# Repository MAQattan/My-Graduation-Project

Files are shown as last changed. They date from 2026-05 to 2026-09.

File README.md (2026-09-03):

# Design and Performance Analysis of a Grid-Tied Solar PV System








A highly optimized engineering design and dynamic performance analysis of a **23.40 kWp grid-tied rooftop solar photovoltaic system**. Designed for a critical banking facility in Aleppo, Syria, this project resolves the structural and electrical matching challenges of urban solar integration under complex spatial constraints.

## 1. Overview / Abstract

This repository contains the full engineering documentation, AutoCAD layouts, Single Line Diagrams (SLD), and PVsyst simulation models for a **23.40 kWp grid-connected rooftop solar PV system** designed to meet the critical loads of a commercial banking facility in Aleppo, Syria. By integrating state-of-the-art **N-Type Hybrid Passivated Back Contact (HPBC)** modules with a **Huawei SUN2000-25KTL-M5 Smart Inverter**, the system maximizes spatial power density on a highly constrained urban roof. Detailed dynamic simulations executed in **PVsyst v7.2.21** demonstrate an exceptional annual yield of **44.02 MWh** and an industry-benchmark **Performance Ratio (PR) of 89.30%**.

## 2. Problem Statement

Commercial and financial facilities in dense urban environments require highly reliable power supplies but are severely limited by **spatial constraints** and complex **architectural obstructions** on rooftops. The primary engineering challenges addressed in this design include:

- **The Rooftop Spatial Bottleneck:** Traditional inter-row spacing layouts designed to avoid mutual shading typically waste **40% to 50% of the usable rooftop area**, capping the maximum allowable installed capacity.
- **Localized Architectural Obstructions:** Permanent structures on the bank's roof—such as a **2.5-meter-high stairwell** and a **1.3-meter-high centralized AC unit**—impose complex, dynamic shadows during peak sun hours. Unmitigated shading triggers severe **mismatch losses** and high risks of localized **hotspot formation**, which degrade module life and threaten system safety.
- **Static Design Limitations:** Standard static hand calculations are insufficient for modeling time-varying, three-dimensional shading profiles and predicting real-world system behavior under extreme seasonal temperature fluctuations.

## 3. Methodology & Software Used

The project adopts a rigorous **five-stage Integrated Engineering Design Cycle**:

```mermaid
flowchart LR
    A["<b>1. Geo-Climatic Study</b><br/><i>(Global Solar Atlas)</i>"] --> B["<b>2. Spatial Design & Shading</b><br/><i>(AutoCAD 3D)</i>"]
    B --> C["<b>3. Thermal Sizing &<br/>Electrical Matching</b>"]
    C --> D["<b>Main DC/AC Cable<br/>Voltage Drop Analysis</b>"]
    D --> E["<b>4. Selectivity-Based<br/>Protections & SLD</b>"]
    E --> F["<b>5. PVsyst Digital Twin<br/>& Dynamic Simulation</b>"]
```

### Software Toolchain & Standards Conformed:

- **Meteonorm 8.0 & Global Solar Atlas:** Used to extract high-resolution, long-term meteorological time series (2006–2013) and geographical solar parameters for Aleppo.
- **AutoCAD:** Utilized for high-precision 2D architectural mapping, structural layouts, and 3D geometric shadow path modeling.
- **PVsyst v7.2.21:** Employed to construct a high-fidelity **Digital Twin** of the system, run dynamic simulations, optimize the DC/AC ratio, and evaluate the final annual system loss tree.
- **IEC 60364-7-712 & EN 50618:** Applied to govern the safety, selection, sizing, and protection of the DC/AC electrical distribution system.
- **IEEE 80:** Followed to design and verify the safety of the low-impedance earthing grid under fault currents.

## 4. System Architecture & Design Details

### 4.1. Geo-Climatic Parameters (Aleppo, Syria)

- **Coordinates:** Latitude: ${} 36.20^\circ\text{ N}$, Longitude:  $37.14^\circ\text{ E}$, Altitude: $379\text{ m}$.
- **Solar Resource Data:** Global Horizontal Irradiation (GHI) = $1930.4\text{ kWh/m}^2/\text{year}$. Global Incident Irradiation on Optimized Tilt ($31^\circ$) (GTI) = $2184.8\text{ kWh/m}^2/\text{year}$.
- **Optimum Tilt & Azimuth:** $31^\circ$ Fixed Plane tilted due South ($0^\circ$ Azimuth).
- **Annual Peak Sun Hours (PSH):** $5.98\text{ hours/day}$.

### 4.2. Spatial Engineering: Terraced Mounting & Shading Geometry

To overcome the urban rooftop spatial bottleneck, a **Terraced (Staircase) Mounting Structure** was engineered. This design aligns the trailing edge of each row with the leading edge of the subsequent row, reducing the inter-row pitch distance to zero ($D = 0$). By raising the subsequent rows step-by-step, the structural design completely neutralizes inter-row mutual shading while achieving an outstanding **areal power density of 119.59 W/m²** over a net exploited rooftop area of **195.67 m²**.

To verify that localized shadows from the AC unit (Height $H = 1.3\text{ m}$) and the Stairwell (Height $H_{stair} = 2.5\text{ m}$) do not impact the active cells of adjacent strings, a rigorous **3D trigonometric verification** was executed for the worst-case scenario (Winter Solstice, Dec 21, 9:00 AM):
$$\text{Minimum Spacing Equation: } D_{min} = D \times \cos(\psi_{Correction})$$
$$\text{Lateral Shading Spacing: } D_{Lat} = D \times \sin(\psi_{Correction})$$

At the critical intersection point on December 21, the maximum vertical shadow height ($H_{shadow}$) from the stairwell was calculated at $0.763\text{ m}$. Because the physical support frame raises the adjacent active module area to a minimum height of $1.173\text{ m}$:

$$H_{shadow}\ (0.763\text{ m}) < H_{collector_min}\ (1.173\text{ m})$$

This confirms the shadow passes entirely below the active cells, eliminating hotspot risks and seasonal mismatch losses.

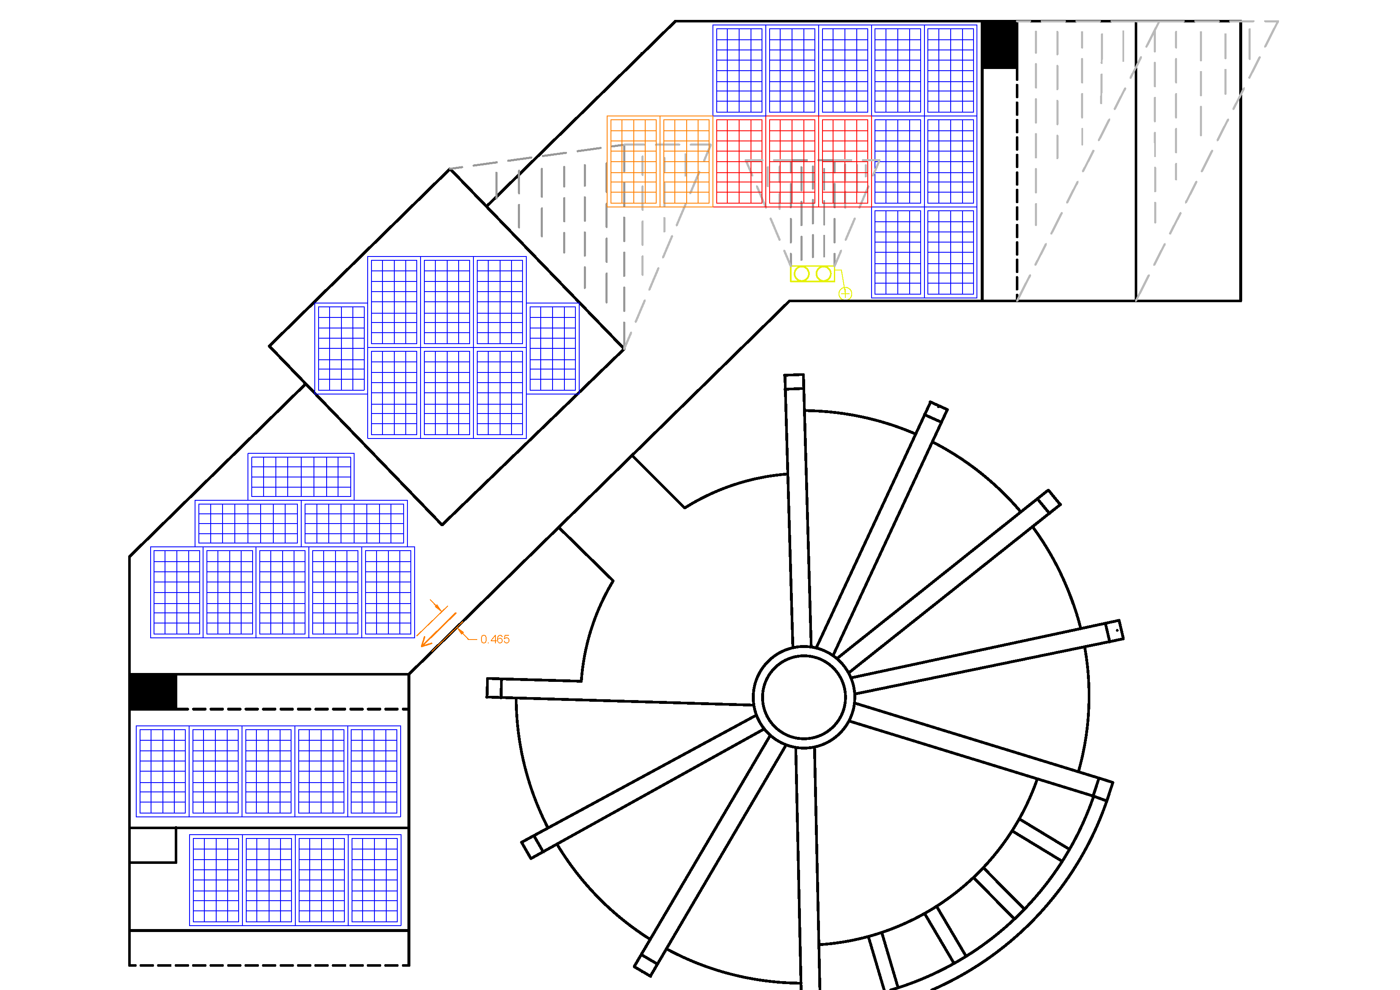
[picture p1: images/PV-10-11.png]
AutoCAD drawing showing shadow projections for the stairwell and the central air conditioning unit.


### 4.3. Photovoltaic Module Specifications

The design utilizes **39 units** of high-efficiency **LONGi Hi-MO 6 Scientist LR5-72HTH-600M** modules featuring N-Type Hybrid Passivated Back Contact (HPBC) technology:

| Electrical Parameter | Symbol | STC Value ($1000\text{ W/m}^2, 25^\circ\text{C}$)  |
| :--- | :--- | :--- |
| Nominal Power | $P_{max}$ | $600\text{ Wp}$ |
| Open-Circuit Voltage | $V_{oc}$ | $52.81\text{ V}$ |
| Optimum Operating Voltage | $V_{mp}$ | $44.66\text{ V}$ |
| Optimum Operating Current | $I_{mp}$ | $13.44\text{ A}$ |
| Short-Circuit Current | $I_{sc}$ | $14.46\text{ A}$ |
| Module Efficiency | $\eta$ | ${} 23.20\%$ |
| Temperature Coefficient of $P_{max}$ | $\gamma_{P}$ | $-0.290\%/^\circ\text{C}$ |

### 4.4. Inverter Selection & DC/AC loading

The system is managed by a three-phase **Huawei SUN2000-25KTL-M5 Smart Inverter**:

- **Rated AC Power:** $25.00\text{ kW}$.
- **DC/AC Loading Ratio (R):** $23.40\text{ kWp} \div 25.00\text{ kW} = 0.936$. This ratio ensures the inverter operates in its peak efficiency window (${} 40\%$ to ${} 80\%$ load) for maximum daily hours.
- **MPPT Inputs:** 2 independent MPPT trackers with a wide operating voltage range ($200\text{ V} - 1000\text{ V}$).
- **Integrated Safety Features:** AI-powered Arc Fault Circuit Interrupter (AFCI) for instant arc detection, Type II DC and AC surge arresters.

### 4.5. Dynamic String Sizing & MPPT Mapping

Dynamic temperature-corrected calculations were performed to establish safe open-circuit voltages at $0^\circ\text{C}$ (extreme winter) and optimum operating voltages at $60^\circ\text{C}$ (extreme summer):

- $V_{oc}$ at $0^\circ\text{C}$ = $56.64\text{ V}$ per module.
- $V_{mp}$ at $60^\circ\text{C}$ = $40.12\text{ V}$ per module.

$$N_{ideal} = \frac{V_{rated_inverter}}{V_{mp_STC}} = \frac{600\text{ V}}{44.66\text{ V}} \approx 13\text{ Modules in Series}$$

The string layout consists of **3 Strings of 13 Modules** each. To isolate local shading losses, a **Multi-MPPT mapping strategy** is implemented:

- **MPPT 1:** 2 strings in parallel (26 modules total) placed in unshaded, safe zones (center and west of the roof).
    - _Max operating current:_ $2 \times 13.44\text{ A} = 26.88\text{ A} \le 30.00\text{ A}$ (Inverter limit).
- **MPPT 2:** 1 string (13 modules) placed in the eastern zone, which experiences temporary lateral shadows from the stairwell. This prevents shading losses on the eastern string from dragging down the performance of the unshaded strings.

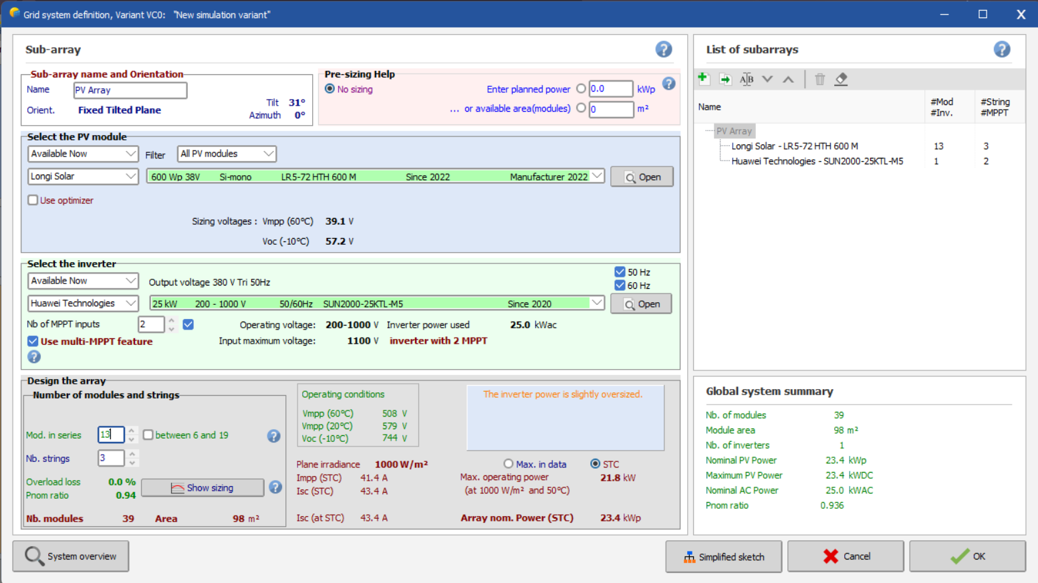
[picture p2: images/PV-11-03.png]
Configuring components and string layout in PVsyst


### 4.6. Cable Sizing, Protections & Grounding Grid

- **DC Cabling:** Specialty solar copper cables conforming to **EN 50618** (4 mm² cross-section). At $45^\circ\text{C}$ ambient, the derated ampacity ($I_{allowable} = 33.37\text{ A}$) easily exceeds the design current ($I_{dc_max} = 18.075\text{ A}$). The total DC voltage drop is optimized at **${} 0.763\%$**, well below the academic ${} 1\%$ limit.
- **AC Cabling:** Low-voltage $4 \times 16\text{ mm}^2\text{ Cu/XLPE/PVC}$ cable (El Sewedy Cables). The derated ampacity of $85.26\text{ A}$ safely coordinates with the protective MCB. The AC voltage drop over a 30m run is kept at **${} 0.717\%$**.
- **Protections (Selectivity-Based Coordination):**
    - _String Fuses:_ $25\text{ A}$, $1000\text{ Vdc}$, gPV class (IEC 60269-6) protecting modules from reverse fault currents.
    - _DC Isolator:_ $32\text{ A}$, $1000\text{ Vdc}$, 2-pole load-break switch.
    - _Inverter Output MCB:_ $50\text{ A}$ nominal, 4-pole, Curve C, $10\text{ kA}$ breaking capacity.
    - _Main Bank Circuit Breaker:_ $63\text{ A}$, 4-pole MCCB, $\ge 25\text{ kA}$ breaking capacity.
- **Earthing Grid (IEEE 80 & Dwight’s Formula):** Designed for a target resistance of $R_e \le 3.98\ \Omega$ ($< 5\ \Omega$ standard code). The grid consists of **10 vertical flemish-copper-clad steel rods** (Length $L = 2.5\text{ m}$, Diameter $d = 16\text{ mm}$) spaced 5m apart, buried at 0.8m, and interconnected with a $50\text{ mm}^2$ bare copper conductor.

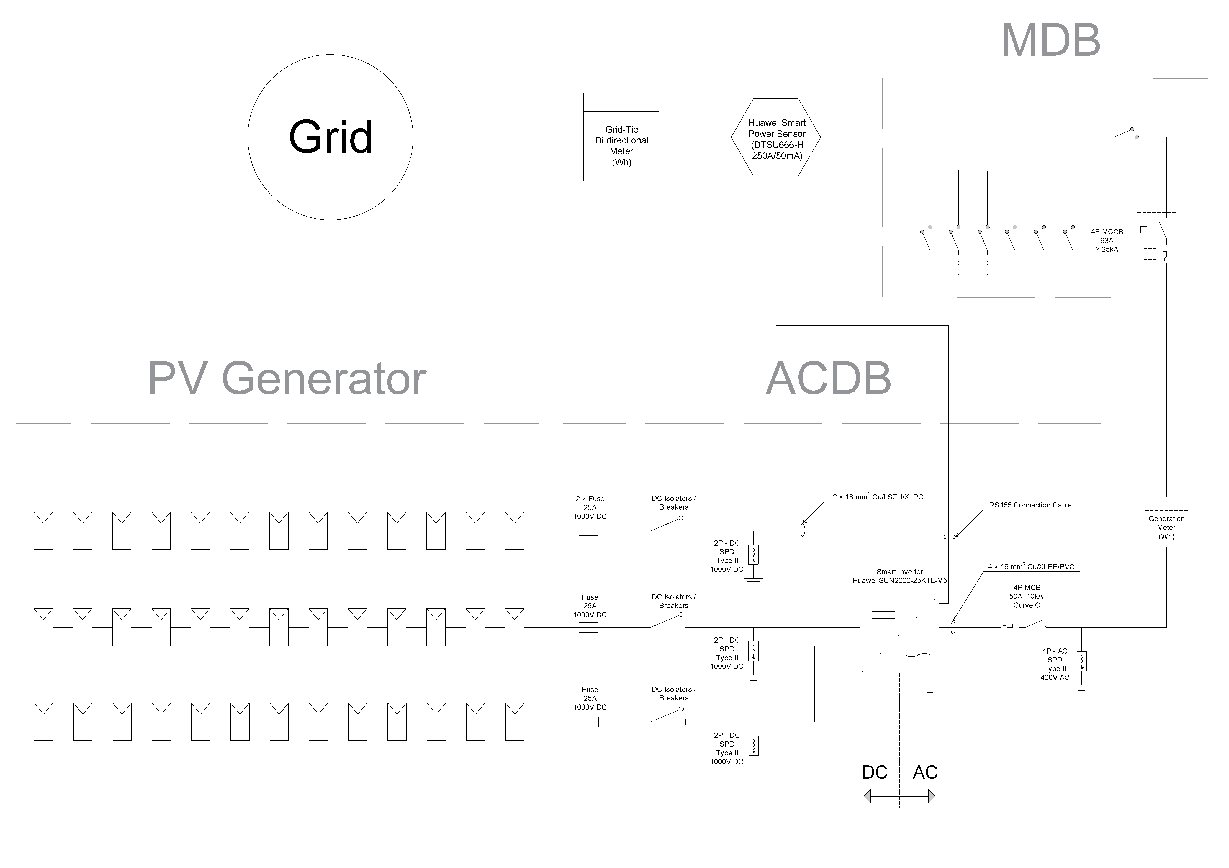
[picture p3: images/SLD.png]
Single line diagram

> **[📄 Click here to download or view the complete single-line diagram in high-resolution PDF format.](images/SLD.pdf)**

### 4.7. Bill of Materials (BOM)

The following table summarizes the primary structural and electrical equipment selected for this grid-tied installation:

|Item|Component|Technical Specification|Proposed Manufacturer|Qty|Unit|
|:-:|:--|:--|:-:|:-:|:-:|
|**1**|PV Modules|N-Type HPBC, 600 Wp, 23.2% Efficiency, LR5-72HTH-600M|LONGi Solar|39|Pcs|
|**2**|Grid-Tied Inverter|25 kW AC rated, 2 MPPTs, SUN2000-25KTL-M5|Huawei|1|Unit|
|**3**|DC String Fuses|25 A, 1000 Vdc, gPV class, 10x38 mm|Schneider / ABB|6|Pcs|
|**4**|DC MCB/Isolators|2-Pole, 32 A, 1000 Vdc|Schneider / ABB|3|Pcs|
|**5**|DC Combiner Box|IP66 Enclosure with DIN rail, UV-Stabilized Polycarbonate|Hensel|1|Unit|
|**6**|Solar DC Cable|4 mm² cross-section, tinned copper, double-insulated XLPO|KBE / Prysmian|300|Meters|
|**7**|AC Circuit Breaker|4-Pole, 50 A, Curve C, 10 kA|Schneider / ABB|1|Pcs|
|**8**|Main AC Cable|4 x 16 mm² Cu/XLPE/PVC, 0.6/1 kV|El Sewedy Cables|50|Meters|
|**9**|Smart Power Sensor|3-Phase, DTSU666-H 250A/50mA, Modbus-RTU|Huawei|1|Unit|
|**10**|Mounting Structure|Terraced / Stepped design, Anodized Al Rail, HDG Steel frame|Custom Structural|1|Lot|
|**11**|Earthing System|10 solid copper rods, 50 mm² bare copper cable, inspection pit|Custom Electrical|1|Lot|

## 5. Results & Analysis

The simulated performance metrics of the grid-tied system:

### 📊 PVsyst Simulation Yield Indicators (Aleppo Site)

| Metric | Symbol | Value | Unit |
| :--- | :---: | :---: | :---: |
| **Annual Energy Injected** | $E_{\text{Grid}}$ | **44.02**  | MWh/year |
| **Specific System Production** | — |  **1881**  | kWh/kWp/year |
| **System Performance Ratio** | $PR$ | **89.30%** | — |
| **Avg. Daily Useful Energy** | $Y_f$ |  **5.15**  | kWh/kWp/day  |

### 5.1. Energy Yield and PR Dynamics

- **Annual Energy Yield ($E_{Grid}$):** The system feeds **$44.02\text{ MWh/year}$** of clean power into the bank's local distribution network and the public utility grid.
- **Performance Ratio (PR):** Achieves an annual **${} 89.30\%$ PR**. Under cold, clear sky winter conditions (January), the system hits peak performance with a **${} 94.80\%$ PR** due to reduced module thermal degradation. Conversely, high summer temperatures (July) degrade $V_{mp}$, driving the PR down to **${} 85.80\%$**.

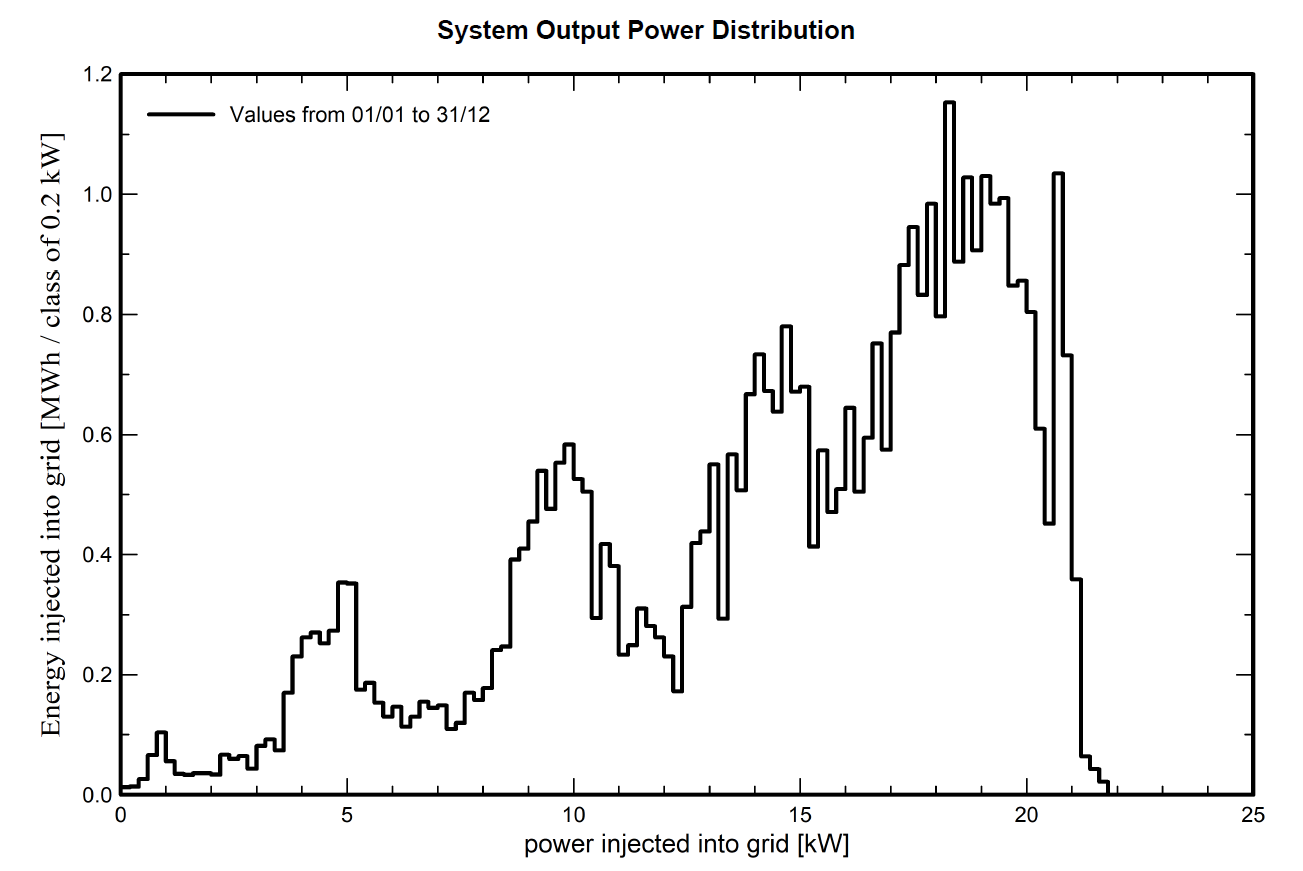
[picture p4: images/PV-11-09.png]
System Output Power Distribution


### 5.2. Daily Normalized Performance

- **Daily Useful Energy ($Y_f$):** Evaluated at **$5.15\text{ kWh/kWp/day}$**, meaning each installed kWp yields over 5 hours of full-load equivalent production daily.
- **Collection Losses ($L_c$):** **$0.52\text{ kWh/kWp/day}$** is lost due to thermal module degradation, minor dust buildup, and wiring resistance.
- **System Losses ($L_s$):** Just **$0.09\text{ kWh/kWp/day}$** is lost during inverter DC-to-AC conversion.

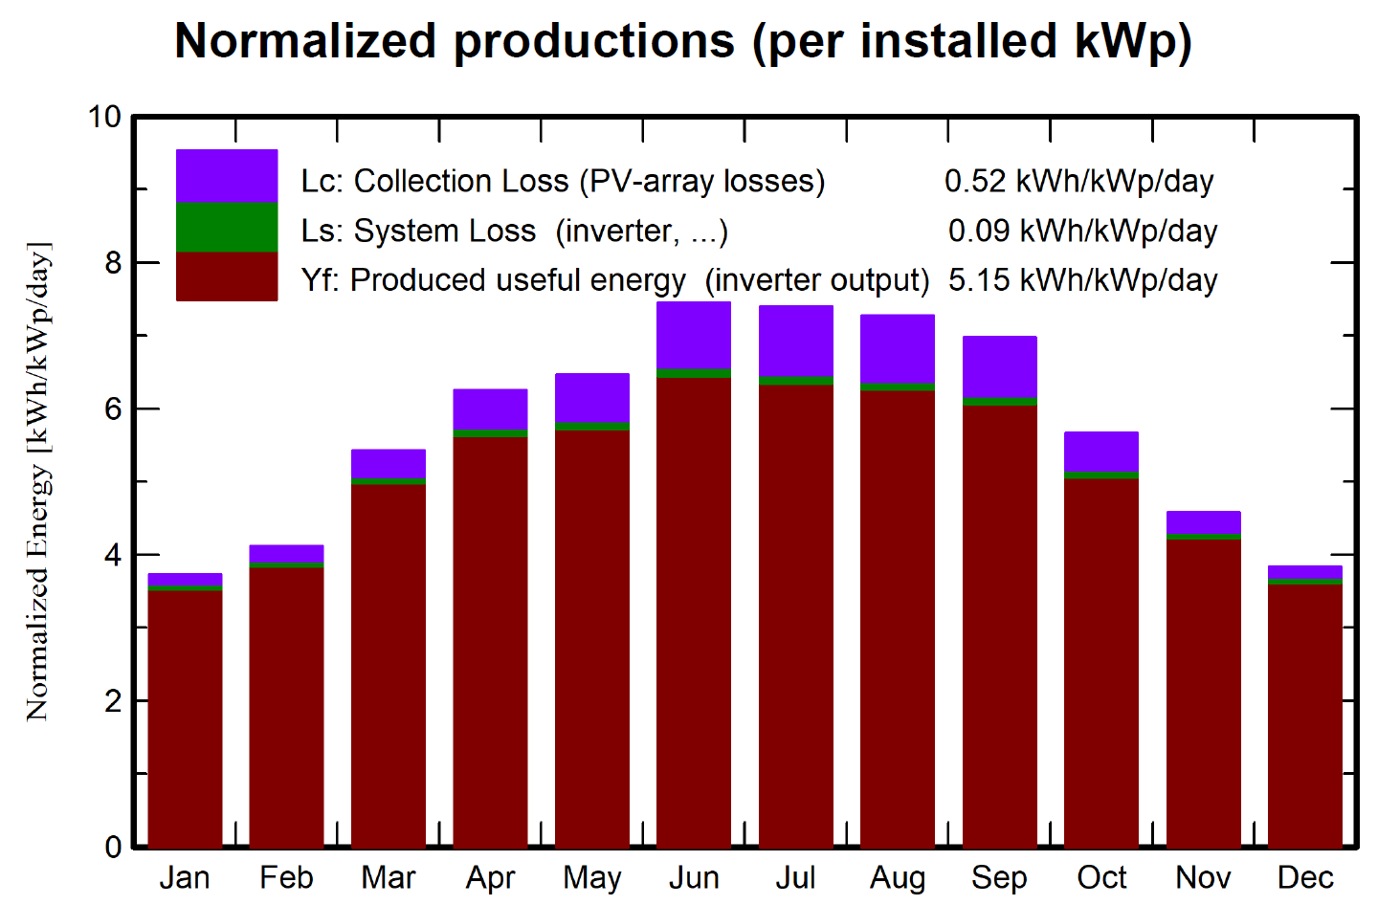
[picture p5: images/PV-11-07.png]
Normalized productions


### 5.3. PVsyst Loss Diagram Breakdown

The complete transformation chain from raw irradiance to useful grid energy, as simulated by the PVsyst loss model:

1. **Global Horizontal Irradiation (GHI):** $1862\text{ kWh/m}^2$.
2. **Tilt Transposition Gain (to $31^\circ$):** **${} +13.10\%$**.
3. **Effective Global Incident Radiation (GTI):** $2071\text{ kWh/m}^2$.
4. **Nominal PV Array Energy (at STC):** $48.63\text{ MWh}$.
5. **PV Loss due to Temperature:** **${} -4.64\%$** (highly stabilized by LONGi's low thermal coefficient).
6. **Mismatch Loss (modules and strings):** **${} -2.10\%$** (mitigated successfully by the parallel Multi-MPPT mapping layout).
7. **Ohmic Wiring Loss (DC cabling):** **${} -0.73\%$** (validating the selection of the $4\text{ mm}^2$ solar cable cross-section).
8. **Inverter Conversion Efficiency Loss:** **${} -1.72\%$** (driven by the high ${} 98.40\%$ peak efficiency of the Huawei unit).
9. **Final Energy Injected to Grid:** **$44.02\text{ MWh}$**.

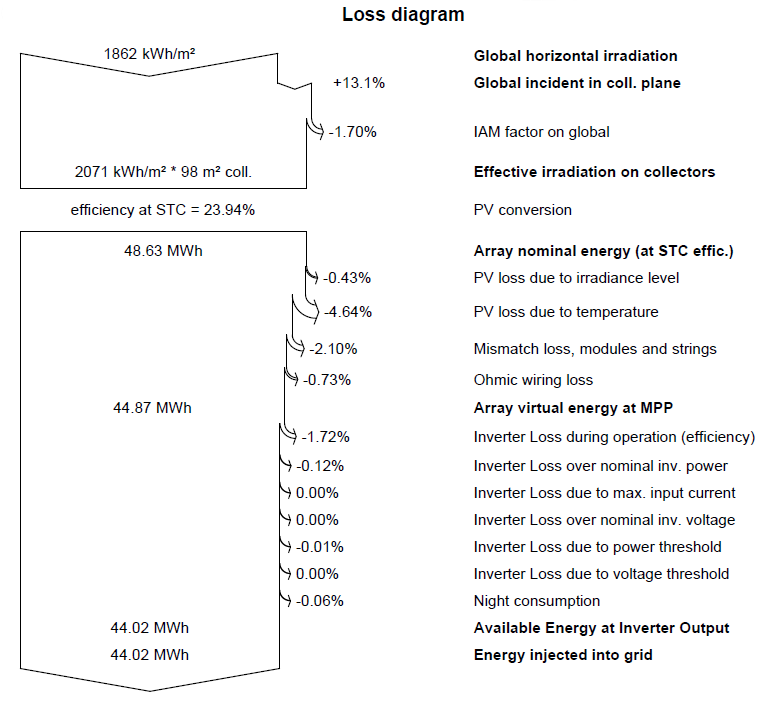
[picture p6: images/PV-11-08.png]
Loss Diagram


## 6. Conclusion & Future Work

### 6.1. Design Accomplishments

- **Spatial Optimization:** The custom **Terraced Mounting** structure bypassed the typical urban spacing penalty, reclaiming **${} 40\%$ to ${} 50\%$ of lost rooftop space** to establish an excellent spatial power density of **$119.59\text{ W/m}^2$**.
- **Electrical Selectivity & Isolation:** Isolating the shade-affected eastern string on a dedicated MPPT channel successfully confined mismatch losses to just **${} 2.10\%$**, ensuring the system maintains a benchmark **${} 89.30\%$ PR**.
- **Thermal & Compliance Success:** The tinned copper solar and AC cabling layouts kept voltage drop parameters below **${} 0.85\%$**, ensuring complete compliance with standard code guidelines.

### 6.2. Future Work Recommendations

- **Hybrid Configuration (Battery Storage Integration):** To prevent grid-tie dropouts under regional utility blackout events, integrating a hybrid battery backup loop would secure continuous supply for critical banking operations.
- **Bifacial Module Upgrades:** If roof reflectivity is improved by applying a white reflective coating to elevate the current $0.20$ albedo, upgrading to bifacial modules would enable up to ${} 5\% - 10\%$ additional back-side generation gains.

## 7. Project Metadata

- **Student/Author:** Muhammad Ali Qattan (محمد علي قطان)
- **Academic Institution:** University of Aleppo, Faculty of Electrical and Electronic Engineering, Department of Electrical Power Engineering (2026 CE / 1448 AH)
- **Project Supervisor:** Dr. Karima Sukkar (د. كريمة سكر)

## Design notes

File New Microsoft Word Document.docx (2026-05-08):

جميل جدًا — فكرة منظومة شمسية مرتبطة بالشبكة وتحليل أدائها باستخدام ETAP عملية، قابلة للتنفيذ خلال فصل دراسي، وممتازة كـ مشروع تخرج (جمع بين جانب تطبيقي ومراجع عملية). سأعطيك خطة مفصلة خطوة-بخطوة تقدر تطبّقها بسرعة، مع مخرجات واضحة تعرضها للمشرف وللجنة.

1) هدف المشروع (مختصر وواضح)

تحليل تصميم منظومة طاقة شمسية (PV) متصلة بالشبكة لموقع محدد، وتقييم أداء المنظومة كهربائيًا (تدفق قدرة، جهد، تناظر/لا تناظر، قصر، تأثير على جودة الطاقة) تحت ظروف تشغيل مختلفة، واقتراح تحسينات لرفع الكفاءة والموثوقية.

2) نطاق العمل (Scope)

- نظام PV بقدرة تقريبية تختارها (مثلاً 50 kW — يمكنك تعديلها حسب متطلبات الكلية والبيئة).
- ربط المنظومة إلى شبكة توزيع محلية نموذجية (محول/لوحات/حمل).
- تحليلات في ETAP: Load Flow, Short Circuit, Voltage Profile, Protection coordination (اختياري)، و(إن أمكن) Harmonic/Power Quality.
- دراسات سيناريو: ساعات ذروة الشمس، غيوم/انخفاض توليد، زيادة حمل مفاجئة، فصل الشبكة (فشل الشبكة) إن أردت.

3) المتطلبات والأدوات

- ETAP (نسخة طلابية أو مؤسسية).
- بيانات المكونات: مواصفات الألواح (Pmax, Voc, Isc, Vmp, Imp)، محوّلات (inverters) مواصفات الربط للشبكة، محول رفع/خفض إن وُجد، خواص الكابل والحمل.
- بيانات الطقس/الشمس للموقع: إشعاع شمسي نموذجي ودرجة حرارة (تؤثر على أداء ال-PV). إن لم تتوفر بيانات محلية يمكنك استخدام جدول قياسي أو بيانات من محطة قريبة.
- مُعطيات الشبكة: جهد التغذية، قصيرة التماس المألوفة (fault level) أو مراجع لاختبار الاستقرار.
- (اختياري لاحقًا) MATLAB لو أردت مقارنة تحكم أو محاكاة ديناميكية أو دمج خوارزميات تحسين.

4) خطوات تنفيذ المشروع بالتفصيل

1. اختيار موقع وفرضيات التصميم: حدد موقع أو استخدم موقع جامعتك. اختَر سعة المنظومة (مثلاً 50 kW). اجمع بيانات الإشعاع والحمولة.
2. تجميع مواصفات المكونات: لوحة شمسية (نمذجة سلسلة/مواصفات)، محول الشبكة (inverter) مع خصائص الربط، محول شبكي إن وُجد، الكابلات، قواطع الحماية.
3. تصميم خطي أولي للمنظومة (single-line diagram): موضح فيه مصدر التغذية الشبكية، نقطة الربط (PCC)، اللوحات، المحول، العواكس، الأحمال.
4. بناء نموذج الشبكة في ETAP: أنشئ الشبكة، أدخل مواصفات المحطات، الكابلات، الأحمال، ونقطة الربط.
5. تشغيل Load Flow تحت حالات متعددة:
  - حالة نهار ذروة (PV عند قدرة قصوى).
  - حالة غيوم/إنتاج منخفض.
  - زيادة حمل مفاجئ. حلل التغير في الجهود، الخسائر، وحصة التغذية من الشبكة.
6. تشغيل Short Circuit وتحليل القيم عند نقاط مختلفة، وتحقق من قدرة القواطع والمعدات.
7. (إن أمكن) تحليل حماية وتنسيق القواطع للتأكد من التنسيق الزمني والقطع الآمن.
8. (اختياري) تحليل جودة الطاقة: هارمونك، توافقيات عند الربط بسبب inverters.
9. استنتاجات واقتراحات: تحسين موقع التوصيل، زيادة/تقليل سعة العاكس، إدخال سعة تخزينية (مقارنة نظرية)، أو تعديل معلمات الحماية.
10. كتابة التقرير وإعداد عرض (PowerPoint) مع مخططات، جداول نتائج، ورسومات ETAP (Single-line, voltage profiles, %losses).

5) مخرجات المشروع التي يجب أن تعرضها

- مخطط أحادي الخط (single-line diagram).
- جداول نتائج Load Flow لكل سيناريو (جهود، تيارات، خسائر).
- تحليل Short Circuit (تيارات القصر) ومطابقتها لمواصفات القواطع.
- رسوم بيانية: منحنيات قدرة PV عبر اليوم، مقارنة حالات قبل وبعد التحسين.
- توصيات عملية (مثلاً: أفضل نقطة توصيل، حجم محول/عاكس أمثل، اقتراح مكثفات لتحسين معامل القدرة أو إضافة بطاريات).
- ملف ETAP (نموذج المشروع) لعرضه للمشرف إذا طُلب.

6) خطة زمنية مُقترحة للفصل الأول (قابلة للتعديل)

(افترض فصل ≈ 10-12 أسبوعاً)

- أسبوع 1: تحديد الفكرة، نطاق المشروع، وجمع البيانات الأولية، موافقة المشرف.
- أسابيع 2–3: جمع مواصفات المكونات وكتابة الجزء النظري (مقدمة، مراجعة أدبيات قصيرة).
- أسابيع 4–6: بناء النموذج في ETAP وتشغيل حالات Load Flow الأساسية.
- أسابيع 7–8: اختبارات قصر، تحليل الحماية (إن أمكن)، وتوليد النتائج.
- أسبوع 9: تحليل النتائج، كتابة الخلاصة والتوصيات.
- أسبوع 10: إعداد التقرير النهائي والعرض التقديمي وتسليم الملفات للمشرف.

بهذه الخطة يمكنك إنهاء المشروع قبل نهاية الفصل الأول كما نصحك أصدقاؤك.

7) نصائح عملية لسهولة التنفيذ

- ابدأ مبكرًا في الحصول على نسخة ETAP (اطلع إن كانت الكلية توفر ترخيصًا طلابيًا).
- لا تدخل في تعقيدات غير ضرورية (مثل نمذجة ديناميكية متقدمة) إن كنت تسعى للإتمام سريعًا. ركّز على Load Flow وShort Circuit لأنهما الأكثر وزناً في التقييم.
- استخدم قيم ومواصفات جاهزة من أوراق بيانات المكونات — ليس مطلوبًا أن تصمم لوحة بنفسك من الصفر.
- وثّق كل فرضية (مثلاً: افترض إشعاع 800 W/m² عند الظهيرة، أو معامل نواتج PV عند 0.9) — المشرف يحب الشفافية في الفرضيات.
- أظهر فهمك للقيود: losses, voltage rise due to PV injection, reverse power flow.

8) أفكار تطور لاحقًا (لو أردت تمييز المشروع)

- مقارنة نتائج ETAP مع محاكاة بسيطة في MATLAB للـ power output اليومي.
- اقتراح نظام إدارة طاقة EMS بسيط (نظري أو محاكاة) لإدخال بطارية لتحسين الاستجابة.
- تطبيق خوارزمية تحسين (مثلاً لتحديد حجم العاكس الأمثل) لاحقًا عندما تتعلم برمجة/AI.

9) قالب بسيط لفصول التقرير

1. المقدمة والأهداف
2. مراجعة أدبيات قصيرة (منظومات PV متصلة بالشبكة، مشكلات شائعة)
3. مواصفات الموقع والمكونات والفرضيات
4. نموذج ETAP (شرح أحادي الخط)
5. نتائج التحليل (Load Flow, Short Circuit, غيرها)
6. مناقشة وتفسير النتائج
7. توصيات وخطة مستقبلية
8. ملاحق: جداول بيانات، ملفات ETAP، رسومات إضافية

لو تحب أقدملك الآن:

1. قائمة مكوّنات نموذجية (نماذج ألواح وعاكسات، قيم كابلات، أمثلة أرقام) جاهزة لتدخلها في ETAP، أو
2. مخطط عملي أحادي الخط جاهز يمكنك نسخه وتعديله في ETAP، أو
3. نموذج جدول سيناريوهات للاختبار (قوائم الحالات التي تشغّلها في ETAP مع القيم المتوقعة)،

اختر أي واحد منهم أبدأ أحضره لك فورًا — وسأقدمه بصيغة قابلة للاستخدام مباشرة.

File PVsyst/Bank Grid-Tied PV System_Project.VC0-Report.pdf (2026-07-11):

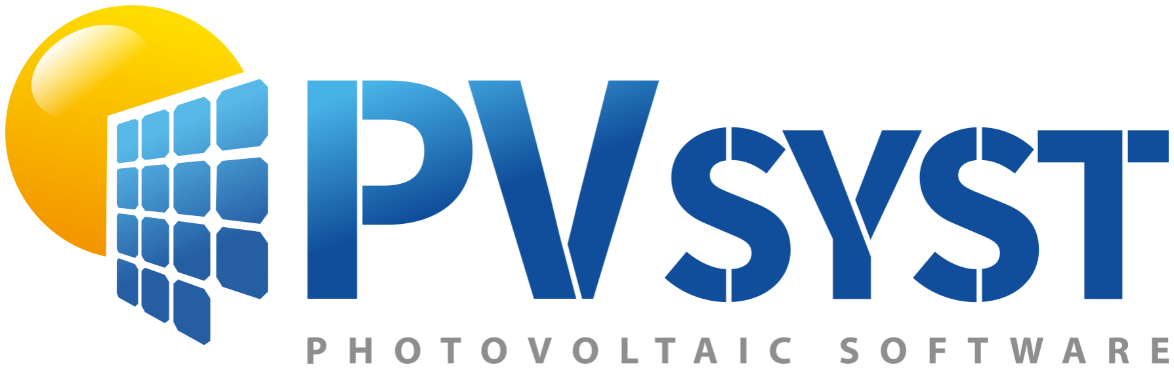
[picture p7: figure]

## Version 7.2.21

# PVsyst - Simulation report

# Grid-Connected System

# Project: Bank Grid-Tied PV System

## Variant: New simulation variant No 3D scene defined, no shadings System power: 23.40 kWp Aleppo - Bank Grid-Tied PV System Site - Syria

Author

PVsyst V7.2.21
VC0, Simulation date:
10/07/26 10:05
with v7.2.21

## Project: Bank Grid-Tied PV System

### Variant: New simulation variant

PVsyst Licensed to

### Project summary

Geographical Site
Aleppo - Bank Grid-Tied PV System Site Syria

Situation
Latitude
Longitude
Altitude
Time zone

36.20
37.14
379
UTC+3

°N
°E
m

Project settings
Albedo | 0.20

Meteo data
Aleppo - Bank Grid-Tied PV System Site Meteonorm 8.0 (2006-2013), Sat=100% - Synthetic

### System summary

Grid-Connected System | No 3D scene defined, no shadings

PV Field Orientation
Fixed plane
Tilt/Azimuth | 31 / 0 °

Near Shadings
No Shadings

User's needs
Unlimited load (grid)

System information
PV Array
Nb. of modules
Pnom total

39
23.40

units
kWp

Inverters
Nb. of units
Pnom total
Pnom ratio

1
25.00
0.936

unit
kWac

### Results summary

Produced Energy | 44.02 MWh/year | Specific production | 1881 kWh/kWp/year Perf. Ratio PR | 89.30 %

### Table of contents

Project and results summary
General parameters, PV Array Characteristics, System losses Main results
Loss diagram
Special graphs

2
3
4
5
6

PVsyst V7.2.21
VC0, Simulation date:
10/07/26 10:05
with v7.2.21

### General parameters

Grid-Connected System | No 3D scene defined, no shadings

PV Field Orientation
Orientation
Fixed plane
Tilt/Azimuth | 31 / 0 °

Sheds configuration
No 3D scene defined

Models used
Transposition
Diffuse
Circumsolar

Perez
Perez, Meteonorm
separate

Horizon
Free Horizon

Near Shadings
No Shadings

User's needs
Unlimited load (grid)

### PV Array Characteristics

PV module
Manufacturer
Model

Longi Solar
LR5-72 HTH 600 M
(Custom parameters definition)
Unit Nom. Power | 600 Wp
Number of PV modules
Nominal (STC)
Modules

39
23.40
3 Strings x 13

units
kWp
In series
At operating cond. (50°C)
Pmpp
U mpp
I mpp

21.78
526
41

kWp
V
A

Inverter
Manufacturer
Model

Huawei Technologies
SUN2000-25KTL-M5
(Custom parameters definition)
Unit Nom. Power | 25.0 kWac
Number of inverters Total power | 2 * MPPT 50% 1
| 25.0 unit
| kWac
Operating voltage Max. power (=>55°C) Pnom ratio (DC:AC) | 200-1000
| 27.5
| 0.94 V
| kWac

Total PV power
Nominal (STC)
Total
Module area
Cell area

23
39
98.1
93.9

kWp
modules
m²
m²

Total inverter power
Total power
Number of inverters
Pnom ratio

25
1
0.94

kWac
unit

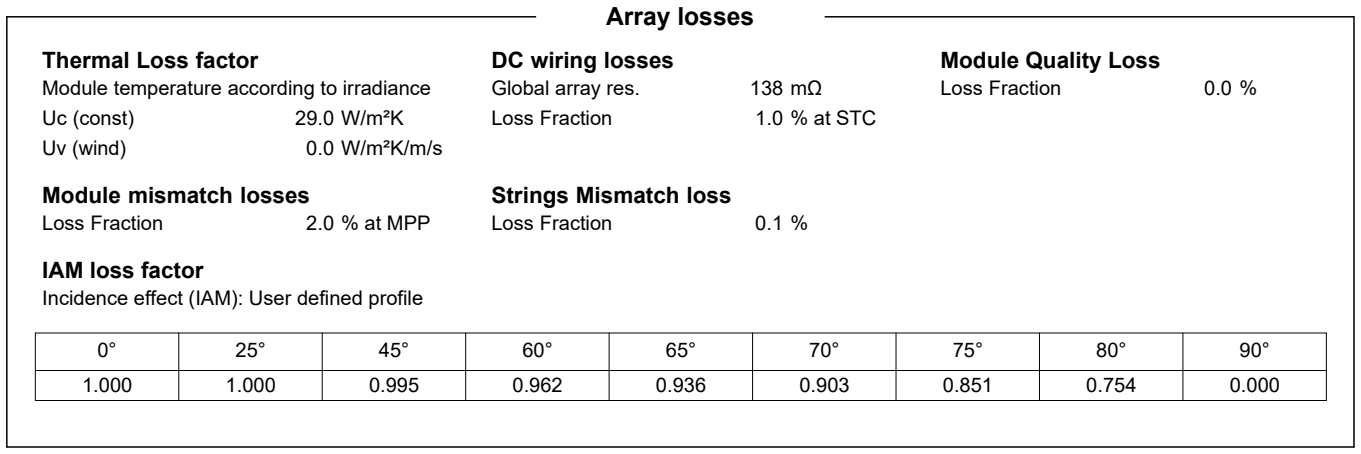
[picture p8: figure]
Array losses; Thermal Loss factor; Module temperature according to irradiance; Uc (const); Uv (wind); W/m²K; W/m²K/m/s; DC wiring losses; Global array res.; Loss Fraction; % at STC; Module Quality Loss; Module mismatch losses; 2.0 % at MPP; Strings Mismatch loss; IAM loss factor

Incidence effect (IAM): User defined profile

PVsyst V7.2.21
VC0, Simulation date:
10/07/26 10:05
with v7.2.21

### Main results

System Production
Produced Energy | 44.02 MWh/year | Specific production
| | Performance Ratio PR

1881
89.30

kWh/kWp/year
%
Normalized productions (per installed kWp) | Performance Ratio PR

Balances and main results

| GlobHor kWh/m² | DiffHor kWh/m² | T_Amb °C | GlobInc kWh/m² | GlobEff kWh/m² | EArray MWh | E_Grid MWh | PR ratio
January February March April May June July August September October November December | 76.2 86.1 140.7 174.3 208.2 243.4 244.1 218.7 177.8 131.0 89.3 72.1 | 36.13 40.64 61.71 68.39 81.87 57.51 60.28 58.04 43.99 44.53 32.13 30.01 | 5.47 7.27 11.73 16.36 22.15 27.34 30.62 30.24 25.82 20.48 11.99 6.78 | 115.5 115.1 168.1 187.4 200.5 223.5 229.4 225.5 209.3 175.7 137.5 118.8 | 113.9 113.4 165.5 184.2 196.4 218.7 224.7 221.5 206.1 173.2 135.7 117.2 | 2.611 2.568 3.680 4.026 4.232 4.611 4.687 4.623 4.334 3.743 3.027 2.676 | 2.563 2.521 3.615 3.954 4.158 4.526 4.604 4.542 4.258 3.677 2.972 2.627 | 0.948 0.936 0.919 0.902 0.886 0.865 0.858 0.861 0.869 0.894 0.924 0.945
Year | 1862.0 | 615.22 | 18.08 | 2106.4 | 2070.5 | 44.818 | 44.017 | 0.893

Legends
GlobHor
DiffHor
T_Amb
GlobInc
GlobEff

Global horizontal irradiation Horizontal diffuse irradiation
Ambient Temperature
Global incident in coll. plane
Effective Global, corr. for IAM and shadings

EArray
E_Grid
PR

Effective energy at the output of the array Energy injected into grid
Performance Ratio

PVsyst V7.2.21
VC0, Simulation date:
10/07/26 10:05
with v7.2.21

### Loss diagram

1862 kWh/m² | Global horizontal irradiation
+13.1% | Global incident in coll. plane
-1.70% | IAM factor on global
2071 kWh/m² * 98 m² coll. | Effective irradiation on collectors
efficiency at STC = 23.94% | PV conversion
48.63 MWh | Array nominal energy (at STC effic.)
-0.43% | PV loss due to irradiance level
-4.64% | PV loss due to temperature
-2.10% | Mismatch loss, modules and strings
-0.73% | Ohmic wiring loss
44.87 MWh | Array virtual energy at MPP
-1.72% | Inverter Loss during operation (efficiency)
-0.12% | Inverter Loss over nominal inv. power
0.00% | Inverter Loss due to max. input current
0.00% | Inverter Loss over nominal inv. voltage
-0.01% | Inverter Loss due to power threshold
0.00% | Inverter Loss due to voltage threshold
-0.06% | Night consumption
44.02 MWh | Available Energy at Inverter Output
44.02 MWh | Energy injected into grid

### Special graphs

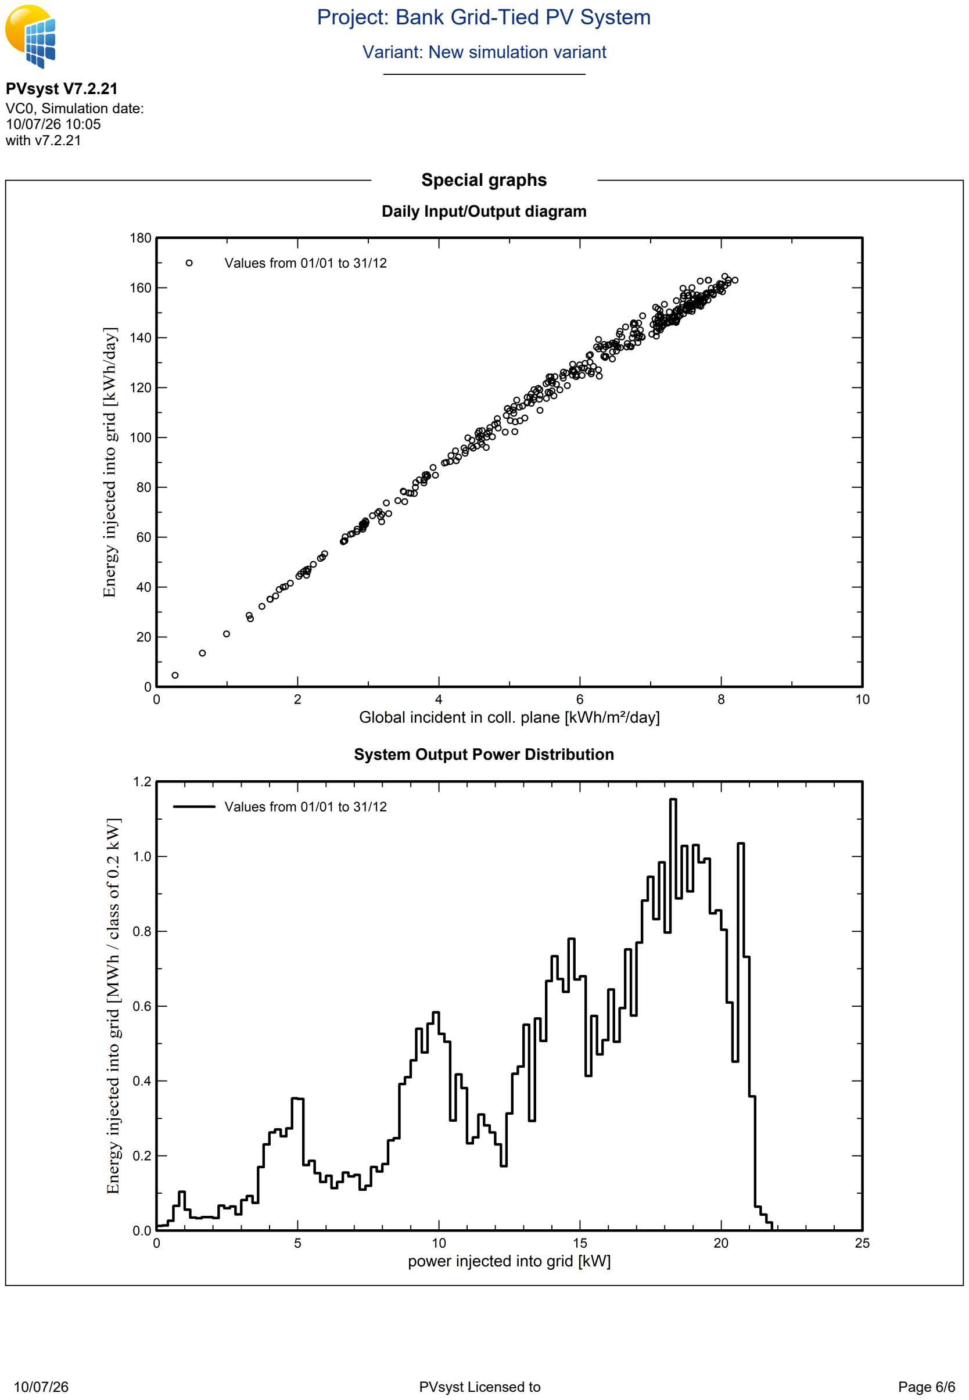
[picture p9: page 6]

PVsyst V7.2.21
VC0, Simulation date:
10/07/26 10:05
with v7.2.21

Daily Input/Output diagram

System Output Power Distribution

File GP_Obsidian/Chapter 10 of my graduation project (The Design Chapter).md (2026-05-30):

## 10 - 1 مقدمة

بناءً على ما تم تأسيسه في الفصول السابقة من صياغة للإطار النظري المتكامل، واستعراض الدراسات المرجعية المعمقة المتعلقة بجودة الطاقة الكهربائية وتحليل طبيعة الأحمال غير الخطية وتأثيرها السلبي على الشبكة، يأتي هذا الفصل العاشر ليمثل الجسر التنفيذي والعملي للمشروع. إذ ينتقل البحث هنا من فضاء الدراسة المرجعية والتحليل النظري إلى مرحلة الهندسة التطبيقية الدقيقة، عبر تصميم وتطبيق منظومة طاقة كهروضوئية مرتبطة بالشبكة ومخصصة لتغذية منشأة مصرفية حيوية، بما يضمن تحسين كفاءة الطاقة وتلبية المتطلبات التشغيلية الواقعية.

### المنهجيات الحاكمة والمعايير الهندسية

خضع المسار التصميمي في هذا الفصل لمنهجية هندسية صارمة ترتكز على **التصميم بناءً على المساحة المتاحة (Area-based Design)**. ونظراً للمحدودية الفيزيائية للموقع، تم توجيه هذه المنهجية نحو هدف **الاستغلال الأقصى للإنتاجية النوعية (Maximize Specific Yield)**. ولم يقف التصميم عند حدود التوزيع التقليدي، بل تم تبني منهجية **الهياكل المتدرجة (Terraced / Stepped Mounting Structures)** كخيار ميكانيكي وإنشائي مبتكر يتيح إلغاء المسافات البينية الميتة ورفع الكثافة الطاقية للمتر المربع الواحد إلى حدها الأقصى.

ولضمان الموثوقية الأكاديمية والسلامة التشغيلية، تم الاحتكام في كافة مراحل الحساب والتوصيف إلى حزمة من المعايير والأكواد الدولية، أبرزها:

- المعيار الدولي الكهروتقني **IEC 60364-7-712** الحاكم لتمديدات وحمايات الأنظمة الكهروضوئية.
    
- المواصفة الدولية **IEC 60269-6 (gPV)** الخاصة بمصاهر حماية الجانب المستمر ضد تيارات القصر العكسية.
    
- معايير الكود الدولي **IEC 60364-5-52** لتطبيق معاملات التصحيح الحراري وظروف تمديد الموصلات.
    
- الاعتماد على قواعد بيانات منصة **Global Solar Atlas** ومخططات مسار الشمس الصادرة عن مختبر **UO Solar Radiation** لتأمين دقة المدخلات الإشعاعية والمناخية.

### القيود والمحددات الأساسية

تحركت الأفكار التصميمية في هذا الفصل عبر حقل مليء بالقيود والمحددات البيئية والمعمارية التي فرضت طوقاً حول خيارات التصميم، وتمت معالجتها هندسياً عبر المحددات التالية:

- **القيود المكانية والمعمارية:** تمثلت في ضيق مساحة السطح الصافية المتاحة للدراسة والتي بلغت **129 م²**، بالإضافة إلى تحدي انحراف المحور الطولي للمبنى بزاوية **45°** عن الجنوب الجغرافي الحقيقي.
    
- **العوائق الإنشائية وظلال البيئة الحضرية:** فرض وجود غرفة الدرج ووحدات التكييف المركزية قيوداً حرجة تتعلق بالتظليل الأفقي والجانبي المتبادل، مما هدد بخروج مساحات واسعة من السطح عن الخدمة.
    
- **القيود المناخية والحرارية:** ارتبطت بالتقلبات الحرارية الحادة لموقع الدراسة في مدينة حلب، حيث تم الحساب عند حالات حرارية متطرفة تتراوح بين **0°C** شتاءً و**60°C** صيفاً، وهي ظروف تؤثر فيزيائياً بشكل عكسي على جهود الألواح وتحدد نوافذ تشغيل العاكس.

### تدرج الأفكار خلال الفصل

ينساب هذا الفصل بسياق سردي مرن يتدرج منطقياً من المحيط الخارجي العام وصولاً إلى التفاصيل الكهربائية الدقيقة في العمق. يبدأ الفصل بـ **الطور الأول** الذي يؤسس "الأساس المعياري والمناخي"، حيث يتم تقييم الموقع جغرافياً واستخلاص المورد الشمسي وساعات الذروة المتاحة. ومن البيانات المناخية، يتدفق السياق نحو **الطور الثاني** ليتناول "التصميم الهيكلي والميكانيكي"؛ وهنا تتحول الأرقام المناخية إلى مجسمات فيزيائية عبر اختيار اللوح الشمسي المناسب وتحديد زوايا ميله وتفكيك معضلة الظلال عبر هندسة أبعاد المسافات البينية والجانبية بالعلاقات المثلثية.

بعد ضبط الفراغ والميكانيك، ينتقل الفصل بسلاسة إلى **الطور الثالث** ليغوص في "المواءمة والتحجيم الكهربائي"؛ فيربط مخرجات المصفوفة الميكانيكية بالعاكس الذكي، محللاً سلوك الجهود والتيارات تحت وطأة الحالات الحرارية المتطرفة لضمان استقرار التشغيل. وأخيراً، يختتم الفصل حركته بـ **الطور الرابع** المخصص لـ "الحمايات والترابط الكهربائي"، حيث تُتوج الحسابات بتصميم الشرايين الكهربائية (الكابلات) وصمامات الأمان (المصاهر والقواطع) وفق مبدأ الانتقائية الصارمة، ليقفل الفصل دائرة التصميم من فكرة الشمس وحتى أمان الشبكة.

### المخرجات الدقيقة للفصل

يلخص هذا الفصل مجهوده الهندسي والتطبيقي في المخرجات الحاسمة التالية صيغت بصيغة أفعال واضحة:

- **يحلل** المورد الشمسي لموقع الدراسة مستخرجاً ساعات الذروة الشمسية الفعالة بقيمة **5.98 ساعة/يوم** ومعامل أداء عام للمنظومة يبلغ **79%**.
    
- **يحدد** زاوية الميل المثبتة المثلى للألواح عند **31°** مع توجيهها نحو الجنوب الجغرافي تماماً لضمان أعلى التقاط طاقي سنوي.
    
- **يحسب** أبعاد وفواصل الظلال المتبادلة والجانبية للعوائق (غرفة الدرج ووحدة التكييف)، و**يثبت** أمان استغلال المساحات المظللة جزئياً عبر رفع الهياكل ميكانيكياً.
    
- **يختار** المكونات الأساسية بدقة ممثلة بـ **39 لوحاً شمسياً** من طراز LONGi بقوة **600W**، وعاكس ذكي ثلاثي الطور من طراز Huawei بقدرة **25kW**.
    
- **يحجم** السلاسل الكهروضوئية كهربائياً وحرارياً بالوصول إلى عدد مثالي يبلغ **13 لوحاً في السلسلة الواحدة**، وبإجمالي **3 سلاسل**.
    
- **يوجه** توزيع السلاسل على متتبعات القدرة (**Multi-MPPT**) للعاكس، عازلاً السلسلة المعرضة للظلال الجانبية لحماية إنتاجية السلاسل المستقرة.
    
- **يصمم** كابلات الجانب المستمر (DC) معتمداً مقطع **4 مم²** محققاً هبوط جهد آمن دون عتبة **1%**، و**يوصف** مصاهر حماية السلاسل بسعة **25A** وقواطع عزل بجهد **1000Vdc** تضمن الامتثال لمتراجحات التنسيق الانتقائي.

# الطور الأول: الأساس المعياري والمناخي للموقع

## 10 - 2 المورد الشمسي والبيانات المناخية للموقع (Solar Resource Data)

#ToRefactor 
تُعد دقة بيانات الإشعاع الشمسي حجر الزاوية في تقدير جودة وأداء الأنظمة الكهروضوئية. تم الاعتماد في هذا المشروع على منصة **Global Solar Atlas** لاستخراج المورد الشمسي لموقع الدراسة في مدينة حلب (Latitude: **37° N**, Elevation: **377 m**)، حيث توفر هذه المنصة بيانات تاريخية ونمذجة دقيقة للعوامل المناخية المؤثرة على الإنتاجية.

![[PV-10-02.png]] 
### تحليل مؤشرات الإشعاع الشمسي (GHI vs GTI)

يتم التمييز في هذا البحث بين نوعين من الإشعاع الشمسي لتحديد المتاح الفعلي للطاقة:

- **الإشعاع الأفقي الكلي (GHI):** يمثل مجموع الإشعاع الساقط على سطح أفقي، وقد بلغت قيمته لمدينة حلب **1930.4 kWh/m²** سنوياً.
    
- **الإشعاع المائل الكلي (GTI):** وهو المؤشر الأكثر أهمية، حيث يمثل الإشعاع الفعلي الساقط على مستوى الألواح عند زاوية الميل المثلى (**31°**). بلغت قيمته لمدينة حلب **2184.8 kWh/m²** سنوياً.

>[!info] نلاحظ
التوجيه الصحيح والميلان المثالي أديا إلى زيادة في الطاقة المستلمة بنسبة تقارب **13%** مقارنة بالسطح الأفقي.

### الإنتاجية النوعية ومعامل الأداء (Specific Yield & PR)

للانتقال من مرحلة "الإشعاع المتاح" إلى "الطاقة الكهربائية المنتجة"، نستخدم مؤشر **الإنتاجية النوعية (PVOUT)**، والذي يمثل كمية الطاقة الكهربائية (AC) المتوقع تصديرها لكل واحد كيلوواط ذروة ($kW_p$) من الاستطاعة المركبة. 

وتبلغ قيمة **PVOUT** لمدينة حلب: **1730.0 kWh/kWp** سنوياً.

النسبة بين الإنتاجية الكهربائية والإشعاع المتاح تسمى **معامل الأداء (Performance Ratio - PR)**، وهي تعبر عن جودة النظام ومجموع المفاقيد (الحرارية، الكبلات، العواكس). وتُحسب وفق العلاقة:

$$PR = \frac{PVOUT}{GTI} = \frac{1730.0}{2184.8} \approx 0.79$$

هذه القيمة (**79%**) تُعد مؤشراً على تصميم هندسي عالي الكفاءة، حيث أن موقع Global Solar Atlas يعتمد على نسبة تقع ضمن النطاق العالمي للأنظمة المصممة جيداً.

### ساعات الذروة الشمسية (Peak Sun Hours - PSH)

يتم تحويل قيمة الإشعاع اليومي إلى عدد ساعات مكافئة لشدة إشعاعية معيارية ($1000 \text{ W/m}^2$) لتسهيل حسابات التحجيم (Sizing):

- **ساعات الذروة الشمسية (PSH):** تُشتق من الإشعاع المائل اليومي ($GTI_{daily} = 5.98 \text{ kWh/m}^2$):
    
    $$PSH = \frac{GTI_{\text{annual}}}{365} = \frac{2184.8}{365} \approx 5.98 \text{ hours/day}$$
>[!info] بناءًا عليه
>يمكن تحديد استطاعة المنظومة لتغطية حمل يومي معين أو حساب الاستطاعة اليومية الناتجة التي يمكن لمنظومة ما انتاجها، وذلك بالإعتماد على العلاقة التالية : 
>$$\mathbf{PVOUT_{daily} \text{ (Specific Yield)} = PSH \times PR = \frac{\text{Daily Load}}{\text{PV Power}}}$$

## 10 - 3 مفهوم الساعات الشمسية الذروية (Peak Sun Hours - PSH)

نظراً لأن شدة الإشعاع الشمسي متغيرة باستمرار وتبدأ من الصفر عند الشروق لتصل للذروة عند الظهيرة ثم تنخفض للصفر عند الغروب، يكون شكل منحني الإشعاع الشمسي الحقيقي خلال ساعات النهار غير خطي (يأخذ شكل الجرس)، ولتبسيط الحسابات الهندسية يجب أن نسعى دائما إلى **الخطية (Linearity)** في جميع العمليات التي تطرأ علينا، إذ أن هذا المفهوم يسمح لنا بإجراء حسابات سريعة دون الحاجة لبرمجيات معقدة.
بالتالي لمعالجة الطبيعة الديناميكية المتغيرة لمنحنى الإشعاع الشمسي وتوحيد معايير الحساب الهندسية، تعتمد الفيزياء التطبيقية مبدأ **المستطيل المكافئ (Equivalent Rectangle)**. تكمن الفكرة في تحويل إجمالي الطاقة الإشعاعية المتراكمة طوال اليوم (المساحة تحت المنحنى الحقيقي) إلى مساحة هندسية منتظمة تأخذ شكل مستطيل ذو ارتفاع ثابت ($1 kW/m^2$) وعرضه هو عدد ساعات الذروة (PSH).

![[PV-10-01.png]]

يمكن حساب عدد ساعات الذروة الشمسية لليوم الواحد باستخدام العلاقة التالية:
$$PSH = \frac{Daily\ Irradiation\ (Wh/m^2/day)}{1000\ W/m^2}$$
أي أنه نسبة إجمالي الإشعاع الساقط على المتر المربع في يوم، على الاستطاعة القياسية.
### [[Deleted 10-2]] 

تكمن أهمية هذه القيمة في تبسيط الحسابات لتقدير الطاقة السنوية أو اليومية المتوقعة من المنظومة، بالإضافة سهولة التقييم الجغرافي والمقارنة بين وفرة الطاقة الشمسية بين المدن؛ فارتفاع متوسط PSH لمنطقة جغرافية معينة دليل على كثافة الإشعاع الشمسية في هذه المنطقة.

%%
**ملاحظة للمناقشة:** إذا سألك الأستاذ لماذا نستخدم $1000\text{ W/m}^2$ تحديداً؟ الإجابة هي لأن جميع المصانع (مثل شركة LONGi التي اخترت ألواحها) تعاير استطاعة الألواح وتفحصها مخبرياً عند هذه الشدة تحديداً، لذا يجب أن يكون المرجع في "ساعات الذروة" متوافقاً مع مرجع "استطاعة اللوح".
%%
### محددات ساعات الذروة الشمسية:

تتحدد قيمة **ساعات الذروة الشمسية (Peak Sun Hours - PSH)** بناءً على محددين جوهريين يحكمان كفاءة امتصاص الطاقة: **الموقع الجغرافي** إذ أن المناطق القريبة من خط الاستواء كثافة إشعاعية أعلى وثباتاً أكبر على مدار العام مقارنة بالمناطق القطبية، بينما المحدد الثاني هو الخصائص **الهندسية للمنظومة**؛ وهذا المحدد يمثل **زاوية ميل الألواح (Tilt Angle)** فالانحراف عن الزاوية المثالية يقود إلى تقليل المساحة المكافئة تحت منحنى الإشعاع اليومي وبالتالي انخفاض عدد ساعات الذروة المحسوبة للمنظومة.
### ساعات الذروة الشمسية لموقع المشروع

وتبرز الأهمية التطبيقية لهذه المحددات عند استعراض البيانات الإشعاعية للمناطق المختلفة؛ حيث يبلغ متوسط ساعات الذروة الشمسية الأفقية ($PSH_{\text{horizontal}}$) لمدينة حلب 4.74 ساعة، بينما يرتفع هذا المتوسط ليصِل إلى **5.98 ساعة/يوم** عند مَيل الألواح بزاوية 31° ($PSH_{\text{tilted}}$)، وهو ما يعكس كفاءة التوجيه الهندسي المعتمد لحسابات الإنتاجية السنوية (بالعتماد على موقع Global Solar Atlas)، وهو رقم يمثل المتوسط اليومي على مدار 365 يوماً. وبناءا على هذه القيمة نستطيع حساب الطاقة الفعلية (kWh) لمصفوفة ما، بضرب هذه القيمة بقدرة المصفوفة (kWp)، مع مراعاة أن أي انحراف في زاوية التوجيه أو الميل سينعكس بالضرورة على قيمة PSH المتاحة للمنظومة.

## 10 - 4 الإنتاجية النوعية (Specific Production - Specific Yield)

تُعرف الإنتاجية النوعية بأنها إجمالي الطاقة الكهربائية (AC) الصافية (kWh) التي توردها المنظومة الكهروضوئية إلى الشبكة أو الحمل خلال فترة زمنية محددة (عادةً ما تكون سنة كاملة)، منسوبةً إلى الكيلوواط الذروي الواحد من الاستطاعة الاسمية للألواح الشمسية المركبة (kWp)، إذ توفر أساساً موحداً للمقارنة بغض النظر عن حجم المنظومة وتحسب من العلاقة الرياضية التالية:
$$SY = \frac{E_{sys}}{P_{array-STC}}$$
**حيث أن:**

- الـ **$SY$**: الإنتاجية النوعية، وتقاس بوحدة ($kWh/kWp$).
- الـ **$E_{sys}$**: إجمالي الطاقة الكهربائية السنوية الناتجة عن المنظومة، وتقاس بوحدة ($kWh$).
- الـ **$P_{array_STC}$**: الاستطاعة الذروية الاسمية لمصفوفة الألواح عند شروط الاختبار القياسية، وتقاس بوحدة ($kWp$).

>[!info] بعبارة أخرى
الإنتاجية النوعية هي عبارة نسبة فيزيائية تخبرنا عن عدد الساعات التي استطاعت فيها المنظومة العمل بكامل طاقتها القصوى (kWp) لتنتج تلك الطاقة.
وكما هو واضح، قسمة الطاقة ($kWh$) على الاستطاعة ($kW$) تعطي زمناً ($h$).

### الفرق بين SY و PHS

حتما الإنتاجية النوعية (SY) أقل من PHS؛ لأن الإنتاجية النوعية تعكس المفاقيد الفنية للمنظومة (الحرارة، مقاومة الكابلات، كفاءة العاكس، والأوساخ)، والتي يعبر عنها هندسياً بمعامل الأداء (PR - Performance Ratio). بالتالي يعبر عن العلاقة بين هاتين القيمتين بالمعادلة التالية : 
$$PSH_{eff} = PSH \times PR$$
حيث $PSH_{eff}$ تعبر عن الإنتاجية النوعية اليومية الفعالة.
### أهمية الإنتاجية النوعية 

تكمن الأهمية الأكاديمية لهذا المؤشر في قدرته على إجراء مقارنة عادلة بين أداء محطات طاقة شمسية ذات أحجام واستطاعات مختلفة. بالإضافة إلى مقارنة فعالية المنظومات في مناطق جغرافية مختلفة، حيث يعكس مدى نجاح التصميم في استغلال المورد الشمسي المتاح. كما يقدم تصور دقيق عن أثر الضياعات (الحرارية، التوصيل، التظليل، وكفاءة العواكس) على المردود النهائي لكل وحدة استطاعة مركبة.

## 10 - 5 المعايير الاقتصادية والتشغيلية

يخضع قرار تصميم المنظومات المرتبطة بالشبكة لـ **غرض استثماري** بحت، حيث يهدف العميل عادةً إلى توفير نسبة محددة من فاتورة الاستهلاك الشهرية أو العمل كمستثمر يبيع الطاقة الفائضة للحكومة مقابل عوائد مادية. ومن الناحية الهندسية والاقتصادية، يُعد **الحد الأدنى للجدوى الاقتصادية** لهذه الأنظمة هو **10 كيلوواط**؛ إذ إن إنشاء محطة بقدرة أقل من ذلك يتطلب تكاليف رأسمالية مرتفعة (شاملة الألواح والعواكس والتركيب) لا تتناسب مع العائد الضئيل المحقق من توفير الفواتير الصغيرة، مما يجعل استرداد رأس المال غير مجدٍ اقتصادياً.

وتقنياً، تنقسم المنظومة إلى جانبين كهربائيين متباينين يفصل بينهما العاكس (Inverter) الذي يضطلع بمهمة تحويل التيار من مستمر إلى متردد ليتوافق مع متطلبات الشبكة. الجانب الأول يمتد من الألواح الشمسية حتى مدخل العاكس، ويجب أن تكون كافة **الكابلات وحمايات التيار المستمر (DC)** مخصصة لهذا النوع حصراً؛ نظراً لأن قطع التيار المستمر فيزيائياً أصعب بكثير من التيار المتردد بسبب استمرارية تدفقه في اتجاه واحد، مما يفرض استخدام صمامات (Fuses) وقواطع (Circuit Breakers) ذات مواصفات خاصة وأعلى سعراً لضمان إخماد القوس الكهربائي ومنع الحرائق.

![[PV-10-03.jpg]]

أما الجانب الثاني، فيبدأ من مخرج العاكس باتجاه الأحمال والشبكة العامة، حيث تُستخدم **كابلات وحمايات التيار المتردد (AC)** التقليدية المماثلة لتلك المستخدمة في تمديدات المباني. ويؤكد الخبراء على **عدم جواز استخدام كابلات أو قواطع الـ AC في دوائر الـ DC** والعكس؛ لأن قواطع التيار المتردد غير مصممة للتعامل مع حدود التيار المستمر، مما قد يؤدي لفشل نظام الحماية في اللحظات الحرجة وتلف المكونات أو حدوث مخاطر تشغيلية جسيمة. وبناءً على ذلك، يتطلب التصميم الاحترافي فصلاً تاماً في الحسابات والمكونات بين طرفي المصفوفة (Array Side) وطرف الشبكة (Grid Side) لضمان سلامة المنظومة وطول عمرها التشغيلي.

# الطور الثاني: اختيار المكون الأساسي والتصميم الهيكلي (الميكانيكي)

## 10 - 6 أنماط التصميم والمنهجية المتبعة

يخضع القرار الهندسي في بناء وتصميم المنظومة المرتبطة بالشبكة لثلاثة محددات أساسية تختلف باختلاف أولويات العميل وهدفه من المشروع، حيث تندرج جميعها تحت **الغرض الاستثماري** الذي تسعى هذه الأنظمة لتحقيقه، سواء عبر توفير النفقات أو جني الأرباح من بيع الطاقة. وهذه الأشكال الثلاثة هي:

1. **التصميم بناءً على فواتير استهلاك الكهرباء (Load-based):** وهو النمط الأكثر شيوعاً، حيث يتقدم العميل ببيانات استهلاكه لعام كامل (12 شهراً) بهدف توفير نسبة محددة من قيمة الفاتورة. وفي هذا السياق، يقوم المهندس هنا بحساب القدرة المطلوبة (kWp) التي تحقق هذا التوفير المالي بناءً على تعريفة الكهرباء المطبقة.
2. **التصميم بناءً على المساحة المتاحة (Area-based):** في هذه الحالة، لا يمتلك العميل هدفاً محدداً من حيث التوفير المالي، بل يمتلك **مساحة فيزيائية محددة** (مثل سطح مبنى تجاري أو قطعة أرض) ويرغب في استغلالها بالكامل لتركيب الألواح الشمسية. وتعتمد مهمة المصمم هنا على "ملء" هذه المساحة بأكبر عدد ممكن من الألواح وتحليل كمية الطاقة القصوى التي يمكن إنتاجها من هذه المساحة، ومن ثم إبلاغ العميل بنسبة التوفير التي ستحققها هذه القدرة الكلية.
3. **التصميم بناءً على ميزانية العميل (Budget-based):** يتحدد حجم المنظومة في هذا النمط وفقاً لـ **القدرة المالية** والسيولة المتوفرة لدى المستثمر؛ حيث يحدد العميل مبلغاً معيناً (ميزانية محددة) لإنفاقه على المشروع. وبناءً عليه، يقوم المهندس باختيار المكونات (ألواح وعواكس وهياكل) التي تعطي أقصى قدرة ممكنة ضمن هذا النطاق السعري، مع مراعاة أن المنظومات التي تقل قدرتها عن **10 كيلوواط** قد لا تكون ذات جدوى استثمارية عالية نظراً لارتفاع تكاليفها الرأسمالية مقابل العائد الضئيل المحقق من توفير فواتير صغيرة.

### منهجية المشروع

نظراً لكون المنشأة قيد التصميم (مخطط هندسي)، فسيتم اتباع النمط الثاني؛ أي التصميم بناءاً على المساحة المتاحة (Area-based Design)، ومراعاة لضيق السطح وصغر مساحته فقد تم اعتماد منهجية **Maximize Specific Yield**؛ أي سنتبع مبدأ الاستغلال الأقصى للمساحة المتوفرة، حيث تهدف هذه المنهجية إلى استغلال المساحة المتاحة على سطح المبنى بشكل كامل لتحقيق أقصى قدرة مركبة ممكنة. يضمن هذا النهج تحقيق أفضل جدوى اقتصادية للمشروع عبر تقليل التكاليف الثابتة لكل كيلو وات مركب، وتوفير مرونة مستقبلية للبنك في حال زيادة الأحمال الكهربائية، بدلاً من الاعتماد على تقديرات استهلاك قد لا تعكس الواقع التشغيلي الفعلي.

## 10 - 7 اختيار اللوح الشمسي

يُعد اختيار اللوح الشمسي حجر الزاوية في تصميم المنظومات الكهروضوئية، حيث تتوقف كفاءة استغلال المساحة المتاحة وجودة الطاقة المنتجة على الخصائص الفيزيائية والكهربائية للخلية المستخدمة. إذ وقع الاختيار على اللوح الشمسي من طراز **Hi-MO 6 Scientist (LR5-72HTH-600M)** من إنتاج شركة **LONGi** ، وذلك بناءً على الموثوقية العالية والتقنيات المتقدمة التي يوفرها هذا الطراز والموضحة في [[الملحق (أ)]].

### المبررات الفنية

تستند المفاضلة الهندسية لاختيار هذا النوع من الألواح إلى المعايير التالية:

1. **كفاءة التحويل العالية (High Efficiency):** يتميز اللوح بكفاءة تحويل تصل إلى **23.2%** ، وهي من أعلى النسب المتوفرة تجارياً، مما يتيح توليد استطاعة كبيرة (600 W) ضمن أبعاد ميكانيكية مدروسة (2218×1134×30 mm). يعد هذا التميز حاسماً في المنشآت الحضرية (مثل البنوك) حيث تكون مساحة الأسطح محدودة وتتطلب أقصى استغلال ممكن للمتر المربع الواحد.
    
2. **تقنية الخلايا المتقدمة (HPBC Technology):** يعتمد اللوح على تقنية خلايا **Hybrid Passivated Back Contact**، والتي تساهم في تحسين امتصاص الضوء وزيادة الاستطاعة الناتجة، بالإضافة إلى منح اللوح مظهراً جمالياً عصرياً يتناسب مع الواجهات المعمارية الحديثة.
    
3. **المعامل الحراري المنخفض (Temperature Coefficient):** يمتلك هذا الطراز معامل درجة حرارة للاستطاعة (Pmax) يبلغ **−0.290%/∘C**. تعكس هذه القيمة قدرة اللوح على الحفاظ على استقرار أدائه الإنتاجي بكفاءة عالية حتى في ظل الارتفاع الكبير في درجات الحرارة المحيطة بالموقع، مما يقلل من خسائر الطاقة الحرارية بشكل ملموس.
    
4. **الموثوقية والضمان (Warranty and Degradation):** يوفر المصنع ضماناً خطياً للأداء لمدة **25 عاماً** ، مع معدل تدهور سنوي ضئيل جداً لا يتجاوز **0.40%** من السنة الثانية وحتى الخامسة والعشرين. يضمن ذلك وصول إنتاجية اللوح إلى ما لا يقل عن **88.90%** من قدرته الأصلية في نهاية عمره التصميمي.

#### **أهم المواصفات الفنية للوح**

يلخص الجدول التالي أهم الخصائص الكهربائية والميكانيكية للوح المختار عند الشروط المعيارية (STC):

| **الميزة الفنية (Technical Feature)** | **القيمة (Value)** |
| --- | --- |
| **الاستطاعة القصوى (Pmax)** | 600 W |
| **جهد الدارة المفتوحة (Voc)** | 52.81 V |
| **تيار القصر (Isc)** | 14.46 A |
| **جهد نقطة القدرة القصوى (Vmp)** | 44.66 V |
| **تيار نقطة القدرة القصوى (Imp)** | 13.44 A |
| **كفاءة اللوح (Module Efficiency)** | 23.2% |
| **درجة حماية علبة التوصيل (Junction Box)** | IP68 |

### **المعايير التصميمية الكهربائية**

تعتمد منهجية التصميم في الأنظمة المرتبطة بالشبكة (On-Grid) على مواءمة مخرجات المصفوفة الشمسية مع حدود الدخل للعاكس الذكي. وبناءً على البيانات الفنية للوح المختار **LONGi Hi-MO 6**، تم التركيز على المعاملات الكهربائية التالية كمحددات أساسية لضمان سلامة واستقرار المنظومة:

1. **جهد الدارة المفتوحة ($V_{oc} = 52.81\text{ V}$):** يمثل هذا المعامل القيمة القصوى للجهد الناتج عن اللوح عند ظروف الإشعاع المعيارية وبدون حمل. يُعد هذا الرقم المرجع الأساسي لتحديد الحد الأقصى لعدد الألواح الموصولة على التوالي في السلسلة الواحدة (String)، وذلك لضمان عدم تجاوز جهد المصفوفة الإجمالي لحد الحماية الخاص بالعاكس، خاصة في حالات انخفاض درجات الحرارة.
    
2. **جهد أقصى قدرة ($V_{mp} = 44.66\text{ V}$):** هو الجهد التشغيلي الفعلي الذي تحقق عنده الألواح أقصى استطاعة خارجة. تم اختيار هذا اللوح لضمان بقاء جهد السلاسل المصممة دائماً ضمن نطاق تتبع نقطة القدرة القصوى **(MPPT Range)** للعاكس، مما يضمن كفاءة تحويل مستقرة طوال فترات النهار.
    
3. **تيار القصر ($I_{sc} = 14.46\text{ A}$):** يمثل أقصى تيار يمكن أن يتدفق في المنظومة، وهو المعامل الحاسم في اختيار أقطار الكابلات وتحديد سعة قواطع الحماية (DC Circuit Breakers) والصمامات (Fuses). حيث يجب أن يتوافق هذا التيار مع كل مدخل MPPT للعاكس بحيث يوفر هامش أمان عالٍ ويمنع حدوث ظاهرة قص التيار (Clipping).

## 10 - 8 التوجيه الجغرافي وزاوية الميل المثالية (Orientation and Optimal Tilt Angle)

تعد عملية تحديد زاوية الميل والتوجه البوصلي الركيزة الأساسية لضمان تعامد الإشعاع الشمسي على المصفوفة لأطول فترة ممكنة، مما ينعكس مباشرة على كفاءة استخلاص الطاقة السنوية (Annual Energy Yield). وبناءً على التحليل الجغرافي والمناخي لموقع البنك، تم اعتماد المعايير التالية:

#### التوجيه الجغرافي (Azimuth)

نظراً لوقوع مدينة حلب في نصف الكرة الشمالي عند خط عرض **$37^\circ\text{ N}$**، واستناداً إلى مسار الشمس الظاهري في هذه المنطقة، تم توجيه الألواح نحو **الجنوب الجغرافي (True South)** تماماً (بزاوية أزيموث تبلغ $180^\circ$ أو $0^\circ$ حسب الاصطلاح المستخدم). يضمن هذا التوجيه مواجهة الألواح لقرص الشمس عند ذروة الارتفاع (Solar Noon) طوال العام، وهو المسار الأمثل لتحقيق أقصى استلام للحزمة الإشعاعية المباشرة (Direct Beam Radiation) وتجنب خسائر التوجيه غير الصحيح التي تزداد حدتها في فصل الشتاء.

#### زاوية الميل المثالية (Tilt Angle)

بما أن المنظومة المصممة هي منظومة مرتبطة بالشبكة **(On-Grid System)** تهدف إلى تحقيق أقصى عائد استثماري وتصدير أكبر قدر من الطاقة للشبكة على مدار العام، فقد تم استبعاد زاوية الميل التقليدية المساوية لخط العرض ($37^\circ$). وبدلاً من ذلك، تم تطبيق منهجية الحساب المتقدمة للمنظومات الثابتة لتحقيق أقصى إنتاجية سنوية **(Year-round Optimization)** وفق العلاقة التالية:

$$\beta = (\phi \times 0.76) + 3^\circ$$

وبالتعويض عن قيمة خط عرض حلب ($\phi = 37^\circ$):

$$\beta = (37^\circ \times 0.76) + 3^\circ \approx 31^\circ$$

تم اعتماد الزاوية **$31^\circ$** كزاوية ميل ثابتة للمصفوفة؛ حيث يوفر هذا الميل توازناً دقيقاً بين إنتاجية أشهر الصيف (حيث يكون الإشعاع في ذروته ولكن الحرارة مرتفعة) وأشهر الشتاء (حيث تنخفض زاوية سقوط الشمس)، مما يؤدي في النهاية إلى رفع "معدل الأداء" (Performance Ratio) الكلي للمنظومة.

#### التوزيع الميكانيكي واستغلال المساحة المتاحة (Mechanical Layout and Space Optimization)

بناءً على التحليل المعماري لسطح المنشأة، تم اعتماد منهجية **"==الاستغلال الأقصى للمساحة الصافية=="**، حيث تم حساب المساحة الإجمالية بـ **129 م²**. ولتحقيق التوازن بين الكفاءة الإنتاجية ومعايير السلامة المهنية، تم اتباع القواعد التصميمية التالية:

- استناداً إلى قواعد حرم الأمان الهيكلي (Structural Safety Offset) تم مراعاة مسافة تقدر بـ **0.4 متر** على الأقل لممرات الصيانة، كما سيتم استخدام **"سياج معدني بسيط"** بدلاً من جدار إسمنتي، مما يمنع الظلال ويحقق الأمان. %%وبهذه الطريقة نكون قد قللنا تأثير قوى الرفع الهوائية (Wind Uplift) على الهياكل المعدنية عند الزوايا، وتوفر لدينا مسار آمن لفريق الصيانة دون الحاجة لوجود حواف إسمنتية مرتفعة قد تسبب تظليلاً جزئياً على الألواح.%%
	
-  انحراف المحور الطولي للجزء الأكبر من المبنى بزاوية **45°** عن الجنوب الجغرافي؛ يحتم علينا اعتماد توزيع "أسنان المنشار" (Sawtooth Layout) في بعض أجزاء المبنى، إذ يضمن هذا التوزيع توجيه المصفوفة نحو الجنوب تماماً لتحقيق أقصى إنتاجية، مع مراعاة المسافات الفاصلة بين الصفوف لمنع التظليل المتبادل في حال التثبيت التقليدي (Standard Fixed Mounting) للألواح، وهو ما سيتم تفصيله في حسابات المسافات (Pitch Distance) والتحليل الانشائي في الفقرات القادمة.
	
- نظراً الاتجاه الجغرافي للمبنى واحتمال استخدام توزيع "أسنان المنشار" فقد وقع الاختيار على الوضعية الطولية للألواح (Portrait Orientation)، إذا أن هذه الوضعية ستسهل التعامل مع المساحة المهدرة في معظم الفراغات المثلثية الناتجة عن التوزيع المنشاري للألواح. وتسمح هذه الوضعية بانزلاق الأتربة ومياه الأمطار بكفاءة عالية عند زاوية ميل **31°**، مما يقلل من خسائر الاتساخ (Soiling Losses) الشائعة في البيئة الجغرافية لمدينة حلب.

## 10 - 9 تحليل الظلال

### تأثير الظلال على كفاءة الألواح الشمسية

تُعد دراسة تأثير الظلال أحد الركائز الأساسية في تصميم وهندسة أنظمة الطاقة الكهروضوئية (PV Systems)، حيث إن كفاءة النظام تعتمد بشكل مباشر على استمرارية تعرض الخلايا للإشعاع الشمسي المباشر. يهدف هذا القسم إلى تحليل ظاهرة التظليل وتأثيراتها التقنية، مع توضيح الأسس الرياضية المتبعة لتلافيها.

إذ إن الظلال تمثل عائقاً حرجاً يؤدي إلى تدهور أداء الألواح الشمسية؛ وبالتالي حدوث **تظليل جزئي**، ولو على مساحة ضئيلة جداً من اللوح، يتسبب في انخفاض حاد وغير متناسب في القدرة الكهربائية المولدة. يعود ذلك إلى طبيعة توصيل الخلايا داخل اللوح، حيث يؤدي تظليل خلية واحدة إلى زيادة مقاومتها الداخلية، مما يحد من تدفق التيار في كامل السلسلة (String)، وقد يؤدي لحدوث "البقع الساخنة" (Hotspots)، وهو ما يستوجب مراعاة المسافات البينية بدقة عند التصميم لضمان أعلى إنتاجية ممكنة.

### تصنيف أنواع الظلال في المواقع الإنشائية

عند إجراء المحاكاة الهندسية لموقع التثبيت، يجب التمييز بين نوعين رئيسيين من الظلال لضمان استقرار النظام:

1. **التظليل المتبادل بين الصفوف (Row-to-Row Shading):** وهو الظل الذي يلقيه الصف الأمامي من الألواح على الصف الذي يليه، ويحدث هذا النوع غالباً في الأنظمة الأرضية أو فوق الأسطح المستوية نتيجة التقارب غير المدروس بين الهياكل.
2. **التظليل الناتج عن العوائق المحيطة (Environmental Shading):** ويشمل الظلال الناتجة عن العناصر المادية في بيئة المشروع، مثل **المباني المجاورة، الأشجار، أو العوائق الإنشائية** كغرف المحولات أو المداخن، والتي قد تحجب الإشعاع في ساعات الذروة.

### تصنيف الظل الناتج عن جسم

ينتج عن الجسم نوعين من الظلال تبعًا لتغير فصول السنة وتعاقبل الليل والنهار، وهما :

### المعلمات الأساسية المطلوبة للحساب

#### الزوايا :

- **زاوية ميل الألواح ($\beta$):** زاوية ميل المصفوفة عن الأفق.
- **زاوية ارتفاع الشمس ($\theta$):** الزاوية بين أشعة الشمس والمستوي الأفقي.
- **زاوية السمت الشمسي ($\psi$):** انحراف الشمس عن الجنوب الجغرافي الحقيقي.

### الارتفاع الرأسي (H):

الارتفاع الرأسي (Vertical Height) للألواح الشمسية هو المسافة العمودية من أعلى نقطة في حافة اللوح الخلفية إلى سطح الأرض، وهو الطول الحقيقي لأجسام العوائق المحيطة.

من أجل أجسام العوائق فهذا الإرتفاع يكون ثابت ومعلوم، لا يحتاج لحساب، أما بالنسبة للألواح هذا الارتفاع ليس ثابتاً، بل يعتمد على طول اللوح (Panel Length) وزاوية ميله (Tilt Angle) المحسوبة للمشروع. 

يُعتمد في حسابه على (L) الطول الحقيقي للوح في حال وضعية Portrait (أو عرضه في حال وضعية Landscape)، بالاضافة إلى ($\beta$) زاوية ميل اللوح (Tilt Angle)، كما هو موضح في العلاقة التالية : 
$$\mathbf{H = L \times \sin(\beta)}$$
#### المسقط الأفقي ($L_{proj}$)

 **"المسقط الأفقي" (Horizontal Projection)** أو **"بصمة اللوح" (Module Footprint)** هي الإزاحة الأفقية الناتجة عن إسقاط الطول المائل للوح الشمسي على مستوى سطح العمل (الأرض أو السطح المستوي). وتمثل المسافة الفعلية التي يشغلها اللوح من طول السطح عند النظر إليه من الأعلى (Top View).
 ويحسب من العلاقة التالية :
$$\mathbf{L_{proj} = L \times \cos(\beta)}$$
>[!info] نلاحظ
>بزيادة زاوية ميل الألواح ($\beta$) يقل المسقط الأفقي ($L_{proj}$) ويزداد الارتفاع الرأسي (H)

#### التظليل الأفقي (Horizontal Shading)

يُعرف التظليل الأفقي (أو طول الظل) بأنه الامتداد الهندسي الناتج عن إسقاط ظل الأجسام المعتمة على مستوى العمل الأفقي (Horizontal Plane) نتيجة اعتراض مسار الحزمة الإشعاعية المباشرة. في هندسة الأنظمة الكهروضوئية، يمثل هذا النوع من التظليل "البعد الحرج" الذي يحدد المسافة الدنيا الفاصلة بين مصفوفات الألواح المتتالية، وتُدعى هذه المسافة بالمسافة البينية (Pitch Distance) أو المسافة الأفقية الدنيا، ويرمز لها بالرمز ($D$).

تهدف إلى إيجاد التوازن المثالي بين تعظيم القدرة المركبة في المساحة المتاحة ومنع خسائر الطاقة الناتجة عن التظليل المتبادل (Row-to-Row Shading). إذ تمثل الإزاحة الأفقية المطلوبة بين نهاية الصف الأمامي وبداية الصف الذي يليه.

تُحسب مسافة التظليل بناءً على أسوأ أيام السنة ظلاً؛ وهو يوم **21 ديسمبر** (الانقلاب الشتوي)، حيث تكون الشمس في أدنى مستوياتها، مما ينتج عنه أطول ظل ممكن خلال العام، ويسمى هذا اليوم **بيوم التصميم (Design Day)**. وبعبارة أخرى إذا نجح التصميم في تجنب الظل في هذا اليوم، فإنه سيضمن كفاءة النظام طوال أيام السنة.

يتم التعامل مع هذه المسافة برمجياً وهندسياً كقاعدة لمثلث قائم الزاوية، حيث يمثل ارتفاع الصف ($H$) الضلع القائم، بينما تمثل زاوية ميل الشمس ($\theta$) الزاوية التي تحدد طول ظل هذا الارتفاع على الأرض. وتحسب من العلاقة التالية :
$$ D = \frac{H}{\tan(\theta)} $$
حيث يتم استخراج زاوية الظل ($\theta$) من "مخطط مسار الشمس" (Sun Path Chart) الخاص بإحداثيات الموقع. 
##### معامل تصحيح السمت (Azimuth Correction - $\psi_{\small Correction}$)

عند حساب المسافة البينية بين صفوف الألواح، تعتمد المعادلة الأساسية ($D = H / \tan(\theta)$) على زاوية ارتفاع الشمس (Solar Elevation Angle - $\theta$). ومع ذلك، فإن هذه المعادلة تفترض أن الظل يسقط بشكل عمودي تماماً خلف اللوح. في الواقع، خلال ساعات النهار (خاصة في الصباح الباكر عند التاسعة صباحاً أو في المساء عند الثالثة عصراً)، تكون الشمس في موقع جانبي بالنسبة للصفوف، مما يجعل الظل يسقط بزاوية مائلة.

هنا تبرز الحاجة لـ **معامل تصحيح السمت**  لتقليص المسافة المحسوبة إلى "أقل مسافة ممكنة" (Minimum Distance) تضمن عدم التظليل دون إهدار في المساحات الأرضية للمشروع. فتكمن أهمية إدراج هذا المعامل في الحساب في كونه يعكس دقة التصميم الهندسي؛ فاستخدام المسافة $D$ بدون تصحيح سيؤدي إلى تباعد كبير غير مبرر بين الصفوف، مما يقلل من عدد الألواح التي يمكن تركيبها في المساحة المتاحة. أما باستخدام **Azimuth Correction**، فإنك تحقق "الاستغلال الأمثل للمساحة" (Space Optimization) مع ضمان حماية كاملة للألواح من الظلال المتبادلة خلال ساعات الذروة الإنتاجية.

بعد الحصول على المسافة الأولية ($D$) الناتجة عن نسبة الارتفاع إلى ظل زاوية الارتفاع، يتم تطبيق معامل التصحيح باستخدام دالة جيب التمام ($Cosine$) للزاوية المستخرجة:

$$
\mathbf{D_{\text{min}} = D \times \cos(\psi_{\small Correction})}
$$
حيث أن:

- ع **$D_{\text{min}}$ :** هي المسافة النهائية المصححة التي سيتم اعتمادها في مخططات التنفيذ.
- ع **$\psi_{\small Correction}$** : هي زاوية التصحيح التي تنتج عن الفرق بين زاوية السمت للشمس في التوقيت ما، وخط الجنوب الجغرافي (الذي يمثل زاوية $180^{\circ}$).

>[!info] بعبارة أخرى
> تخيل أنك تنظر لسطح البنك من الأعلى (Top View):
> - في الساعة 12:00 ظهراً: تكون الشمس في الجنوب تماماً. أشعة الشمس تضرب اللوح من الأمام، والظل يسقط خلف اللوح باتجاه الشمال تماماً بشكل عمودي على الصف. في هذه اللحظة، طول الظل الفعلي (D) هو نفسه المسافة التي يجب تركها بين الصفوف.
>  - في الساعة 9:00 صباحاً (أسوأ حالة في الشتاء): الشمس لا تكون في الجنوب، بل تكون في الجنوب الشرقي (بزاوية سمت $\psi$). وبالتالي، الظل الذي سيرميه اللوح الأول لن يسقط نحو الشمال بشكل مستقيم، بل سيسقط مائلاً نحو الشمال الغربي.
>    
> الظل المائل (القطري) طويل جداً (المسافة D). ولكن بما أننا نرص صفوف الألواح بشكل متوازٍ ومواجه للجنوب، فنحن لا نحتاج لأن نُبعد الصف الثاني بمسافة توازي هذا "الظل القطري" بالكامل. نحن نحتاج فقط للابتعاد بمقدار المركبة الرأسية (المسافة العمودية بين الصفين) التي تضمن أن هذا الظل المائل سيمر "بجانب" أو "أمام" الصف الثاني وليس فوقه.
> لذلك، نضرب طول الظل المائل بـ $\psi_{\small Correction}$ لنأخذ المسقط العمودي فقط. إذا لم تستخدم هذا المعامل، ستجد أن المسافة المحسوبة بين الصفوف ضخمة جداً مما سيهدر مساحة سطح البنك بالكامل.
> 
> ![[PV-10-17.png]]
> 

### التظليل الجانبي (Lateral Shading)

يُعرف التظليل الجانبي بأنه الإزاحة العرضية للظلال الناتجة عن انحراف زاوية السمت الشمسية (Azimuth Angle) عن خط الجنوب الجغرافي، ويظهر تأثيره بشكل حرج خلال ساعات الصباح الباكر وقبيل الغروب. في هذه الفترات، تكون الشمس في أدنى ارتفاع لها فوق الأفق، مما يؤدي إلى استطالة الظلال بشكل قطري (Lateral Extension) بعيداً عن المحور الطولي للجسم، مما قد يتسبب في تظليل المساحات المجاورة للعوائق المرتفعة.

تُمثل المسافة الجانبية الضلع الثالث للمثلث القائم الذي تشكله المسافة الأفقية الأولية (D) و المسافة الأفقية المصححة ($D_{min}$)، ويمكن حسابها من العلاقة :
$$ \mathbf{D_{Lat} = D \times \sin(\psi_{\small Correction})} $$

![[PV-10-18.png]]

*اكتفت معظم المراجع (بل جميع المراجع التي استطعت الوصول إليها) بحساب التظليل البيني الأفقي نظراً لعموميته، بينما تم في هذا المشروع إدخال دراسة التظليل الجانبي (المحلي) الناتج عن الملحقات الإنشائية للمبنى المصرفي (كغرفة الدرج)، نظراً للأثر البالغ للعوائق المحيطة في البيئات الحضرية المحدودة المساحة، وتمت معالجتها عبر تحديد النافذة الزمنية الفعالة للإشعاع وتوزيع السلاسل الكهربائية بشكل مستقل.*

## الحسابات المسافية الناتجة عن تأثير الظلال

### حسابات للألواح :

من ورقة بيانات (Datasheet) اللوح ([[الملحق (أ)]]) نجد أن أبعاد اللوح ($2.278 \times 1.134 \times 0.03\text{ m}$) وزاوية الميل المثالية التي توصلنا لها عبر الحسابات الدقيقة في الفصل السابق هي $\beta = 31^\circ$، وبناءًا عليه:

#### حساب الارتفاع الرأسي (H) للوح :

في حال الوضع الطولي (Portrait) :
$$H = 2.278 \times \sin(31^\circ) = 1.173 \text{ m}$$
في حال الوضع العرضي (Landscape) : 
$$H = 1.134 \times \sin(31^\circ) = 0.584 \text{ m}$$

#### حساب المسقط الأفقية ($L_{proj}$) للوح :

من أجل الوضع الطولي (Portrait) :
$$L_{proj} = 2.278 \times \cos(31^\circ) = 1.952 \text{ m}$$
من أجل  الوضع العرضي (Landscape) :
$$\mathbf{L_{proj} = L \times \cos(\beta)}=1.134 \times \cos(31^\circ)=0.972 \text{ m}$$

وبناءًا عليه نستطيع معرفة المساحة التي سيشغلها اللوح الواحد من المساحة المدروسة في كلتا الوضعيتين، وهي بالأبعات التي يظهرها الرسم التالي : 

![[PV-10-15.png]]
#### المسافة الأفقية للظل المتبادل بين الصفوف:

تم الاعتماد على موقع UO Solar Radiation Monitoring Laboratory للحصول على مخطط لمسار الشمس على مر أشهر السنة بناءًا على احداثيات مدينة حلب (36.12 درجة شمال خط الاستواء، و 37.08 شرق غرينتش).

![[PV-10-05.png]]

المنحني الأخير من يعبر عن يوم التصميم (21 كانون الأول) والذي ستبنى عليه الدراسة، تشترط المراجع الهندسياً أن لا تقل النافذة الزمنية للتصميم عن مدة **6 ساعات** في يوم الانقلاب الشتوي. وبناءًا عليه، تم تحديد الساعة **9:00 صباحاً** كبداية لفترة ذروة الإشعاع الشمسي التي يجب حمايتها من التظليل.

![[PV-10-06.png]] 

كما هو موضح في المخطط، زاوية الظل ($\theta$) في هذا التوقيت تساوي $12^{\circ}$ وبالتعويض في العلاقة :

في حال الوضع الطولي (Portrait) للوح :
$$ D = \frac{1.173}{\tan(12)} = 5.518 \text{ m} $$
في حال الوضع العرضي (Landscape) :
$$ D = \frac{0.584}{\tan(12)} = 2.747 \text{ m} $$
##### تصحيح المسافة الأفقية بواسطة معامل تصحيح السمت :

بدايةً يتم استخراج زاوية السمت (Azimuth Angle) من مخطط مسار الشمس (Sun Path Chart) للموقع الجغرافي المحدد، يتم إيجاد نقطة التقاطع بين الساعة 9:00 صباحاً ومنحنى تاريخ 21 ديسمبر. وبالتالي من أجل مشروعنا الحالي، زاوية السمت عند هذه النقطة هي $123^{\circ}$.

![[PV-10-07.png]]

ومن ثم يتم حساب زاوية التصحيح (Correction Angle) عبر حساب الفرق بين زاوية السمت المستخرجة وخط الجنوب الجغرافي (الذي يمثل زاوية $180^{\circ}$):

![[PV-10-08.jpg]]

$$
\psi_{\small Correction} = 180^{\circ} - \text{Azimuth Angle }(\psi)  \text{ at 9:00 AM}
$$
$$
\psi_{\small Correction} =180^{\circ} - 123^{\circ} = 57^{\circ}
$$

الآن بأخذ معامل التصحيح بعين الاعتبار، نحصل على المسافات الأفقية الدقيقة التالية :

من أجل الوضع الطولي (Portrait) :
$$ D_{\text{min}} = 5.518 \times \cos(57^{\circ}) = 3 \text{ m} $$
من أجل الوضع العرضي (Landscape) :
$$ D_{\text{min}} = 2.747 \times \cos(57^{\circ}) = 1.5 \text{ m} $$
### حسابات العوائق المحيطة 

تم التمييز في هذا المشروع بين النافذة الزمنية لظلال سلاسل الألواح وظلال العوائق الموضعية، حيث اعتمدت الدراسة نافذة مخصصة للعوائق من الساعة 11:00 AM حتى الساعة 14:00 PM ليوم التصميم (21 كانون الأول)، وذلك استناداً إلى المبررات الهندسية التالية:

- التظليل الأفقي بين الصفوف هو فقد نظامي يؤثر على كامل مصفوفات المحطة بشكل متماثل، لذا يتطلب نافذة صارمة (9-16). أما ظل غرفة الدرج فهو ظل موضعّي ومحصور، وتطبيق النافذة الصارمة عليه سيؤدي إلى **"عقوبة مساحية مفرطة"** تخرج نصف مساحة السطح الشرقي للبنك من الخدمة من أجل تجنب ظل لحظي في الشتاء.
    
- تشير البيانات المناخية إلى أن الفترة بين (11:00 - 14:00) في الشتاء تحوي أكثر من **70%** من طاقة الإشعاع اليومية الفعالة. أما الطاقة المتاحة قبل الساعة 11 صباحاً وبعد 2 ظهراً في شهر كانون الأول فهي ضئيلة جداً، وبالتالي فإن الجدوى الاقتصادية تقتضي عدم التضحية بمساحات واسعة من السطح لمنع خسارة طاقة شتوية شبه معدومة.
    
- إن المساحة الشرقية التي سيغطيها ظل غرفة الدرج في تمام الساعة 9:00 صباحاً في شهر كانون الأول، ستكون مشمسة بالكامل وتنتج بطاقتها القصوى طوال أشهر الصيف والربيع والخريف (التي تمثل ذروة إنتاج المحطة سنوياً). لذلك، هندسياً، يُعد قبول نسبة مفاغيد ظلال شتوية طفيفة جداً (أقل من 2% سنوياً) أفضل بكثير من خسارة إنتاج هذه المساحة بالكامل طوال العام. 

*وبناءًا عليه نخرج بالقاعدة الهندسية التالي : إذا كانت نسبة الفقد السنوي في بقعة معينة بسبب الظل **أقل من 3% إلى 5%**، يتم تركيب الألواح فيها دون تردد، لأن العائد المادي من إنتاجها طوال الصيف والخريف يعوض وزيادة خسارتها الطفيفة في الشتاء.*

#### حساب المسافة الأفقية :

نستخراج قيمة زاوية السمت (Azimuth) وزاوية الارتفاع من مخطط مسار الشمس الخاص بمدينة حلب ليوم 21 كانون الأول، من أجل النافذة الزمنية (11:00 - 14:00) :

![[PV-10-19.png]]

كما هو واضح من المخطط، زاوية ارتفاع الشمسي هي $\theta = 27.7^\circ$ ، بينما زاوية التصحيح هي $\psi_{\small Correction} = 23^\circ$ ، وبالتعويض بعلاقات الحساب : 
##### من أجل وحدة التكييف :

طول وحدة التكييف هو $1.3 \text{ m}$ وهو الارتفاع الرأسي (H)، وبالتعويض بعلاقة المسافة الأفقية :
$$ D = \frac{H}{\tan(\theta)} = \frac{1.3}{\tan(27.7)} = 2.47 \text{ m}$$
وبأخذ معامل تصحيح السمت بعين الاعتبار :
$$D_{\text{min}} = D \times \cos(\psi_{\small Correction}) = 2.47 \times \cos(23) = 2.27 \text{ m}$$
##### من أجل غرفة الدرج :

إذ أن ارتفاع غرفة الدرج هو $2.5 \text{ m}$، وبالتعويض بعلاقة المسافة الأفقية :
$$ D = \frac{2.5}{\tan(27.7)} = 4.76 \text{ m}$$
بأخذ معامل تصحيح السمت بعين الاعتبار :
$$D_{\text{min}} = 4.76 \times \cos(23) = 4.38 \text{ m}$$
### حساب المسافات الجانبية للظل

##### من أجل وحدة التكييف

$$ D_{Lat} = D \times \cos(\psi_{\small Correction}) = 2.47 \times \sin(23) = 0.965 \text{ m} $$
#### من أجل غرفة الدرج
$$ D_{Lat} = 4.76 \times \sin(23) = 1.86 \text{ m} $$
![[PV-10-09.png]]
*تمثيل الظلال لوحدة التكييف وغرفة الدرج على المخطط المعماري للبنك في AutoCAD*

*تم حصر دراسة التظليل الجانبي في هذا المشروع على العوائق الإنشائية الثابتة (مثل غرفة الدرج ووحدة التكييف المركزي)، نظراً لارتفاعها النسبي الذي يفرض حرم ظل عرضي يجب تجنبه عند توزيع المصفوفات.
أما بالنسبة للألواح الشمسية ضمن السلسلة الواحدة، فقد تم **إهمال حساب التظليل الجانبي المتبادل** بينها؛ وذلك لاعتماد تصميم ميكانيكي يرتكز على رصف الألواح بشكل متلاصق (Side-by-Side Arrangement) دون وجود فواصل عرضية كبيرة تسمح بمرور الضوء أو تكون الظلال بين الألواح المتجاورة في نفس الصف، مما يجعل المصفوفة تعمل ككتلة واحدة مستمرة حيال الزوايا الجانبية للشمس.* 

## 10 - 10 منهجية تركيب وتوزيع الألواح

تم اختيار منهجية التركيب المتدرج (Tiered/Staircase Arrangement) لصفوف المصفوفة الكهروضوئية بناءً على تحليل هندسي يأخذ في الحسبان القيود المكانية والتقنية للموقع، وذلك استناداً إلى الأسس التالية:

**1. تعظيم عامل استغلال المساحة (Land Utilization Factor - LUF):**

تُعد المساحة السطحية في المنشآت الحضرية (مثل المباني المصرفية) مورداً محدوداً وعالي القيمة. إن الاعتماد على التوزيع التقليدي بمسافات بينية واسعة لتجنب التظليل المتبادل (Inter-row Shading) سيؤدي إلى خسارة ما يقارب **40-50%** من المساحة المتاحة نظراً لزاوية الميل المرتفعة المطلوب اعتمادها لمدينة حلب (31°). لذا، فإن الانتقال العمودي (الهيكل المتدرج) هو الحل الهندسي الأمثل لتقليل المسافات البينية إلى الصفر ($D=0$)، مما يرفع الكثافة الطاقية للمتر المربع الواحد إلى حدها الأقصى.

**2. خفض تكلفة الوحدة الطاقية (LCOE) على المدى الطويل:**

بالرغم من الزيادة الطفيفة في التكاليف الرأسمالية (CAPEX) المتعلقة بالهياكل المعدنية، إلا أن هذه الزيادة تُقابَل بزيادة جوهرية في الاستطاعة المركبة الإجمالية (Installed Capacity). وبما أن التكاليف الثابتة للمشروع (Inverters, Protection, Design, Labor) قد تم دفعها بالفعل، فإن إضافة ألواح إضافية عبر الهياكل المتدرجة يقلل من حصة الكيلوواط الواحد من التكاليف الكلية، مما يحسن من الجدوى الاقتصادية النهائية للمنظومة.

**3. تكلفة الفرصة البديلة (Opportunity Cost):**

إن عدم استخدام الهياكل المتدرجة في مساحة محدودة يعني بالضرورة التخلي عن جزء من الطاقة التي كان يمكن إنتاجها. وفي ظل التعريفة الكهربائية المرتفعة للمنشآت التجارية (البنوك)، تصبح "قيمة الطاقة غير المنتجة" سنوياً أكبر بكثير من "تكلفة الحديد الإضافي" المدفوعة لمرة واحدة في بداية المشروع.

**4. تحسين الأداء الحراري والتهوية:**

يساهم الارتفاع المتدرج في خلق مجالات هوائية أفضل تحت الألواح، مما يساعد في التبريد الطبيعي (Natural Convection). وهذا يقلل من درجة حرارة تشغيل الخلية ($T_{cell}$)، وبالتالي يحد من الضياعات الحرارية ويحافظ على كفاءة الألواح قريباً من قيمها الاسمية، خاصة في فصل الصيف.

### توزيع الألواح:

بناءًا على ما سبق، تم توزيع الألواح على الشكل التالي : 

![[PV-10-10.png]]

إذ تم توجيه الألواح إلى الجنوب تماماً، وبزاوية ميل $31^{\circ}$ للأواح ، كم تم مراعاة مسافة لا تقل عن 40 سم كممرات صيانة، بالإضافة إلى اعتماد الحواف الحديدة عوضاً عن الحواف الاسمنتية تبعاً لمبدأ "الإستغلال الأعظمي للمساحة"، وبالطبع لم يكن هناك مراعاة للتظليل المتبادل نظراً لعتماد تقنية "التركيب المتدرج" حيث ستكون الحواف العلوية لكل سلسلة متلاقية مع الحواف السفلية للسلسلة التي تعقبها.

## 10 - 11 دراسة إمكانية استغلال المساحات المظللة جزئياً

يُعد الاستبعاد المطلق للمساحات التي تسقط عليها الظلال في البيئات الحضرية منهجاً غير اقتصادي ويؤدي إلى هدر مساحات واسعة من السطح المتاح. نظراً لأن الظل المتشكل من العوائق الإنشائية يمتلك سلوكاً هندسياً متغيراً ينخفض فيه ارتفاع مسقط الظل شاقولياً كلما ابتعدنا عن الجسم المسبب له، فإنه يمكن استغلال هذه الخاصية لتركيب الألواح بأمان؛ شريطة أن يكون ارتفاع الحافة السفلية لهيكل المصفوفة المرفوعة أعلى من الارتفاع الشاقولي الأقصى للظل الساقط في يوم التصميم (21 كانون الأول).

![[PV-10-11.png]]
*الشكل A*

بناءً على التحليل الميكانيكي للموقع، تم تحديد خمس ألواح إضافية يمكن دمجها في المنظومة (الشكل A). يتأثر اللوحين الملونين باللون البرتقالي بظل غرفة الدرج، في حين تتأثر الألواح الثلاثة الملونة باللون الأحمر بظل وحدة التكييف (الشكل B). وقد ركزت الدراسة على نقطة التقاطع الحرجة التي يقترب فيها الظل إلى حدها الأقصى من مصفوفة الألواح لضمان دقة الحسابات في الحالة الأكثر سوءاً (Worst-Case Scenario).

![[PV-10-12.png]]
*الشكل B*

##### أ. التحليل الهندسي للألواح المقابلة لوحدة التكييف:

يبلغ الارتفاع الشاقولي لوحدة التكييف $1.3\text{ m}$، بينما يرتفع الهيكل الحامل للصف المقابل (الصف الثاني المتدرج) بمقدار $1.173\text{ m}$ عند حافته السفلية. للتحقق من عدم تداخل الظل مع الخلايا الكهروضوئية، تم حساب الارتفاع الشاقولي للظل عند نقطة التقاطع في يوم الانقلاب الشتوي (21 كانون الأول).

وفقاً للمخطط الهيكلي (الشكل C والشكل D)، فإن طول الجزء المتخطي للمستوى الشاقولي لمقدمة الألواح يبلغ $l = 1.003\text{ m}$ (وهو طول الظل الإجمالي مطروحاً منه المسافة البينية الفاصلة بين وحدة التكييف ومقدمة الصف الثاني والمقدرة بـ $1.267\text{ m}$).

![[PV-10-13.png]]
*الشكل C*

![[PV-10-16.png]]
*الشكل D*

أولاً، يتم تحديد زاوية ميل أشعة الظل الشاقولية ($\varphi$) من المثلث المرجعي للعائق:

$$\varphi = \tan^{-1}\left(\frac{1.3}{2.27}\right) = 29.8^\circ$$

وباعتماد هذه الزاوية، يُحسب الارتفاع الشاقولي الفعلي للظل ($\text{Shadow Height}$) عند خط المقابلة الأمامي للصف الثاني باستخدام النسبة المثلثية للظل ($\tan$):

$$\text{Shadow Height} = l \times \tan(\varphi) = 1.003 \times \tan(29.8^\circ) = 0.574\text{ m}$$

وبمقارنة الارتفاع الناتح مع ارتفاع الهيكل الحامل:

$$0.574\text{ m} < 1.173\text{ m}$$

>[!info] الخلاصة:
يتضح هندسياً أن المسار الفراغي للظل يمر بالكامل تحت مستوى الخلايا الفعالة للألواح الشمسية في الصف الثاني، مما يجعل إضافة هذه الألواح آمناً تماماً من مفاغيد التظليل اللحظية، ومجدياً لتعظيم استطاعة المنظومة الكلية.

##### ب. التحليل الهندسي للوح المقابل لغرفة الدرج:

تُعد غرفة الدرج العائق الإنشائي الأكثر تأثيراً على السطح نظراً لارتفاعها البارز والذي يبلغ $2.5\text{ m}$ مقارنة بمستوى السطح. يتأثر اللوحين الملونين باللون البرتقالي (كما هو موضح في الشكل E) بالظل الجانبي الغربي لغرفة الدرج، وللتحقق من أمان هذا اللوح وعدم حدوث تظليل على خلاياه الفعالة، تم إجراء تحليل هندسي شاقولي للظل في يوم الانقلاب الشتوي (21 كانون الأول).

![[PV-10-14.png]]
*الشكل E*

![[PV-10-20.png]]
*الشكل F*

وفقاً لبيانات في المخطط (الشكل E والشكل F)، يبلغ طول الظل الإجمالي المتشكل $4.38\text{ m}$، في حين تبتعد الحافة الأمامية لهيكل الألواح عن جدار غرفة الدرج مسافة أفقية قدرها $3.044\text{ m}$. وبناءً عليه، فإن طول جزء الظل المتخطي للمستوى الشاقولي لمقدمة اللوح الشمسي يبلغ:

$$l = 4.38 - 3.044 = 1.336\text{ m}$$

لحساب الارتفاع الشاقولي للظل عند نقطة التقاطع الحرجة، يتم أولاً حساب زاوية ميل أشعة الظل الشاقولية ($\varphi$) استناداً إلى أبعاد العائق (غرفة الدرج):

$$\varphi = \tan^{-1}\left(\frac{2.5}{4.38}\right) = 29.71^\circ$$

باستخدام زاوية الميل المستنتجة والنسبة المثلثية للظل ($\tan$)، يُحسب الارتفاع الفعلي للظل ($\text{Shadow Height}$) عند الحافة السفلية لهيكل اللوح:

$$\text{Shadow Height} = l \times \tan(\varphi) = 1.336 \times \tan(29.71^\circ) = 1.336 \times 0.5708 = 0.763\text{ m}$$

وبمقارنة الارتفاع الفعلي للظل عند خط المقابلة مع الارتفاع الإنشائي للحافة السفلية لهيكل الألواح في هذه السلسلة والمتدرج عند $1.173\text{ m}$:

$$0.763\text{ m} < 1.173\text{ m}$$

>[!info] الخلاصة:
> 
> تؤكد الحسابات الهندسيّة أن الارتفاع الأقصى للظل عند نقطة التقاطع ($0.763\text{ m}$) يقع بالكامل تحت مستوى الحافة السفلية للألواح ($1.173\text{ m}$). هذا يعني أن أشعة الظل الممتدة من غرفة الدرج ستمر من تحت الهيكل المعدني المرفوع ولن تمس الخلايا الفعالة للوح الشمسي، مما يجعل قرار إضافة هذان اللوحان قراراً آمناً ومبرراً هندسياً لرفع كفاءة استغلال المساحة المتاحة.
 
## 10 - 12 حساب الاستطاعة الإجمالية للمنظومة وتقييم الكثافة المساحية

بناءً على التوزيع الميكانيكي النهائي للمصفوفات الكهروضوئية، وبعد الأخذ بالاعتبار جميع المحددات الإنشائية والمسافات البينية اللازمة لتفادي التظليل الأفقي المتبادل بين الصفوف، تم التوصل إلى القدرة الاستيعابية القصوى الممكنة لسطح المبنى المصرفي المتاح للدراسة.

يتضمن التصميم النهائي تركيب **39 لوحاً شمسياً** باستطاعة ذروية تبلغ **$600 \text{ W}$** للوح الواحد. وتُحسب الاستطاعة الإجمالية الناتجة عن المنظومة ($P_{\text{total}}$) وفق العلاقة الرياضية التالية:

$$P_{\text{total}} = N \times P_{\text{panel}}$$
$$P_{\text{total}} = 39 \times 600 \text{ W} = 23,400 \text{ W} = 23.4 \text{ kWp}$$
حيث أن:

- $N$: العدد الإجمالي للألواح الكهروضوئية الموزعة على السطح ($39 \text{ Panels}$).
    
- $P_{\text{panel}}$: استطاعة اللوح الواحد تحت ظروف الاختبار المعيارية ($600 \text{ W}$).

![[PV-10-21.png]]

وحيث بلغت المساحة الإجمالية النهائية المستغلة في الدراسة والمحددة بدقة عبر مخططات التصميم الهندسي (AutoCAD) حوالي **$195.6709 \text{ m}^2$**، فإنه يمكن تقييم كفاءة استغلال المساحة الحضرية للمشروع من خلال حساب مؤشر **كثافة الاستطاعة المساحية (Power Density)** وفق المعادلة التالية:

$$\text{Power Density} = \frac{P_{\text{total}}}{\text{Area}}$$

$$\text{Power Density} = \frac{23,400 \text{ W}}{195.6709 \text{ m}^2} \approx 119.59 \text{ W/m}^2$$

### التقييم الهندسي لكفاءة التصميم المساحي

يُمثل تحقيق كثافة استطاعة تبلغ $119.59 \text{ W/m}^2$ في بيئة حضرية مقيدة هندسياً مؤشراً تصميمياً مرتفعاً. وتكمن القيمة الهندسية المضافة في هذا التوزيع في تجاوز العوائق الحرجة على السطح (مثل غرفة الدرج ووحدات التكييف المركزية) دون التضحية بإنتاجية المحطة؛ حيث يعود الفضل في تحقيق هذه السعة الاستيعابية إلى التخلي عن نمط "التثبيت التقليدي بمسافات بينية واسعة" وتبني منهجية **"الهياكل المتدرجة" (Terraced / Stepped Mounting Structures)**.

سمحت هذه المنهجية بتقليص المسافات الميتة بين مصفوفات الألواح مع الحفاظ على زوايا السقوط الإشعاعي الآمنة وحماية الخلايا من التظليل الموضعي الخارجي، الأمر الذي أدى في النهاية إلى دمج ألواح إضافية رفعت من القدرة الذروية للمنظومة، وضمنت الوصول برقعة السطح المتاحة إلى كفاءة الاستغلال الفراغي القصوى.

# الطور الثالث: المواءمة والتحجيم الكهربائي للعاكس

## 10 - 13 اختيار العاكس

يُمثل اختيار العاكس الكهروضوئي (Inverter) ومواءمته الهندسية مع مصفوفة الألواح الخطوة الأكثر حرجاً في تصميم المنظومات المرتبطة بالشبكة (On-Grid)؛ حيث يُعد العاكس المكون الذكي المسؤول عن تحويل التيار المستمر ($DC$) المتغير الناتج عن الألواح إلى تيار متردد ($AC$) مستقر ومتوافق تماماً مع معايير الجودة والتردد للشبكة الكهربائية العامة. وتستند الممارسة الهندسية الأكاديمية الصارمة في هذا الصدد إلى تحقيق توازن دقيق بين **مواءمة القدرة (Power Matching)** و**تحليل الكفاءة التشغيلية والاقتصادية** لضمان أعلى عائد طاقة ممكن بأقل تكلفة تأسيسية.

### أولاً: مواصفات العاكس المعتمد ونسبة التحميل (DC/AC Ratio)

بناءً على الحسابات الدقيقة المنجزة في الفقرة السابقة، والتي حددت الاستطاعة الإجمالية للمصفوفة الكهروضوئية بقيمة **$23.4 \text{ kWp}$**، %%تم استبعاد الخيار السابق (عاكس بقدرة $50 \text{ kW}$) نظراً للانخفاض الحاد في نسبة تحميله وما يترتب عليه من هدر مالي وتشغيلي. وبدلاً من ذلك، %% تم اعتماد العاكس الذكي ثلاثي الطور من طراز **Huawei SUN2000-25KTL-M5** بقدرة اسمية تبلغ **$25 \text{ kW}$**.

لتأكيد المواءمة الفنية، يتم حساب نسبة التحميل (DC/AC Loading Ratio) والمعروفة هندسياً بمعامل التصميم ($R$) وفق العلاقة التالية:

$$R = \frac{P_{DC \text{ (Nominal)}}}{P_{AC \text{ (Nominal)}}}$$
$$R = \frac{23.4 \text{ kW}}{25 \text{ kW}} = 0.936$$
#### التبرير التشغيلي للنسبة المعتمدة:

تشير الممارسات الهندسية القياسية إلى أن تصميم نسبة التحميل حول القيمة ($0.90$ - $1.15$) في المناطق ذات الإشعاع الشمسي المرتفع يُعد تصميماً مثالياً؛ حيث تضمن النسبة المحسوبة ($0.936$) تشغيل العاكس في النطاق المحصور بين **$40\%$ إلى $80\%$** من حمل التشغيل الاسمي (Load %) لأطول فترة زمنية ممكنة خلال ساعات النهار.

وفقاً لمنحنيات الكفاءة الخاصة بهذا الطراز، فإن هذه المنطقة تمثل ذروة الأداء التشغيلي؛ حيث يبلغ العاكس كفاءته الأوروبية الموزونة (European Weighted Efficiency) البالغة **$98.2\%$** وكفاءته القصوى البالغة **$98.4\%$**، مما يقلل من الضياعات الحرارية الذاتية داخل دوائر العاكس الإلكترونية ويرفع من إنتاجية الطاقة السنوية النوعية (Energy Yield) للمحطة.

### ثانياً: التبرير التكنولوجي وحماية المنظومة (Technical & Safety Justification)

تم اختيار هذا الطراز تحديداً تلبيةً للمحددات الجغرافية والكهربائية الخاصة بموقع المشروع، وذلك بناءً على الميزات التكنولوجية التالية:

- **مرونة تتبع النقطة الأعظمية (Multi-MPPT):** يحتوي العاكس على **متعقِبين مستقلين للاستطاعة العظمى (2 MPP Trackers)** مع إجمالي 4 مداخل تيار مستمر (مدخلان لكل متعقب). تمنح هذه البنية القدرة على فصل المصفوفات كهربائياً؛ مما يتيح معالجة مشكلة الظلال الجانبية الناتجة عن العوائق الإنشائية (مثل غرفة الدرج ووحدات التكييف) عبر حصر الألواح المتأثرة في متعقب مستقل، لحماية كفاءة باقي الألواح المستقرة من مفاقيد عدم التطابق (Mismatch Losses).
    
- **التوافق مع التيارات العالية:** يدعم العاكس تيار دخل أقصى يصل إلى **$30 \text{ A}$** عند ربط سلسلتين على متعقب واحد، و$20 \text{ A}$ للسلسلة المنفردة، وهو ما يتوافق تماماً مع التيارات المرتفعة الناتجة عن ألواح الـ $600 \text{ W}$ الحديثة، مما يضمن تلافي ظاهرة "قص التيار" (Current Clipping) وضمان امتصاص كامل القدرة المولّدة.
    
- **معايير الأمان والسلامة النشطة:** بما أن المنظومة مُثبتة على سطح منشأة مصرفية حيوية، فإن العاكس يوفر حماية متقدمة جداً قائمة على الذكاء الاصطناعي ضد حدوث القوس الكهربائي المستمر (AI-Powered Arc Fault Circuit Interrupter - AFCI)، حيث يقوم بفصل النظام تلقائياً في زمن قياسي عند استشعار أي شرارة كهربائية لمنع نشوب الحرائق، بالإضافة إلى احتوائه على حمايات مدمجة من الصواعق وارتفاع الجهد من النوع الثاني (Type II SPD) لجهتي التيار المستمر والمتردد.

### **ملخص المواصفات الفنية للعاكس المعتمد**

يوضح الجدول التالي أبرز الخصائص الكهربائية والفنية للعاكس المستخلص من وثيقة البيانات (Datasheet) الخاصة بشركة Huawei لتوثيق مطابقتها للتصميم:

|**الميزة الفنية (Technical Feature)**|**التوصيف والقيمة (Value & Description)**|
|---|---|
|**الطراز القياسي (Model)**|Huawei SUN2000-25KTL-M5|
|**الاستطاعة الاسمية المترددة (Rated AC Power)**|25,000 W|
|**أقصى كفاءة تحويل (Max. Efficiency)**|98.4%|
|**الكفاءة الأوروبية الموزونة (Euro. Efficiency)**|98.2%|
|**أقصى جهد دخل مستمر (Max. Input Voltage)**|1,100 V|
|**الجهد الاسمي لدخل التيار المستمر (Rated Input Voltage)**|600 V|
|**نطاق جهد تشغيل الـ MPPT**|200 V - 1000 V|
|**عدد متتبعات الاستطاعة العظمى (No. of MPPTs)**|2|
|**أقصى عدد لمداخل التيار المستمر (Max. Inputs)**|4 (مدخلان لكل MPPT)|
|**أقصى تيار دخل لكل MPPT**|30 A (لمدخلين متوازيين) / 20 A (لمدخل منفرد)|
|**أقصى تيار قصر للمتتبع (Max. Short-Circuit Current)**|40 A|
|**حماية القوس الكهربائي (Arc Fault Protection)**|متوفرة ومدمجة (Yes / AI-Powered)|
|**حماية الارتفاع المفاجئ للجهد (Surge Arrester)**|Type II لجهتي AC و DC|
|**نوع التبريد ودرجة الحماية البيئية**|تبريد هوائي ذكي (Smart Air Cooling) / IP66|

## 10 - 14 التحليل الحراري الحرج لجهود الألواح الكهروضوئية

تكمن الخطورة التقنية في تصميم المنظومات الكهروضوئية في أن الخصائص الكهربائية للألواح (الجهد والقدرة) تتأثر بعلاقة عكسية مع درجات الحرارة المحيطة؛ فعند ارتفاع حرارة الخلايا الشمسيّة ينخفض جهدها وقدرتها المخرجة، بينما يؤدي انخفاض الحرارة إلى ارتفاع حاد في الجهد. ويُعبر عن هذا السلوك الفيزيائي بـ **المعامل الحراري لجهد الدارة المفتوحة ($\text{Temperature Coefficient of } V_{oc}$)**، والذي يحمل قيمة سالبة تبلغ **$-0.29\%/^{\circ}\text{C}$** وفقاً لورقة بيانات اللوح المعتمد.

ولضمان استقرار النظام وموثوقيته الكهربائية في ظل التقلبات المناخية الحادة للموقع بين فصلي الصيف والشتاء، يتوجب إجراء "حسابات الحالات الحرجة للجهد" (Critical Voltage Analysis) لتصحيح قيم الجهد عند درجات الحرارة المتطرفة (أقصى حرارة صيفاً $60^{\circ}\text{C}$ وأقل حرارة شتاءً $0^{\circ}\text{C}$) بالاعتماد على المعادلة القياسية التالية:

$$V_{\text{new}} = V_{\text{STC}} + \left[V_{\text{STC}} \times \frac{\text{Temp Coeff}}{100} \times (T_{\text{actual}} - 25)\right]$$

### أولاً: حساب جهود الدارة المفتوحة الحرجة ($V_{oc}$)

يُعد حساب قيم جهد الدارة المفتوحة المصححة حرارياً مطلباً أساسياً لتحديد حدود الأمان المطلق للمنظومة، وتجنب حدوث انهيار كهربائي في الدوائر الإلكترونية للعاكس.

#### 1. حالة الشتاء الحرجة (أقل درجة حرارة $0^{\circ}\text{C}$):

في الصباحات الباردة جداً، يرتفع جهد اللوح إلى أعلى قيمة متوقعة له ($V_{oc\text{-}max}$). ويتم حساب جهد اللوح الواحد عند هذه النقطة لضمان عدم تجاوز الجهد الإجمالي للسلسلة للحد الأقصى المطلق لجهد دخل العاكس المستمر ($1100\text{ V}$)، حيث إن أي تجاوز لهذا الحد سيؤدي إلى تدمير العاكس فوراً:

$$V_{oc\text{-}max} = 52.81\text{ V} + \left[52.81\text{ V} \times \frac{-0.29}{100} \times (0^{\circ}\text{C} - 25)\right] = 56.64\text{ V}$$

#### 2. حالة الصيف الحرجة (أقصى درجة حرارة $60^{\circ}\text{C}$):

في ذروة فصل الصيف، ينخفض جهد اللوح إلى أدنى قيمة متوقعة له ($V_{oc\text{-}min}$). يُحسب هذا الجهد للتأكد من أن جهد المنظومة الإجمالي سيبقى أعلى من جهد بدء تشغيل العاكس ($V_{start\text{-}up} = 200\text{ V}$) لضمان "استيقاظ" النظام وبدء ضخ الطاقة حتى في الأيام شديدة الحرارة:

$$V_{oc\text{-}min} = 52.81\text{ V} + \left[52.81\text{ V} \times \frac{-0.29}{100} \times (60^{\circ}\text{C} - 25)\right] = 47.45\text{ V}$$

### ثانياً: حساب جهود نقطة القدرة القصوى الحرجة ($V_{mp}$)

لضمان بقاء المنظومة تعمل ضمن **مجال تتبع نقطة القدرة القصوى (MPPT Operating Range)** الخاص بالعاكس والممتد من $200\text{ V}$ إلى $1000\text{ V}$ طوال أيام السنة، يتم تصحيح قيم جهد العمل عند أقصى قدرة ($V_{mp} = 44.66\text{ V}$ عند ظروف STC) تحت نفس الظروف الحرارية المتطرفة.

#### 1. أدنى جهد تتبع متوقع صيفاً ($V_{mpp\text{-}min}$):

يتم حساب هذه القيمة عند درجة حرارة $60^{\circ}\text{C}$ للتأكد من أن انخفاض الجهد التشغيلي صيفاً لن يجبر العاكس على الخروج من النطاق الأدنى لتتبع أقصى قدرة:

$$V_{mpp\text{-}min} = 44.66\text{ V} + \left[44.66\text{ V} \times \frac{-0.29}{100} \times (60^{\circ}\text{C} - 25)\right] = 40.127\text{ V}$$

#### 2. أقصى جهد تتبع متوقع شتاءً ($V_{mpp\text{-}max}$):

يتم حساب هذه القيمة عند درجة حرارة $0^{\circ}\text{C}$ للتأكد من أن ارتفاع الجهد التشغيلي شتاءً لن يتجاوز الحد الأعلى لمجال التتبع المسموح به ($1000\text{ V}$)، مما يسمح للعاكس بالعمل بأعلى كفاءة تحويل دون قيود أو كبح للقدرة:

$$V_{mpp\text{-}max} = 44.66\text{ V} + \left[44.66\text{ V} \times \frac{-0.29}{100} \times (0^{\circ}\text{C} - 25)\right] = 47.897\text{ V}$$

إن إيجاد هذه القيم الحرارية الأربعة المصححة بدقة يمثل الركيزة الرياضية والضمانة الهندسية التي تفصل بين التصاميم الأكاديمية الآمنة والتركيبات العشوائية؛ حيث ستُشكل هذه القيم المدخلات الأساسية في الفقرة التالية لتحديد العدد المسموح به من الألواح في السلسلة الواحدة كهربائياً.

## 10 - 15 تحجيم السلاسل وضوابط نافذة الجهد (String Sizing)

تُعد عملية تحجيم السلاسل الكهروضوئية (String Sizing) الركيزة الأساسية للتصميم الكهربائي للمنظومة؛ حيث تُستخدم القيم الحرارية الحرجة المستنتجة سابقاً لتحديد النطاق الرياضي المسموح به لعدد الألواح المتصلة على التوالي في السلسلة الواحدة. يهدف هذا التحجيم إلى ضمان بقاء الجهد الإجمالي للمصفوفة ضمن "نافذة الجهد التشغيلي والآمن" للعاكس طوال أيام السنة وتحت كافة الظروف المناخية المتطرفة.

### أولاً: الحدود الأمنية المطلقة لجهد الدارة المفتوحة (Absolute Safety Limits)

تُحدد هذه الحدود النطاق الذي يضمن حماية العاكس من التلف القطعي شتاءً، ويضمن استيقاظه وبدء تشغيله صيفاً.

#### 1. أدنى عدد ألواح مسموح به في السلسلة الواحدة ($N_{min}$):

يُحسب لضمان أن جهد المصفوفة في أشد الأيام حراً صيفاً (عند $60^{\circ}\text{C}$) يمتلك القيمة الكافية لتجاوز جهد بدء تشغيل العاكس ($V_{start\text{-}up} = 200\text{ V}$)، مع أخذ فاقد هبوط الجهد في كابلات التيار المستمر بعين الاعتبار بنسبة $5\%$ لرفع الأمان التشغيلي:

$$N_{min} = \frac{V_{start\text{-}up} \text{ (Inverter)}}{V_{oc\text{-}min} \text{ (Module)} \times (1 - \text{Losses})}$$

$$N_{min} = \frac{200\text{ V}}{47.45\text{ V} \times (1 - 0.05)} = \frac{200}{45.077} = 4.43 \approx 5 \text{ Panels}$$

> **ملاحظة تصميمية:** يتم جبر الكسر إلى الرقم الصحيح الأعلى ($5$ ألواح) لضمان تحقيق الجهد المطلوب تحت أسوأ الظروف.

#### 2. أقصى عدد ألواح مسموح به في السلسلة الواحدة ($N_{max}$):

يُحسب لضمان عدم احتراق الدوائر الإلكترونية للعاكس في أبرد صباحات الشتاء (عند $0^{\circ}\text{C}$)، حيث يرتفع جهد الألواح إلى ذروته. ولا يتم إدخال المفاقيد هنا لضمان حد الأمان المطلق مقارنة بالجهد الأقصى للعاكس ($1100\text{ V}$):

$$N_{max} = \frac{V_{max\text{-}DC} \text{ (Inverter)}}{V_{oc\text{-}max} \text{ (Module)}} = \frac{1100\text{ V}}{56.64\text{ V}} = 19.42 \approx 19 \text{ Panels}$$

> **ملاحظة تصميمية:** يتم تقريب الناتج إلى الرقم الصحيح الأدنى ($19$ لوحاً)؛ لأن تجاوز هذا العدد ولو بكسر بسيط يعني تخطي حاجز $1100\text{ V}$ وتدمير العاكس كهربائياً.

### ثانياً: الحدود التشغيلية لمنطقة تتبع الاستطاعة العظمى (MPPT Limits)

لضمان بقاء المنظومة ضمن نطاق تشغيل تتبع نقطة القدرة القصوى للعاكس والمحصور بين $200\text{ V}$ و $1000\text{ V}$، يتم تصحيح حدود التحجيم بالاعتماد على جهود العمل ($V_{mp}$):

#### 1. أدنى عدد ألواح مسموح به لمجال الـ MPPT صيفاً ($N_{min\text{-}MPPT}$):

يضمن هذا الحد عدم انخفاض جهد المصفوفة صيفاً عن النطاق الأدنى الذي يبدأ عنده العاكس بتتبع أقصى قدرة، مع احتساب فاقد كابلات الـ DC بنسبة $5\%$:

$$N_{min\text{-}MPPT} = \frac{V_{mpp\text{-}min} \text{ (Inverter)}}{V_{mpp\text{-}min} \text{ (Module)} \times (1 - \text{Losses})}$$

$$N_{min\text{-}MPPT} = \frac{200\text{ V}}{40.127\text{ V} \times 0.95} = \frac{200}{38.12} = 5.24 \approx 6 \text{ Panels}$$

#### 2. أقصى عدد ألواح مسموح به لمجال الـ MPPT شتاءً ($N_{max\text{-}MPPT}$):

يضمن هذا الحد عدم تجاوز جهد التشغيل شتاءً للحد الأعلى لمجال التتبع ($1000\text{ V}$)، مما يتيح للعاكس العمل بكامل حريته الديناميكية دون كبح للقدرة المخرجة (Over-voltage Clipping):

$$N_{max\text{-}MPPT} = \frac{V_{mpp\text{-}max} \text{ (Inverter)}}{V_{mpp\text{-}max} \text{ (Module)}} = \frac{1000\text{ V}}{47.897\text{ V}} = 20.87 \approx 20 \text{ Panels}$$

### ثالثاً: تحديد العدد المثالي والأمثل للألواح ($N_{ideal}$)

بينما تمنحنا الحسابات السابقة "النطاق الآمن والمسموح" لعدد ألواح السلسلة ($6 \le N \le 19$)، فإن الممارسة الهندسية المثلى تقتضي التمركز حول **الجهد الاسمي المقنن (Rated Input Voltage)** للعاكس والبالغ **$600\text{ V}$**؛ حيث يمثل هذا الجهد نقطة الاستقرار التي يحقق عندها العاكس أعلى كفاءة تحويل داخلية.

يتم حساب العدد المثالي للألواح بقسمة الجهد المقنن للعاكس على جهد أقصى قدرة لللوح عند الشروط المعيارية ($V_{mp \text{ at STC}} = 44.66\text{ V}$):

$$N_{ideal} = \frac{V_{rated} \text{ (Inverter)}}{V_{mp} \text{ (at STC)}} = \frac{600\text{ V}}{44.66\text{ V}} = 13.43 \approx 13 \text{ Panels}$$

بناءً على التقريب الأكاديمي، يتم اعتماد **13 لوحاً في السلسلة الواحدة** كعدد نهائي ومثالي للتصميم.

#### الخلاصة التحققية للتصميم:

- الرقم المعتمد ($13$) يقع تماماً في منتصف النطاق الآمن والتشغيلي المحسوب ($6 \le 13 \le 19$).
    
- يتوافق هذا الرقم رياضياً بشكل كامل مع العدد الإجمالي لألواح المنظومة ($39$ لوحاً)، حيث يقبل القسمة عليها بدقة وبدون باقٍ ($39 \div 13 = 3$ سلاسل متساوية)، مما يلغي تماماً مفاقيد عدم التطابق الجهدية بين السلاسل.

## 10 - 16 التوزيع الكهربائي الفعال للسلاسل على متعقبات القدرة (MPPT Configuration)

تُمثل عملية حساب وتوزيع السلاسل الكهروضوئية (String Distribution) المرحلة الحاسمة في الموازنة بين القدرة التصميمية للمنظومة وبين القيود الكهربائية والتشغيلية لمداخل العاكس الذكي. يهدف التوصيل على التوازي للسلاسل إلى تجميع التيارات الكهربائية للوصول إلى القدرة الكلية المستهدفة مع الحفاظ على الجهد ضمن النطاق التشغيلي المسموح به، ومواءمة الخصائص التشغيلية للمصفوفة مع مواصفات متعقبات نقطة القدرة القصوى (MPPT Trackers) المتوفرة في العاكس.

### أولاً: حساب عدد السلاسل الكلي ($N_{strings}$)

بعد تحديد العدد الإجمالي للألواح ($N_{total} = 39 \text{ Panels}$) والعدد الأمثل للألواح في السلسلة الواحدة الموصلة توالياً ($N_{series} = 13 \text{ Panels}$)، يتم حساب عدد السلاسل المطلوبة لتشكيل مصفوفة المنظومة الكاملة وفق العلاقة التالية:

$$N_{strings} = \frac{N_{modules}}{N_{series}}$$

$$N_{strings} = \frac{39}{13} = 3 \text{ Strings}$$

ينتج عن الحساب رقم صحيح تماماً يُلغي الحاجة لجبر الكسور، مما يضمن تماثلاً كهربائياً مطلقاً بين السلاسل المصممة ويمنع حدوث أي تفاوت في الجهد بينها.

### ثانياً: آلية التوزيع الهندسي وعزل تأثير الظلال

يتميز العاكس المعتمد **Huawei SUN2000-25KTL-M5** بكونه متعدد المداخل ويحتوي على **متعقِبين مستقلين (2 MPP Trackers)** بواقع مدخلين لكل متعقب. بناءً على ورقة بيانات اللوح الشمسي المختار من طراز **LR5-72HTH-600M**، تم استغلال هذه الميزة التكنولوجية لتوزيع السلاسل الثلاث هندسياً بشكل يحيد تأثير الظلال الجزئية الناتجة عن العوائق الإنشائية في الموقع (غرفة الدرج ووحدات التكييف المركزية) وفق الآلية التالية:

- **المتعقب الأول (MPPT 1):** يتم توصيل سلسلتين كهربائيتين على التوازي (بإجمالي 26 لوحاً شمسياً). يُخصص هذا المتعقب حصرياً لإدارة الألواح الواقعة في المناطق الآمنة والمشمسة تماماً طوال فترات النهار (القسمين الأوسط والغربي من السطح).
    
- **المتعقب الثاني (MPPT 2):** يتم توصيل السلسلة الثالثة المتبقية (13 لوحاً شمسياً) بشكل منفرد ومستقل عبر مدخل واحد. يُخصص هذا المتعقب للألواح المثبتة في الجهة الشرقية من السطح والقريبة من العوائق الإنشائية المعرضة للظلال الجانبية اللحظية.

> **التبرير الهندسي:** تضمن هذه المنهجية حصر تأثير هبوط الجهد والقدرة الناتج عن الظلال الموضعية في السلسلة الثالثة فقط (عبر MPPT 2)، مما يحمي السلسلتين الأولى والثانية (عبر MPPT 1) من مفاقيد عدم التطابق (Mismatch Losses)، ويسمح لهما بالعمل بأقصى كفاءة إنتاجية ممكنة دون التأثر بأداء الألواح المظللة جزئياً.

### ثالثاً: التحقق من قيود التيار الكهربائي والأمان المطلق

يؤثر التوصيل على التوازي مباشرة على شدة التيار الكهربائي؛ حيث يظل جهد المصفوفة ثابتاً بينما تُجمع التيارات المارة. ولضمان الأمان الصارم، يتم استخراج القيم الحالية للألواح من ورقة البيانات الخاصة بالطراز **LR5-72HTH-600M** عند ظروف الاختبار القياسية (STC):

- تيار القصر للوح: $I_{sc} = 14.46 \text{ A}$.
    
- التيار عند أقصى قدرة: $I_{mp} = 13.44 \text{ A}$.
    
- المعامل الحراري لتيار القصر: $\alpha_{Isc} = +0.050\%/^{\circ}\text{C}$.

نظراً لأن تيار القصر يرتفع طردياً مع درجة الحرارة، يتم أولاً حساب قيمة تيار القصر المصحح عند أقصى درجة حرارة متوقعة صيفاً (60°C) لضمان أعلى حد أمان رياضي للمنظومة:

$$I_{sc (60^{\circ}\text{C})} = I_{sc \text{ (STC)}} \times \left[1 + \frac{\alpha_{Isc}}{100} \times (60^{\circ}\text{C} - 25^{\circ}\text{C})\right]$$

$$I_{sc (60^{\circ}\text{C})} = 14.46 \text{ A} \times \left[1 + \frac{0.050}{100} \times 35\right] = 14.46 \times 1.0175 \approx 14.71 \text{ A}$$

#### 1. التحقق من قيود المتعقب الأول (MPPT 1 - سلسلتان على التوازي):

- **تيار التشغيل الأقصى (Max. Operating Current):** يبلغ تيار التشغيل الإجمالي للسلسلتين المتوازيتين $2 \times 13.44 \text{ A} = 26.88 \text{ A}$، وهو أقل من أقصى تيار دخل يسمح به العاكس لكل متعقب لمدخلين والمقدر بـ **30 A** ($26.88 \text{ A} \le 30 \text{ A}$)، مما يضمن امتصاص كامل الطاقة المولدة دون حدوث ظاهرة قص التيار (Current Clipping).
    
- **تيار القصر الأقصى (Max. Short-Circuit Current):** يبلغ تيار القصر الأقصى صيفاً $2 \times 14.71 \text{ A} = 29.42 \text{ A}$، وهو أقل بكثير من الحد الأقصى المطلق لتيار القصر الذي يتحمله العاكس لكل متعقب والبالغ **40 A** ($29.42 \text{ A} \le 40 \text{ A}$)، مما يحقق حماية كاملة للمكونات الإلكترونية الداخلية.

#### 2. التحقق من قيود المتعقب الثاني (MPPT 2 - سلسلة منفردة):

- **تيار التشغيل الأقصى (Max. Operating Current):** يبلغ تيار التشغيل للسلسلة المنفردة $1 \times 13.44 \text{ A} = 13.44 \text{ A}$، وهو يقع بأمان تام تحت الحد الأقصى المسموح به من الشركة المصنعة للعاكس عند ربط مدخل واحد والمقدر بـ **20 A** ($13.44 \text{ A} \le 20 \text{ A}$).
    
- **تيار القصر الأقصى (Max. Short-Circuit Current):** يبلغ تيار القصر الأقصى المحسوب صيفاً $1 \times 14.71 \text{ A} = 14.71 \text{ A}$، وهو أقل من حد تيار القصر الأقصى للعاكس البالغ **40 A** ($14.71 \text{ A} \le 40 \text{ A}$).

### خلاصة التوافقية الكهربائية للمصفوفة والعاكس

تؤكد الحسابات الرقمية المبنية على وثائق البيانات الرسمية لكل من اللوح **LONGi LR5-72HTH-600M** والعاكس **Huawei SUN2000-25KTL-M5** نجاح التصميم الكهربائي ومطابقته التامة للمواصفات القياسية؛ حيث تقع جميع قيم الجهود والتيارات الحرارية للمنظومة صيفاً وشتاءً في قلب النطاقات الآمنة والفعالة تشغيلياً، مما يضمن استمرارية الاستثمار وبقاء المنظومة تعمل بأعلى كفاءة تحويل ممكنة طوال عمرها التشغيلي.

# الطور الرابع: الحمايات والترابط الكهربائي

سنبدأ مباشرةً بالعمل على **الفقرة (10 - 19 - 1)** و **(10 - 19 - 2)** من الطور الرابع، بناءً على بيانات الألواح والعاكس التي اعتمدتها في الأطوار السابقة، ووفقاً للمنهجية الهندسية الواردة في المراجع:

---

## 10 - 17 مقدمة الطور الرابع

ملاحظة : لم أعمل على المقدمة بعد

## 10 - 18 حسابات واختيار مكونات الجانب المستمر (DC Side)

### 10 - 18 - 1 حسابات واختيار كابلات السلاسل (String Cables Sizing)

تُمثل كابلات الجانب المستمر (DC Side) الشرايين الحيوية لنقل الطاقة الكهربائية المولدة من الخلايا الشمسية إلى مداخل العاكس الذكي. ونظراً لطبيعة تشغيل هذه الكابلات في بيئة السطح الخارجية القاسية، فإن تحجيمها واختيار مواصفاتها الفيزيائية لا يتوقف فقط عند تلبية سعة تيار التشغيل، بل يخضع لقيود حرارية وبيئية صارمة، بالإضافة إلى قيد هبوط الجهد لضمان استقرار عمل خوارزميات تتبع نقطة القدرة القصوى ($MPPT$) وتقليص الفواقد الطاقية.

#### أولاً: الحساب الرياضي لتيار التصميم الأقصى للسلسلة ($I_{\text{dc\_max}}$)

تفرض الأكواد والمعايير الدولية (مثل $IEC\ 60364-7-712$ و $NEC\ Art.\ 690$) تطبيق معامل أمان يبلغ ($1.25$) على تيار القصر للوح الكهروضوئي ($I_{sc}$) عند حساب تيار التصميم الأقصى للحمايات والموصلات في الجانب المستمر. يهدف هذا المعامل إلى استيعاب الفترات التشغيلية التي يتجاوز فيها الإشعاع الشمسي الفعلي حدود الظروف القياسية ($STC = 1000\text{ W/m}^2$) نتيجة الانعكاسات السحابية أو الظواهر الجوية المؤقتة.

بالاعتماد على بيانات اللوح المعتمد في المشروع من طراز **LONGi Hi-MO 6 (LR5-72HTH-600M)**، فإن قيمة تيار القصر تبلغ:

$$I_{sc} = 14.46\text{ A}\quad \text{}$$

يتم حساب تيار التصميم الأقصى للسلسلة الواحدة وفق العلاقة التالية:

$$I_{\text{dc\_max}} = I_{sc} \times 1.25$$

$$I_{\text{dc\_max}} = 14.46\text{ A} \times 1.25 = 18.075\text{ A}$$

بناءً على هذه القيمة، يجب أن تكون السعة الأمبيرية المستمرة للموصل المختصر بعد التصحيح الحراري أعلى من تيار التصميم المقدر بـ $18.075\text{ A}$.

#### ثانياً: تطبيق معاملات التصحيح الحراري وظروف التمديد (Derating Factors)

تتعرض كابلات السلاسل الكهروضوئية الممددة فوق هيكل التثبيت أو داخل مجاري الكابلات (Cable Trays) على السطح لإجهاد حراري تراكمي مرتفع. وبما أن طقس مدينة حلب صيفاً يتسم بالحرارة المرتفعة، حيث تصل حرارة أسطح العمل المعرضة للإشعاع المباشر إلى $60^{\circ}\text{C}$، يتوجب تطبيق معايير الكود القياسي $IEC\ 60364-5-52$ لتصحيح السعة الأمبيرية الاسمية للكابلات.

الكابلات الشمسية المتخصصة تعتمد عازلاً متطوراً من البولي أوليفين المتشابك ($XLPO/XLPE$) ذي درجة حرارة تشغيل قصوى للموصل تبلغ $90^{\circ}\text{C}$ أو $120^{\circ}\text{C}$.

- عند درجة حرارة محيطة بالسطح تصل إلى $60^{\circ}\text{C}$، يبلغ معامل التصحيح الحراري ($k_{\theta}$) لعازل الـ $90^{\circ}\text{C}$ الممدد في الهواء الحر أو القنوات حوالي **$0.71$** وفقاً لجداول التصحيح القياسية في الكود الدولي (ألقي نظرة على [[الملحق ت]]).
    
- بالرجوع إلى كتالوج شركة السويدي للكابلات للأنظمة الشمسية (ألقي نظرة على [[الملحق ت]])، نجد أن السعة الأمبيرية الاسمية لكابل النحاس الشمسي الموضوع في الهواء الطلق أحادي النواة (Core-1) ذو المقطع $4\ mm^2$ عند درجة الحرارة المرجعية ($30^{\circ}\text{C}$) تبلغ $47\ \text{A}$ في حال التمديد المتلامس (Flat Touched)، و $65 \text{ A}$ في حال التمديد المتباعد (Flat Separated). نظراً لأن كابلات السلاسل الشمسية تمدد عادةً داخل قنوات أو في مسارات متقاربة على السطح، فإن القيمة الأدق والأكثر أماناً هي **$47\ \text{A}$**.

يتم حساب السعة الأمبيرية المصححة الفعالية للكابل ($I_{\text{allowable}}$) كالتالي:

$$I_{\text{allowable}} = I_{\text{nominal}} \times k_{\theta}$$

$$I_{\text{allowable}} = 47\text{ A} \times 0.71 = 33.37\text{ A}$$

بمقارنة السعة الأمبيرية المصححة ($33.37\text{ A}$) مع تيار التصميم الأقصى للسلسلة ($18.075\text{ A}$)، نجد أن:

$$I_{\text{allowable}} \ge I_{\text{dc\_max}} \implies 33.37\text{ A} \ge 18.075\text{ A}$$

وبالتالي، فإن المقطع الفيزيائي $4\text{ mm}^2$ آمن تماماً من الناحية الحرارية (Thermal Ampacity) ولا يوجد أي خطر من انهيار العازل أو ارتفاع حرارة الموصل فوق الحدود التشغيلية الآمنة تحت أقصى ظروف الصيف التشغيلية.

#### ثالثاً: تحديد المواصفات الفيزيائية والمقطع الفيزيائي الأنسب

بناءً على التحليل الحراري المتقدم، يُمنع منعاً باتاً استخدام كابلات التيار المتردد ($AC$) التقليدية ذات غلاف الـ $PVC$ في تمديدات الجانب المستمر، لتفادي التفكك السريع للغلاف بفعل الأشعة فوق البنفسجية وما ينتج عنه من انهيار عازلية وقوس كهربائي مستمر ($DC\ Arc$) يصعب إطفاؤه.

لذا، تم اعتماد **كابلات طاقة شمسية متخصصة (Solar PV Cables)** مطابقة للمواصفة القياسية الأوروبية **$EN\ 50618$** بالمواصفات التالية:

1. **الموصل (Conductor):** نحاس مرن متعدد النوى مكسو بالقصدير (Tinned Copper) لمقاومة التأكسد والتآكل الكيميائي الناتج عن الرطوبة والعوامل الجوية.
    
2. **العزل والغلاف (Insulation & Jacket):** عزل مزدوج (Double Insulation) من مادة البولي أوليفين المتشابك خالية من الهالوجين ومنخفضة انبعاث الدخان ($LSZH / XLPO$).
    
3. **المقاومة البيئية:** مقاومة عالية للأشعة فوق البنفسجية ($UV-Resistant$)، وغاز الأوزون، والانتشار اللهبي، ومصممة لعمر تشغيلي يتجاوز 25 عاماً ليتوافق مع عمر الألواح.

للمفاضلة بين اختيار المقطع **$4\text{ mm}^2$** أو **$6\text{ mm}^2$**، سيتم الاحتكام إلى المحدد الرياضي الثالث والحاسم وهو "قيد هبوط الجهد المسموح" لتقليص الفواقد الحثية والأومية.

#### رابعاً: حساب هبوط الجهد في جانب التيار المستمر ($DC\ Voltage\ Drop$)

تفرض الممارسة الهندسية الرصينة ألا يتجاوز هبوط الجهد في جانب التيار المستمر نسبة **$\le 1\%$** لضمان عدم إزاحة وتشويه قيمة الجهد الواصل إلى دخل العاكس الكهروضوئي، مما يحمي كفاءة عمل منظم الـ $MPPT$ ويمنع هدر الطاقة الاستثمارية للمنظومة.

**المعطيات التصميمية للحساب الرياضي:**

- عدد ألواح السلسلة الواحدة ($N$) = $13$ لوحاً موصولة على التوالي.
- تيار التشغيل الفعلي للسلسلة عند نقطة القدرة القصوى ($I_{mp}$) = $13.44\text{ A}$.
- جهد التشغيل الاسمي للسلسلة عند الشروط المعيارية ($V_{\text{string\_STC}}$):
    $$V_{\text{string\_STC}} = 13 \times V_{mp} = 13 \times 44.66\text{ V} = 580.58\text{ V}\quad \text{}$$
    
- جهد التشغيل الأدنى المتوقع للسلسلة صيفاً عند حرارة خلايا $60^{\circ}\text{C}$ (من حسابات الفقرة 10-14):
    $$V_{\text{string\_summer}} = 13 \times V_{mpp\text{-}min} = 13 \times 40.127\text{ V} = 521.65\text{ V}\quad \text{}$$
    
- طول مسار الكابل الفعلي التقديري (من أبعد لوح في المصفوفة وحتى موقع العاكس) = $L = 30\text{ m}$. وبما أن التوصيل يمثل دائرة مغلقة (ذهاب وإياب لطرفي الموجب والسالب)، فإن الطول الإجمالي للموصل المار فيه التيار هو:
    $$L_{\text{total}} = 2 \times L = 2 \times 30 = 60\text{ m}$$
- المقاومة النوعية للنحاس المصححة حرارياً عند متوسط درجة حرارة تشغيل الكابل تحت أشعة الشمس المستمرة ($\approx 70^{\circ}\text{C}$)، وتحسب من العلاقة :
$$\rho_{70} = \frac{R_{70} \times A}{L}$$
**حيث أن:**

- **$\rho_{70}$ (Resistivity):** هي المقاومة النوعية للمادة عند درجة حرارة ($70^{\circ}\text{C}$)، وتُقاس عادةً في الحسابات الكهربائية بواحدة عند درجة حرارة تشغيل الكابل ($\Omega\cdot\text{mm}^2/\text{m}$).
- **$R_{70}$ (Resistance):** هي مقاومة الناقل عند درجة حرارة ($70^{\circ}\text{C}$)، وواحدتها ($\Omega/\text{km}$).
- **$A$ (Cross-sectional Area):** هي مساحة مقطع الموصل بواحدة ($\text{mm}^2$).
- **$L$ (Length):** هو الطول، وبما أن المقاومة في الكتالوج معطاة لكل كيلومتر، فإننا نستخدم $1000$ متر لتحويل الواحدة.

نقوم بحساب مقاومة الناقل عند درجة حرارة $70^{\circ}\text{C}$ ، بناءا على معادلة التصحيح الحراري:
$$R_{70} = R_{20} \times [1 + \alpha \times (\theta - 20)]$$
_حيث:_

- $R_{20} = 4.61\ \Omega/km$ (من جدول الكابل المعتمد ذو المقطع $4\ mm^2$).
- $\alpha = 0.00393$ (المعامل الحراري للنحاس)،.
- $\theta = 70^{\circ}C$ (متوسط درجة حرارة تشغيل الكابل تحت الشمس)،.

**الحساب العددي:**
$$R_{70} = 4.61 \times [1 + 0.00393 \times (70 - 20)] = 4.61 \times 1.1965 \approx \mathbf{5.516\ \Omega/km}$$
بالتعويض في قانون المقاومة النوعية:
$$\rho_{20} = \frac{5.516\ \Omega/\text{km} \times 4\text{ mm}^2}{1000\text{ m}}$$ $$\rho_{20} = \mathbf{0.0220\ \Omega\cdot\text{mm}^2/\text{m}}$$
يُحسب هبوط الجهد بالقيمة المطلقة ($\Delta V$) وفق العلاقة الكلاسيكية لتيار المستمر:
$$\Delta V = \frac{2 \times L \times I_{mp} \times \rho}{A}$$
حيث أن ($A$) يمثل المقطع العرضي للموصل بـ ($\text{mm}^2$).
##### الحالة الأولى: التحقق عند استخدام مقطع كابل $A = 4\text{ mm}^2$

1. **قيمة هبوط الجهد الفعلي:**
    $$\Delta V = \frac{2 \times 30\text{ m} \times 13.44\text{ A} \times 0.0220\ \Omega\cdot\text{mm}^2/\text{m}}{4\text{ mm}^2} = 4.435\text{ V}$$
2. **النسبة المئوية لهبوط الجهد عند الشروط القياسية ($STC$):**
    $$\%\Delta V_{\text{STC}} = \left( \frac{\Delta V}{V_{\text{string\_STC}}} \right) \times 100\% = \left( \frac{4.435\text{ V}}{580.58\text{ V}} \right) \times 100\% = 0.763\%$$
3. **النسبة المئوية لهبوط الجهد في أشد أيام الصيف حرارة (أقل جهد تشغيلي للمصفوفة):**
    $$\%\Delta V_{\text{summer}} = \left( \frac{\Delta V}{V_{\text{string\_summer}}} \right) \times 100\% = \left( \frac{4.435\text{ V}}{521.65\text{ V}} \right) \times 100\% = 0.85\%$$
نلاحظ أن النسبة المئوية لهبوط الجهد في الحالتين ($0.763\%$) و ($0.85\%$) تقع بأمان تام **دون الحد الأكاديمي الصارم المعين بـ $\le 1\%$**.

##### الحالة الثانية: التحقق عند استخدام مقطع كابل $A = 6\text{ mm}^2$

في حال الرغبة في خفض المفاقيد الأومية إلى أدنى مستوى تشغيلي ممكن، نختبر مقطع $6\text{ mm}^2$:

1. **قيمة هبوط الجهد الفعلي:**
    $$\Delta V = \frac{2 \times 30\text{ m} \times 13.44\text{ A} \times 0.022\ \Omega\cdot\text{mm}^2/\text{m}}{6\text{ mm}^2} = 2.956\text{ V}$$
    
2. **النسبة المئوية لهبوط الجهد صيفاً:**
    $$\%\Delta V_{\text{summer}} = \left( \frac{2.956\text{ V}}{521.65\text{ V}} \right) \times 100\% = 0.566\%$$

#### الخلاصة والقرار الهندسي للتصميم:

- من الناحية الفنية والمعيارية، يحقق المقطع **$4\text{ mm}^2$** المتطلبات الكهربائية والأمنية بشكل ممتاز؛ فهو يتحمل السعة الأمبيرية المطلوبة صيفاً بأمان عالي ($33.37\text{ A} \ge 18.075\text{ A}$)، ويحافظ على هبوط الجهد تحت عتبة الـ $1\%$ القياسية محققاً نسبة ($0.85\%$).
    
- **التوصية التطبيقية:** يتم اعتماد كابلات طاقة شمسية بمقطع **$4\text{ mm}^2$** كمعيار عام لكافة السلاسل القريبة والمتوسطة البعد من العاكس نظراً لجدواها الاقتصادية العالية ومرونتها الميكانيكية العالية أثناء التمديد، بينما يُوصى هندسياً برفع المقطع إلى **$6\text{ mm}^2$** فقط للسلسلة الأكثر بعداً على السطح (في حال تجاوز طول المسار الواحد $35$ متراً في الواقع التشغيلي) كإجراء تحسيني لرفع كفاءة المنظومة الإجمالية وتقليل الهدر الحراري إلى أدنى حد ممكن.

### **10 - 18 - 2 حساب وتوصيف مصاهر حماية السلاسل (String Fuses Selection)**

تُمثّل مصاهر حماية السلاسل (String Fuses) خط الدفاع الموضعي الأول لحماية الخلايا الكهروضوئية والموصلات في الجانب المستمر (DC Side) ضد مخاطر تيارات الخطأ الزائدة وتيارات القصر العكسية. ويخضع اختيار وتوصيف هذه المصاهر لمعايير دولية صارمة، أبرزها المعيار العالمي للمصهرات الشمسية **IEC 60269-6** (الفئة المعيارية **gPV**) والمعيار **IEC 60364-7-712** الخاص بمتطلبات التمديدات الكهروضوئية. تهدف هذه الفقرة إلى إجراء الحساب العددي الدقيق للسعة الاسمية للمصهر وتحليل متراجحات الحماية والربط الانتقائي لضمان الموثوقية التشغيلية ومنع أي فصل عشوائي (Nuisance Tripping).

### أولاً: الحساب العددي لسعة المصهر الاسمي ($I_{fuse}$)

تستند الممارسة الهندسية في حساب السعة الاسمية لمصهر السلسلة إلى تيار القصر للوح الشمسي عند الشروط المعيارية ($I_{sc}$)، مع تطبيق معامل أمان يحقق معايير الاستقرار التشغيلي ويبلغ $1.56$. هذا المعامل ($1.56$) هو نتاج دمج معاملي أمان؛
- الأول ($1.25$) لمواجهة تأثير استمرار التشغيل لفترات طويلة وتجنب التقادم الحراري المبكر للمصهر نتيجة التيارات المستمرة،
- الثاني ($1.25$) لحماية النظام من ظاهرة الارتفاع المفاجئ لشدة الإشعاع الشمسي فوق القيم المعيارية نتيجة انعكاسات الغيوم (Cloud Enhancement Effect) الحاصلة في الموقع التشغيلي.

بالرجوع إلى البيانات الفنية للوح المعتمد في المشروع **LONGi Hi-MO 6** (طراز _LR5-72HTH-600M_)، نجد أن تيار القصر يبلغ:
$$I_{sc} = 14.46 \text{ A}$$
تُحسب السعة الدنيا المحسوبة للمصهر ($I_{fuse\_calc}$) وفق العلاقة التالية:

$$I_{fuse\_calc} = I_{sc} \times 1.56$$
$$I_{fuse\_calc} = 14.46 \text{ A} \times 1.56 = 22.5576 \text{ A}$$
بناءً على هذه النتيجة الرقمية، يتم اختيار السعة القياسية التجارية الأعلى مباشرة والمصممة خصيصاً لحماية الأنظمة الشمسية الكهروضوئية (gPV)، وهي $I_{fuse} = 25 \text{ A}$ وجهد تشغيل لا يقل عن **1000 Vdc** لضمان التوافق مع جهد المصفوفة.

### ثانياً: التحقق من قيود حماية اللوح (Module Bounding Constraints)

لضمان سلامة الألواح من التلف الفيزيائي وخطر الحريق، تشترط المعايير الهندسية وأكواد التصنيع ألا تتجاوز السعة الاسمية للمصهر المختار قيمة "أقصى سعة لمصهر السلسلة" (Maximum Series Fuse Rating) المحددة صراحة من قِبل الشركة المصنعة للوح في ورقة البيانات الفنية. بالعودة لكتالوج لوح LONGi المعتمد، نجد أن هذه القيمة تبلغ:
$$I_{fuse\_max\_module} = 25 \text{ A}$$
بذلك، يتم صياغة متراجحة التحقق والامتثال الآتية:
$$I_{fuse\_calc} \le I_{fuse} \le I_{fuse\_max\_module}$$
$$22.56 \text{ A} \le 25 \text{ A} \le 25 \text{ A}$$
بما أن السعة المختارة ($25 \text{ A}$) تحقق المتراجحة الهندسية تماماً وتتطابق مع الحد الأقصى المسموح به من المصنع، فإن هذا الاختيار يضمن حماية مثالية للألواح؛ حيث يتحمل المصهر التيارات العابرة الطبيعية دون تقادم، وفي الوقت نفسه يحمي خلايا اللوح من الانهيار في حال حدوث خطأ.

### ثالثاً: التحقق العملي من التنسيق الحمائي

تعتمد المنهجية الهندسية في اختيار المصهرات والكابلات على علاقة متراجحة صارمة، تصاغ رياضياً لضمان عدم وصول الموصل إلى مرحلة الانهيار الحراري أو ذوبان العازل قبل أن تقوم أداة الحماية بفصل الدائرة:
$$\text{Cable Ampacity } (I_z) \ge I_{fuse/breaker} \ge I_{design} (I_b)$$
تعريف أطراف المتراجحة أكاديمياً وفق الآتي:

1. **$I_{design}$ (تيار التصميم):** هو أقصى تيار تشغيلي متوقع مرورُه في السلسلة (بعد ضرب تيار القصر بمعاملات الأمان)، ويجب أن يكون المصهر قادراً على تمريره دون فصل زائف (Nuisance Tripping).
2. **$I_{fuse}$ (سعة المصهر الاسمية):** هي عتبة التحسس الحراري للمصهر، وتُختار لتكون أعلى من تيار التصميم ولكن أقل من قدرة الكابل الفيزيائية.
3. **$I_z$ (السعة الأمبيرية المصححة للكابل):** هي أقصى تيار يمكن للموصل تحمله في بيئة تشغيله الواقعية (بعد خفضه بمعاملات التصحيح الحراري $f_{derating}$)، ويجب أن تظل هذه القيمة هي الأعلى دائماً لضمان بقاء الكابل في المنطقة الآمنة حرارياً.

المعطيات الرقمية التصميمية للمنظومة:

1. **تيار التصميم الأقصى للسلسلة ($I_{\text{dc\_max}}$):** تم حسابه بـ **$18.075\text{ A}$** (بناءً على تيار القصر للوح $14.46\text{ A} \times 1.25$).
2. **سعة المصهر الاسمي المختارة ($I_{fuse}$):** تم اعتماد سعة **$25\text{ A}$** من الفئة gPV.
3. **السعة الأمبيرية المصححة للكابل صيفاً ($I_z$):** لمقطع **$4\text{ mm}^2$** عند حرارة سطح $60^{\circ}\text{C}$ بلغت **$33.37\text{ A}$**.
4. **أقصى سعة مصهر مسموح بها للوح ($I_{fuse_max_module}$):** وفق ورقة بيانات LONGi تبلغ **$25\text{ A}$**.

بتطبيق المتراجحة على القيم الفعلية للمشروع، نجد أن: 

$$33.37\ \text{ A} \ge 25\text{ A} \ge 18.075\text{ A}$$

**الاستنتاج الهندي من المتراجحة المحققة:**

- **ضمان استمرارية التشغيل:** بما أن ($25\text{ A} > 18.075\text{ A}$)، فإن المصهر لن يسبب أي فصل زائف (Nuisance Tripping) أثناء ذروة الإشعاع الشمسي أو فترات "تعزيز الغيوم".
- **ضمان الحماية الحرارية للموصل:** بما أن ($33.37\text{ A} > 25\text{ A}$)، فإن المصهر سيعمل كـ "حلقة أضعف كهربائياً" ويفصل الدائرة عند حدوث أي عطل قبل أن تصل حرارة الكابل إلى العتبة الحرجة التي تسبب ذوبان العازل XLPE أو نشوب حريق.

### رابعاً: تطبيق متراجحة الحماية والانتقائية الكهربائية ضد تيارات القصر العكسية

تنشأ تيارات القصر العكسية (Reverse Fault Currents) عند حدوث عطل قصر صريح (Short Circuit) في إحدى السلاسل الكهروضوئية (بسبب انهيار العزل، أو حدوث خطأ أرضي، أو تلف ديودات العبور Bypass Diodes)، مما يؤدي إلى انخفاض جهد هذه السلسلة وتحولها إلى حمل يتدفق إليه التيار من بقية السلاسل السليمة المربوطة معها على التوازي.

وفقاً للمعيار الدولي **IEC 60364-7-712**، يُحسب تيار الخطأ العكسي الأقصى المتوقع تدفقه إلى السلسلة المعيبة بناءً على عدد السلاسل المتوازية ($N_s$) المربوطة على نفس النقطة الكهربائية (نفس متعقب الـ MPPT) عبر المعادلة:
$$I_{reverse\_max} = (N_s - 1) \times I_{sc}$$

لتحليل الحاجة الفنية وتحقيق الانتقائية الكهربائية في منظومتنا، نراجع التوزيع الكهربائي الفعال للسلاسل الثلاث على متعقبات القدرة للعاكس الذكي _Huawei SUN2000-25KTL-M5_ المعتمد في الفقرة (10-16):

1. **حالة المتتبع الأول (MPPT 1):** يتصل عليه سلسلتان على التوازي ($N_s = 2$).
    $$I_{reverse\_max} = (2 - 1) \times 14.46 \text{ A} = 14.46 \text{ A}$$
    
    من وجهة نظر الأكواد الصارمة، بما أن تيار القصر العكسي الأقصى القادم من السلسلة السليمة الموازية ($14.46 \text{ A}$) هو أقل من قدرة تحمل الألواح للتيار العكسي ($25 \text{ A}$)، فإن الألواح تمتلك أماناً ذاتياً بطبيعتها الفيزيائية ضد تيارات القصر العكسية البينية، ولا يُعد تركيب المصهر إلزامياً معيارياً لحمايتها من السلاسل الموازية في هذه الحالة المحددة.
    
2. **حالة المتتبع الثاني (MPPT 2):** تتصل عليه سلسلة واحدة منفردة ($N_s = 1$).
    $$I_{reverse\_max} = (1 - 1) \times 14.46 \text{ A} = 0 \text{ A}$$
    
    في هذه الحالة، تنعدم احتمالية تدفق تيار عكسي من سلاسل أخرى نظراً لعدم وجود ربط متوازٍ على هذا المدخل.

**القرار الهندسي والتوصيف التطبيقي للمشروع:**

على الرغم من أن المعايير الدولية لا تفرض تركيب مصهرات للسلاسل في حال كان عدد السلاسل المتوازية لكل متتبع مساوياً أو أقل من اثنين ($N_s \le 2$)، إلا أنه **تم اعتماد تركيب مصاهر حماية مستقلة لكل سلسلة من السلاسل الثلاث** بسعة $25 \text{ A}$ وجهد تشغيلي $1000 \text{ VDC}$ من الفئة gPV داخل لوحة تجميع عزل الجانب المستمر، وذلك استناداً للمسوغات الهندسية الأكاديمية والتشغيلية التالية:

1. **الحماية من تيار التفريغ العكسي للعاكس (Inverter Back-feed):** يؤدي حدوث عطل أرضي أو قصر في كابلات السلسلة إلى تفريغ مفاجئ وعنيف للطاقة المخزنة في مكثفات دارة التنعيم (DC-Link) للعاكس نحو نقطة العطل بتيار ضخم؛ مما يستلزم وجود مصهر gPV سريع لعزل العطل وحماية المكونات الإلكترونية الحساسة للعاكس.
    
2. **تحقيق الانتقائية المطلقة (Absolute Discrimination):** تضمن الخصائص الزمنية-الأمبيرية للمصهر (Time-Current Curves) سرعة فصل فائقة تقع بالكامل تحت منحنى فصل القاطع الرئيسي للجانب المستمر، مما يضمن عزل السلسلة المعطوبة موضعياً دون تفعيل القاطع الرئيسي ودون إطفاء كامل الحقل الشمسي، حفاظاً على استمرارية التشغيل ومعدل الأداء (PR).
    
3. **تيسير الصيانة وعزل الأحمال آمنياً:** تعمل حوامل المصهرات (Fuse Holders) كأداة فصل ميكانيكي يدوي آمن، تتيح لفنيي الصيانة عزل وتتبع أعطال كل سلسلة، وإجراء اختبارات مقاومة العزل (Isolation Resistance) بشكل مستقل دون الحاجة لإيقاف المحطة بالكامل.

### خامساً: المواصفات الفنية الهندسية للمصاهر المختارة

بناءً على الحسابات والتحليلات المتقدمة السابقة، يتم توصيف مصاهر حماية السلاسل هندسياً وتجارياً لإدراجها في جداول الكميات (BOQ) كما يلي:

- **نوع وحجم المصهر:** مصهر أسطواني مخصص للأنظمة الكهروضوئية (Cylindrical Solar PV Fuse-Link).
- **الفئة التشغيلية المعيارية:** gPV (وفق المعيار الدولي IEC 60269-6 لقطع تيارات القصر المستمرة بفعالية وسرعة فائقة).
- **السعة الاسمية المقننة ($I_n$):** $25 \text{ A}$.
- **الجهد الاسمي الأقصى المستمر ($V_n$):** $1000 \text{ V DC}$ (يغطي بأمان تام جهد الدارة المفتوحة الحرجة للسلسلة شتاءً والمحسوب في الفقرة 10-15).
- **سعة القطع المقننة (Breaking Capacity - $I_{1}$):** $30 \text{ kA}$، لضمان الصمود الميكانيكي والكهربائي والقدرة على إخماد القوس الكهربائي المستمر (DC Arc) بأمان عند الفصل تحت ظروف الخطأ القصوى.

### 10 - 18 - 3 قواطع الفصل والعزل لمدخل العاكس (Main DC Isolators / Breakers)

يُعد توفير وسيلة فصل وتوصيل ميكانيكية عند مدخل التيار المستمر للعاكس متطلباً معيارياً تفرضه المواصفة **IEC 60364-7-712** لضمان سلامة الفنيين أثناء الصيانة ولتمكين العزل الفوري في حالات الطوارئ. وبما أن عاكس **Huawei 25KTL** يحتوي على مفتاح DC مدمج (Integrated DC Switch)، إلا أن التصميم الهندسي يقتضي وجود قواطع خارجية إضافية ضمن صندوق الحماية لتوفير حماية احتياطية وعزل مرئي قبل دخول الكابلات إلى جسم العاكس.

#### حساب وتوصيف قواطع المداخل (MPPT Breakers)

يتم اختيار قواطع عزل التيار المستمر (DC Switch-Disconnectors / Isolators) بناءً على معيارين أساسيين:
#### 1. جهد عزل القاطع : 

يجب أن يكون جهد العزل السمي للقاطع ($U_n$) أكبر من أقصى جهد دائرة مفتوحة للمصفوفة عند أدنى درجة حرارة متوقعة ($V_{oc\_max}$). من الحسابات السابقة (في الفقرة [[10 - 14 التحليل الحراري الحرج لجهود الألواح الكهروضوئية]]) نجد أن الجهد الأقصى للوح الواحد عند أدنى درجة حرارة ($0^{\circ}\text{C}$) هي $V_{oc\_max} = 56.64 \text{ V}$ ومن أجل السلسلة الواحدة : 
$$V_{series\_oc\_max} = 13 \times 56.64 = 736.32 \text{ V}$$
بناءا عليه نجد أقرب قيمة جهد تشغيل قياسية مناسبة للقاطع هي **$1000\text{ Vdc}$**.

#### 2. تيار تصميم القاطع :

يجب أن يتحمل القاطع تيار التصميم المحسوب بتطبيق معامل أمان ($1.25$) على تيار القصر الإجمالي لكل مدخل MPPT لضمان عدم الفصل الحراري الناتج عن زيادة الإشعاع.

وفقاً لتوزيع السلاسل المعتمد في مشروعك، حيث كل مدخل من مداخل العاكس تصل إلى سلسلة واحدة (13 لوح)، ومن مواصفات الفنية للوح المعتمد نجد أن تيار القصر هو $I_{sc} = 14.46 \text{ A}$، وبتطبيق معامل الأمان نجد أن تيار التصميم يساوي :    
$$I_{breaker} = 14.46 \times 1.25 = \mathbf{18.075\text{ A}}$$
وبالتالي لتوحيد المكونات وتسهيل الصيانة، سيتم اعتماد قاطع بسعة **$32\text{ A}$** وجهد **$1000\text{ Vdc}$**، حيث بما أن جهاز العزل المستخدم هو مفتاح قطع تحت الحمل، ووظيفته الوحيدة هي تحمل التيار المستمر الكامل وقطعه يدوياً بأمان أثناء الصيانة، **ولا يحتوي على ميكانيكية فصل تلقائي** للأعطال، فيجب أن تكون السعة الأمبيرية للمفتاح أكبر من أو تساوي تيار المصهر ($I_{switch} \ge I_{fuse}$) وما هو تم تحقيقة في في خيارنا :
$$32 \text{ A (switch)} \ge 25 \text{ A (fuse)}$$
#### المواصفات الفنية المعتمدة للقواطع

لضمان الصمود أمام الظروف الجوية القاسية فوق سطح البنك، تم توصيف القواطع بالمواصفات التالية:

- **النوع:** قاطع تيار مستمر ثنائي القطب (2-Pole DC MCB).
- **آلية الإخماد:** مزود بغرف إخماد مغناطيسية لتقسيم وإطفاء القوس الكهربائي المستمر.
- **القطبية:** غير قطبي (Non-Polarized) لتجنب مخاطر الاحتراق في حال عكس التوصيل أثناء التركيب.
- **درجة الصمود:** قادرة على العمل ضمن نطاق حراري من $-25^{\circ}\text{C}$ إلى $+60^{\circ}\text{C}$ بما يتوافق مع بيئة عمل العاكس.

### 10 - 18 - 4 اختيار مانعات الصواعق للجهود العابرة (DC Surge Protective Devices - SPDs)

تخضع عملية اختيار مانعات الصواعق في الجانب المستمر لمعايير اللجنة الكهروتقنية الدولية **IEC 61643-31**، حيث تهدف إلى حماية العاكس والألواح من ضربات الصواعق غير المباشرة أو الجهود العابرة الناتجة عن عمليات الفصل والوصل بالشبكة (Switching Surges). ويتم التوصيف الفني للمانع بناءً على المعايير التصميمية التالية:

#### **أولاً: تحديد فئة المانع (SPD Type)**

نظراً لوقوف مصفوفة الألواح فوق سطح منشأة حيوية (بنك) وفي بيئة مفتوحة، يتم اختيار مانع صواعق من **النمط الثاني (Type 2)**، وهو النمط الأكثر شيوعاً وفعالية لحماية العوازل الداخلية للعاكس من الحث الكهرومغناطيسي الناتج عن الصواعق القريبة.

>[!info] الجدير بالذكر
يتم تحديد فئة أو نمط المانع (SPD Type) بناءً على وجود نظام حماية خارجي من الصواعق (Lightning Protection System - LPS) للمنشأة:
> 
> - **النمط الأول (Type 1 / Class I):** يُختار إذا كانت المنشأة مزودة بنظام صواعق خارجي (مانعة صواعق قاسية/صاري)، أو إذا كانت المحطة في منطقة مفتوحة ذات معدل صواعق مرتفع جداً. يعتمد على تحمل تيار نزول الصاعقة المباشر ($I_{imp}$).
>     
> - **النمط الثاني (Type 2 / Class II):** يُختار لحماية العاكس والألواح من ضربات الصواعق غير المباشرة أو الجهود العابرة الناتجة عن عمليات الفصل والوصل بالشبكة (Switching Surges). وهو النمط الأكثر شيوعاً داخل صناديق تجميع الـ DC.
>     
> - **النمط الهجين (Type 1+2):** يُدمج في جهاز واحد ليوفر حماية ضد الضربات المباشرة وغير المباشرة معاً.

#### **ثانياً: حساب أقصى جهد تشغيل مستمر ($U_{cpv}$)**

يُعد هذا المعامل الأكثر حرجاً؛ حيث يجب أن يتحمل المانع جهد السلسلة الأقصى دون انهيار. حيث تفرض الأكواد الهندسية ألا يقل جهد المانع عن 110% من جهد المصفوفة الأقصى: 
$$U_{cpv} \ge 1.1 \times V_{oc_max_string}$$
وبما أن أقصى جهد دائرة مفتوحة للسلسلة عند درجة حرارة ($0^{\circ}C$) هو **$736.32\text{ V}$** :

$$U_{cpv} \ge 1.1 \times 736.32\text{ V} = \mathbf{809.95\text{ V}}$$
بناءاً عليه يتم اعتماد مانعة صواعق بجهد تشغيل قياسي **$1000\text{ Vdc}$** لضمان توافق تام مع جهد نظام العاكس المعتمد (1100 فولت).

#### **ثالثاً: مستوى حماية الجهد ($U_p$) وتنسيق العزل**

يجب أن يكون الجهد الذي "يسمح" المانع بمروره أثناء التفريغ ($U_p$) أقل من جهد تحمل عوازل العاكس النبضي ($U_w$):

- بما أن جهد المصفوفة لا يتجاوز 1000 فولت، فإن دخل العاكس يُصنف ضمن فئة الجهد الزائد الثانية (**OVC II**) بجهد تحمل نبضي معيري قدره **$4\text{ kV}$**
- بتطبيق هامش الأمان (20%): 
$$U_p \le 0.8 \times U_w = 0.8 \times 4\text{ kV} = \mathbf{3.2\text{ kV}}$$
- لذا تم اختيار مانع بـ ($U_p \le 3.2\text{ kV}$) لضمان عدم تعرض الدوائر الإلكترونية داخل عاكس Huawei للتلف.

>[!info] كيف تستنتج القيمة $U_w$ من الجدول المعياري؟
تُقسم هذه المعايير أطراف العاكس الشمسي إلى فئتين من فئات الجهد الزائد (OVC):
> 
> - **جانب التيار المستمر (DC Side):** يُصنف هندسياً ضمن الفئة الثانية للجهد الزائد **(Overvoltage Category II - OVC II)**.
>     
> - **جانب التيار المتردد (AC Side):** يُصنف ضمن الفئة الثالثة للجهد الزائد **(Overvoltage Category III - OVC III)** لأنه يتصل مباشرة بشبكة التوزيع المعرضة لعمليات الفصل والوصل والضربات الجوية.
>     
> بمعرفة الجهد التشغيلي للنظام وفئة الـ OVC، تحدد المواصفة قيمة الجهد النبضي القياسي الواجب على المعدة تحمله:
> 
> - **أنظمة الـ DC بجهد اسمي حتى 1000 فولت (تحت فئة OVC II):** القيمة القياسية لجهد التحمل النبضي هي **$U_w = 4000 \text{ V}$ (أي $4 \text{ kV}$)**.
>     
> - **أنظمة الـ DC الحديثة بجهد اسمي 1500 فولت (تحت فئة OVC II):** القيمة القياسية لجهد التحمل النبضي هي **$U_w = 6000 \text{ V}$ (أي $6 \text{ kV}$)**.
>     
> - **جانب الـ AC بجهد شبكة 230/400 فولت (تحت فئة OVC III):** القيمة القياسية لجهد التحمل النبضي لعوازل مخرج العاكس هي **$U_w = 4000 \text{ V}$ (أي $4 \text{ kV}$)**.
> 
#### **رابعاً: سعة تيارات التفريغ ($I_n$ & $I_{max}$)**

لضمان صمود المانع أمام النبضات المتكررة، تم توصيفه بالقيم المعيارية التالية:

- **تيار التفريغ الاسمي ($I_n$):** لا يقل عن **$20\text{ kA}$**.
- **تيار التفريغ الأقصى ($I_{max}$):** يصل إلى **$40\text{ kA}$**.
- **تيار القصر للمانع ($I_{scpv}$):** يجب أن يكون أكبر من تيار قصر المصفوفة ($14.46\text{ A}$)، وهو ما يتوفر في المانعات المختارة التي تتحمل تيار قصر داخلي يصل لـ **$1000\text{ A}$**.

أي سيتم تركيب مانعة صواعق **Type 2** لكل متعقب MPPT داخل صندوق حماية التيار المستمر، مع ربطها ببارة التأريض النحاسية بمسار لا يتجاوز طوله **0.5 متر** لتقليل مفاقيد الجهد الحثية أثناء التفريغ.

### 10 - 18 - 5 توصيف صندوق حماية وتوزيع التيار المستمر (DC Protection Box)

يُمثل صندوق حماية التيار المستمر الوحدة المركزية التي تجمع كافة عناصر الأمان الميكانيكية والكهربائية لجانب المصفوفة الكهروضوئية. وبما أن التصميم المعتمد في المشروع يعتمد على إدخال السلاسل مباشرة إلى مداخل الـ MPPT المستقلة في العاكس، فإن وظيفة هذا الصندوق تتحول من "تجميع التيارات" إلى "تنسيق الحمايات" وتوفير نقطة عزل آمنة وقريبة من المصفوفة قبل انتقال الطاقة إلى العاكس.
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

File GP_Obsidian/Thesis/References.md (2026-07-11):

[1]  GRID-CONNECTED SOLAR ELECTRIC SYSTEM، Geoff Stapleton and Susan Neill، eBook، 1 نيسان، 2026.
[2] فيزياء الطاقة الشمسية، سي جوليان تشِن، eBook، 3 نيسان، 2026.
[3] الطاقة الكهروشمسية Energy Photovoltaic، د.م كاميليا يوسف محمد، eBook، تاريخ الوصول : 10 نيسان، 2026.
[4] [Eng. Muhammad Eltahan](https://www.youtube.com/@Mohamed_ibrahim390)، "Solar systems design course، (كورس تصميم منظومات الطاقة الشمسية)"، دورة يوتيوب، تاريخ الوصول : 5 نيسان، 2026.
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

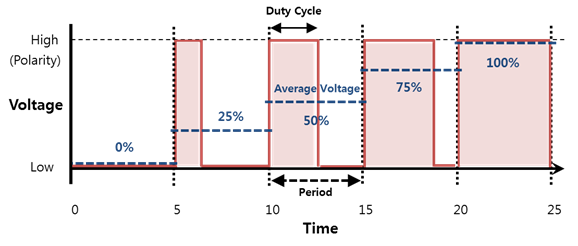
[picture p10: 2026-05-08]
Thesis_Typst/chapters/ch07/Figures/PV-07-07.png

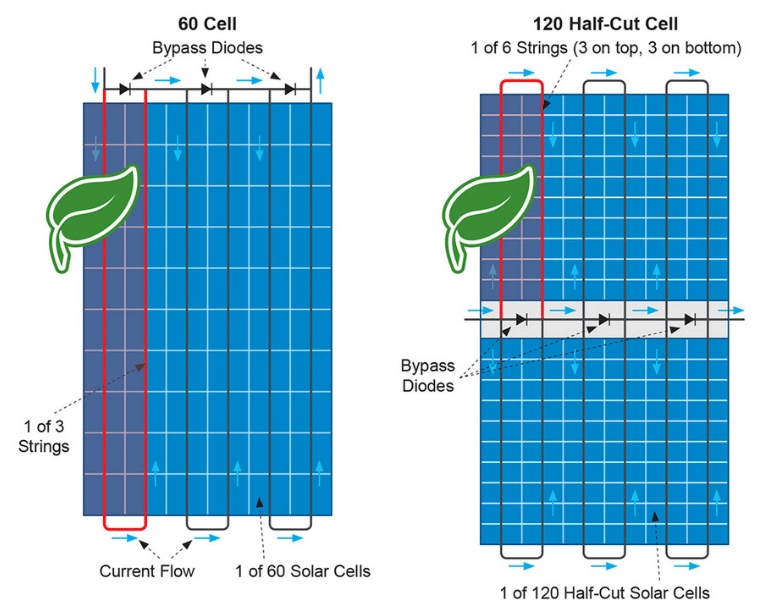
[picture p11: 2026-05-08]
Thesis_Typst/chapters/ch05/Figures/PV-05-07.png

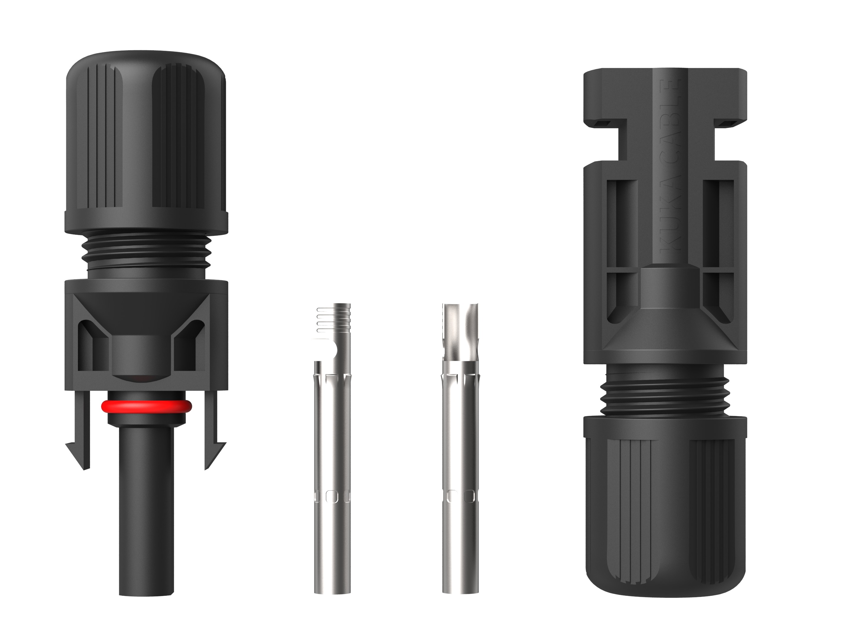
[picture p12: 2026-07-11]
Thesis_Typst/chapters/ch04/Figures/PV-04-17.jpg

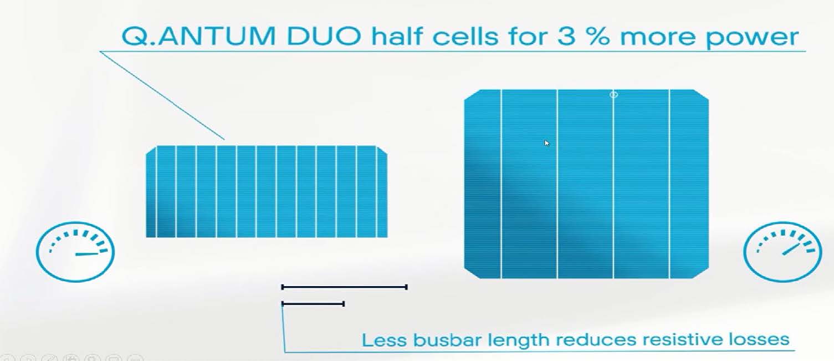
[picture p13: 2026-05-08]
Thesis_Typst/chapters/ch05/Figures/PV-05-03.jpg

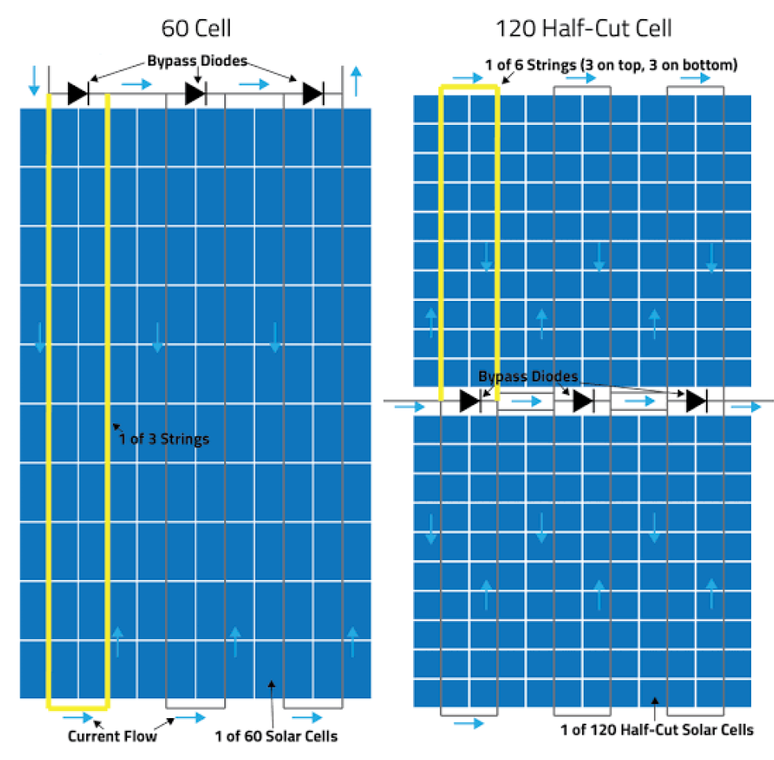
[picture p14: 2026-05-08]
Thesis_Typst/chapters/ch05/Figures/PV-05-05.png

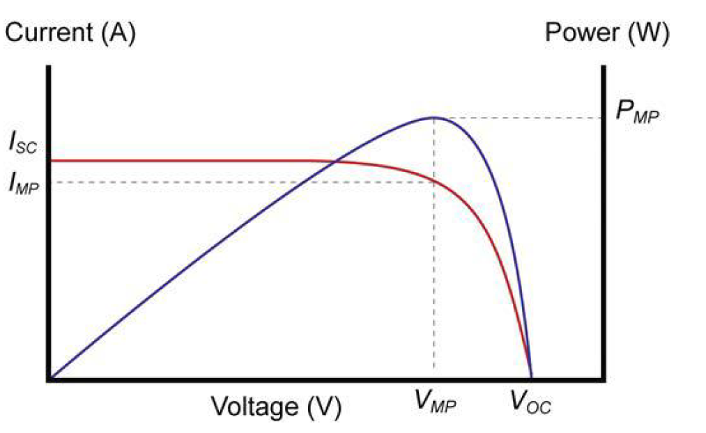
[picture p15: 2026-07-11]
Thesis_Typst/chapters/ch04/Figures/PV-04-10.png

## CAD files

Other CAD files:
AutoCAD/AutoCAD Blocks/Solar_Panel_600M.dwg
AutoCAD/SLD.dwg
AutoCAD/Bank - PV Power Design.dwg
AutoCAD/Bank.dwg
AutoCAD/Bank Electrical Design.dwg

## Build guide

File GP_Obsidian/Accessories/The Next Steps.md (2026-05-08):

## من اجل [[Thesis MOC|Thesis]] :

سأسأل الذكاء الصنعي عن : هل استطيع الاعتماد عليه في حساب عدد الألواح بالاعتماد على المساحة أم احتاج إلى متابعة كورس أو مصدر معين -- قدم لي كلمات مفتاحية لابحث عن مصادر اتعلم منها حساب عدد الاواح بناءا على المساحة

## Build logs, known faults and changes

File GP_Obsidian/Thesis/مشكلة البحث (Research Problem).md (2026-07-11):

تتمحور مشكلة البحث حول التحديات الهندسية والتقنية المرتبطة بتصميم ودمج أنظمة الطاقة الكهروضوئية المرتبطة بالشبكة (On-Grid) داخل المنشآت التجارية والحيوية في البيئات الحضرية المكتظة، حيث يبرز التناقض الجوهري بين الحاجة الماسة لموثوقية طاقية عالية (تحديداً للمرافق المصرفية) وبين "المحدودية المكانية" والقيود الإنشائية لأسطح المبانـي. وتتجلى أبعاد هذه المشكلة في المحاور التقنية التالية:

1. **تدني كفاءة الاستغلال المساحي:** إن اتباع أنماط التثبيت التقليدية بمسافات بينية واسعة لتجنب التظليل المتبادل يؤدي إلى خسارة مساحية طاقية تتراوح بين $40\%$ و $50\%$ من مساحة الأسطح المتاحة، مما يحد من "القدرة المركبة" (Installed Capacity) للمنظومة.
2. **معضلة التظليل الموضعي:** تفرض العوائق المعمارية الموجودة على الأسطح (مثل غرف الدرج ووحدات التكييف المركزية) تحديات حرجة تتعلق بـ "فواقد عدم التطابق" (Mismatch Losses)، والتي تؤدي إلى انخفاض حاد وغير متناسب في القدرة المنتجة، وقد تسبب نشوء "البقع الساخنة" (Hotspots) التي تهدد سلامة الألواح.
3. **تعقيد المواءمة الكهربائية والمناخية:** يواجه المصمم صعوبة في مواءمة الخصائص الكهربائية للتقنيات الحديثة مع نوافذ الجهد التشغيلية للعواكس الذكية، خاصة تحت وطأة "الحالات الحرارية المتطرفة" صيفاً وشتاءً، مما قد يخرج المنظومة عن نطاق تتبع نقطة القدرة القصوى (MPPT).
4. **الفجوة بين التقدير النظري والأداء الفعلي:** تبرز الحاجة لتجاوز الحسابات اليدوية الساكنة نحو بناء "توأم رقمي" (Digital Twin) للمنظومة، يتيح التنبؤ الدقيق بمؤشرات الجدارة الطاقية مثل "معامل الأداء" (PR) وتحليل "مخطط تدفق المفاقيد" لضمان الجدوى الاقتصادية للمشروع قبل البدء بالتنفيذ.

بناءً على ما سبق، يسعى هذا البحث لتقديم حل هندسي مبتكر يعتمد تقنية "التثبيت المتدرج" (Terraced Mounting) والمواءمة الذكية مع العواكس متعددة المتعقبات لتجاوز هذه العقبات وتحقيق الاستقلال الطاقي المستدام للمنشأة.

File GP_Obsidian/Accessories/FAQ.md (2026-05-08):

## هل أضيف تصميم 3D بوساطة برنامج SketchUp ؟ وهل أعمل على تصميم إنشائي كامل للهيكل بواسطة برنامج [STAAD.pro](http://STAAD.pro) و AutoCAD ؟

بصراحة ومع **مدة أسبوعين فقط** لإنهاء مشروعك، يجب أن نفكر **بطريقة استراتيجية** وليس فقط بطريقة “زيادة محتوى”. الهدف هو أن يكون المشروع:

- قوي علمياً ✅
- واضح ومنظم ✅
- قابل للإنهاء خلال الوقت المتاح ✅

وليس مشروعاً ضخماً لا تستطيع إكماله.

---

### أولاً: تقييم الكورسين بالنسبة لمشروعك

#### الكورس الأول (تصميم المنظومة باستخدام SketchUp)

يتضمن:

- تصميم المنظومة ثلاثي الأبعاد
- تحليل الظلال
- تصميم الهيكل
- عرض بصري احترافي

الأدوات الأساسية فيه مثل SketchUp و إضافة Skelion.

##### فائدته لمشروعك

هذا الكورس **ممتاز لمشروع الطاقة الشمسية** لأنه يضيف:

1. **تصميم ثلاثي الأبعاد للمنظومة**
2. **تحليل الظلال (Shading Analysis)**
3. **إظهار المشروع بشكل احترافي**
4. صور جميلة يمكن وضعها في المشروع

وهذا النوع من المحتوى **غالباً يعجب المشرفين كثيراً**.

---

#### الكورس الثاني (تصميم الهيكل المعدني إنشائياً)

يتضمن:

- حساب الأحمال
- الكودات الهندسية
- حساب القواعد
- تحليل الهيكل

ويستخدم أدوات مثل AutoCAD و STAAD.Pro.

### فائدته لمشروعك

هذا الكورس **قوي جداً هندسياً** لكنه:

- أقرب إلى **الهندسة المدنية أو الإنشائية**
- يحتاج وقتاً للحسابات
- يحتاج شرح للكودات

وهذا قد **يأخذ وقتاً أكبر من اللازم لمشروعك**.

---

### ثانياً: نصيحتي الصريحة لك

مع **مدة أسبوعين** 👇

### الخيار الأفضل

اعمل على:

1️⃣ **تصميم المنظومة وتحليل الأداء باستخدام**

PVsyst

2️⃣ **إضافة تصميم ثلاثي الأبعاد باستخدام**

SketchUp

---

### لماذا هذا الخيار ذكي؟

لأن مشروعك سيحتوي على **ثلاثة أشياء قوية**:

1️⃣ **تصميم النظام الكهربائي**

(الألواح + العاكس)

2️⃣ **تحليل الأداء والمحاكاة**

باستخدام PVsyst

3️⃣ **تصميم ثلاثي الأبعاد وتحليل الظلال**

باستخدام SketchUp

وبذلك يصبح مشروعك:

**Design + Simulation + 3D Modeling**

وهذا **ممتاز جداً لمشروع تخرج**.

---

### ثالثاً: ماذا تفعل مع الكورس الثاني؟

لا أنصح أن تتعمق فيه الآن لأن:

- حساب الأحمال
- الكود الأمريكي
- تصميم القواعد

هذه قد **تأخذ وقت أسبوع كامل وحدها**.

لكن يمكنك فقط:

- رسم **الهيكل المعدني بشكل بسيط**
- ذكر الفكرة النظرية فقط

بدون تحليل إنشائي كامل.

---

### رابعاً: الشكل المثالي لمشروعك (القوي ولكن ممكن خلال أسبوعين)

الفصول ستكون:

### Chapter 1

Introduction

### Chapter 2

Solar Energy Fundamentals

### Chapter 3

PV System Design

### Chapter 4

Simulation using PVsyst

### Chapter 5

3D Modeling and Shading Analysis using SketchUp

### Chapter 6

Results and Discussion

### Chapter 7

Conclusion

---

### خامساً: سر صغير يجعل مشروعك أقوى بكثير

إذا أضفت في المشروع:

- **Loss Diagram من PVsyst**
- **Performance Ratio**
- **3D Layout للمنظومة**
- **Shading Analysis**

سيبدو مشروعك وكأنه **مشروع ماجستير وليس بكالوريوس**.

---

<aside>

✅ **الخلاصة:**

افعل هذا فقط:

- PVsyst لتحليل الأداء
- SketchUp لتصميم المنظومة وتحليل الظلال

ولا تدخل في **تصميم إنشائي كامل للهيكل** لأنه سيضيع الوقت.

</aside>

## متى نحتاج MATLAB أو ETAP؟

نستخدمها فقط إذا أردنا:

- تحليل **الاستقرار الكهربائي للشبكة**
- تحليل **تدفق القدرة (Load Flow)**
- تصميم **خوارزميات تحكم أو MPPT**

وهذا **غالباً خارج نطاق مشاريع البكالوريوس** في الطاقة الشمسية.

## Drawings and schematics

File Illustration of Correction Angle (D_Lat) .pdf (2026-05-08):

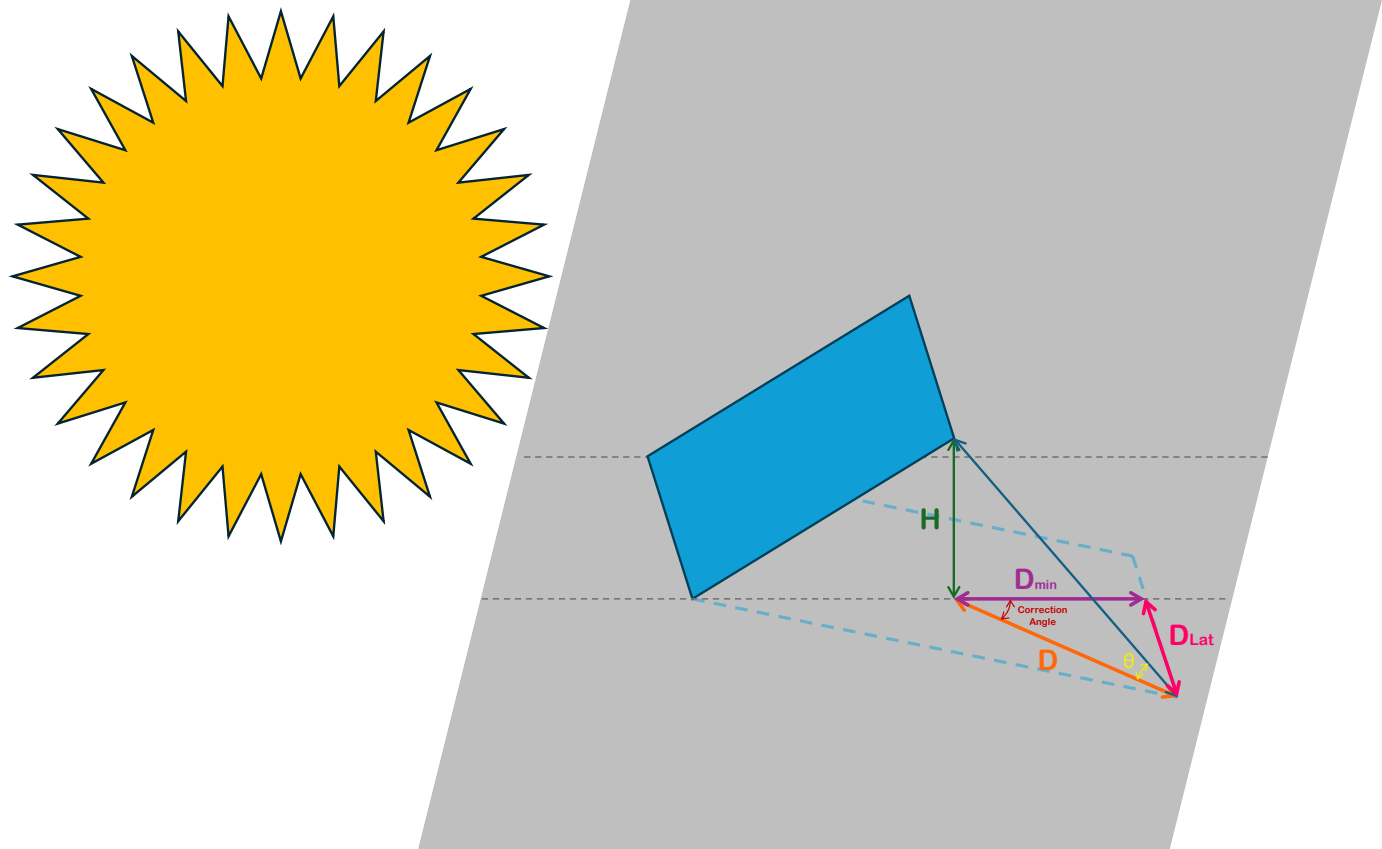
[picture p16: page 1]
Dmin; Correction Angle; DLa t

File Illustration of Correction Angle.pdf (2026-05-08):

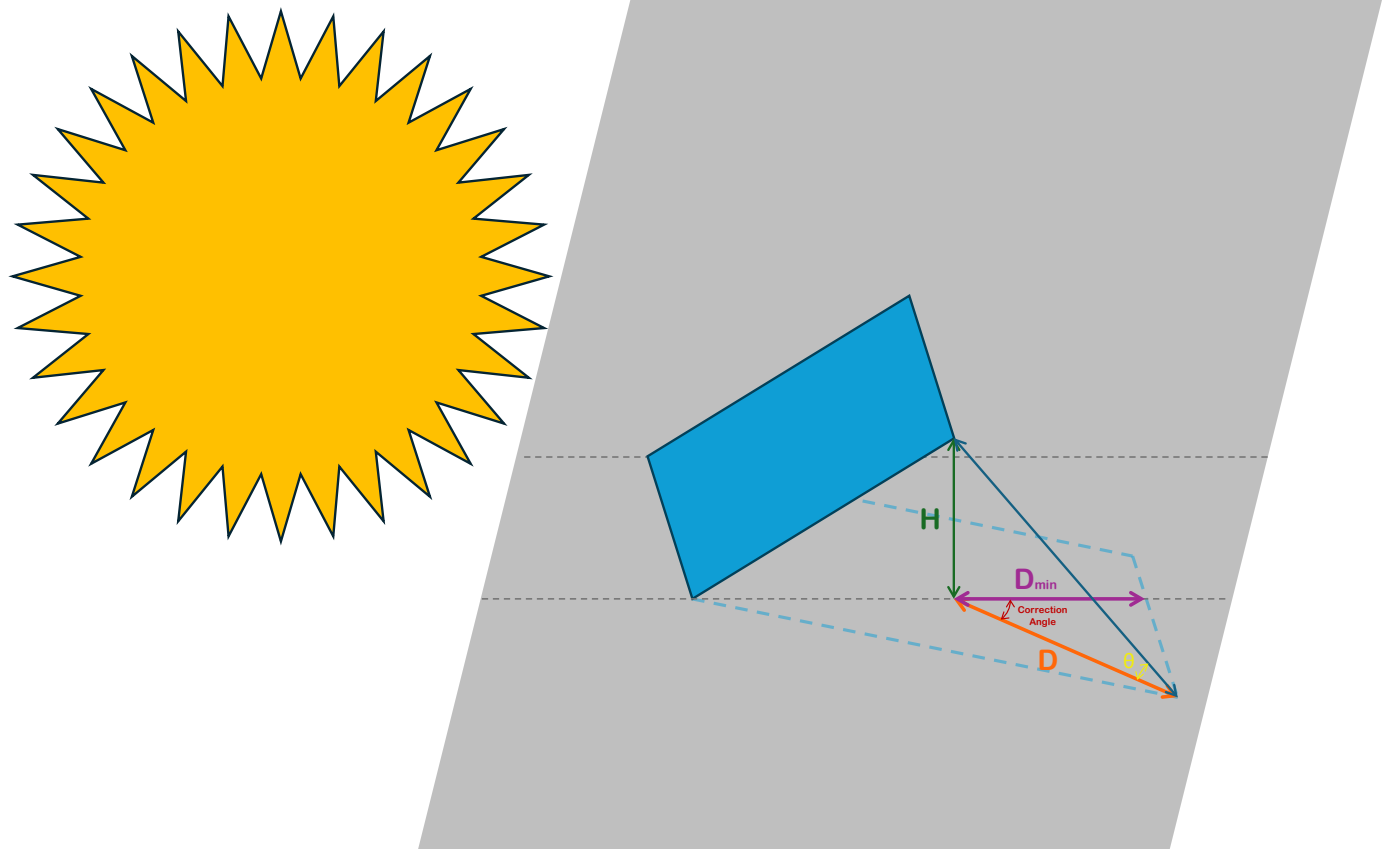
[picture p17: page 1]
Dmin; Correction Angle

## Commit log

2026-05-08 The first version of the gradution project
    [Bank - Copy.dwg, Bank Electrical Design.dwg, Bank.dwg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]
2026-05-08 I finished calculating the horizontal and lateral shadows, and drawing them in AutoCAD
    [Bank - Copy.dwg]
2026-05-14 I have arranged and rephrased the paragraphs related to PHS and Specific Yield
    [Bank - Copy.dwg, المواصفات الفنية للعاكس.xlsx, تقدير فواتير كهرباء البنك على مدار عام.xlsx]
2026-05-16 I'm still working on the shadows section
    [Bank - Copy.dwg, Bank - PV Power Design.dwg]
2026-05-16 I have finally finished analyzing and calculating the shadows
    [Bank - PV Power Design.dwg]
2026-05-24 Restructuring of chapters and addition of a new chapter (Chapter on Protections and Cables)
    [Bank - PV Power Design.dwg]
2026-05-29 Chapter 10 Done
    [Bank - PV Power Design - Copy.dwg]
2026-05-30 Some modifications on Chapter 10 and The SLD
    [Bank - PV Power Design - Copy.dwg]
2026-07-06 Start to convert the project from markdown to typst system
    [SLD.dwg]
2026-07-13 The Graduation Project DONE
    [Bank - PV Power Design.dwg, Bank Electrical Design.dwg, Bank.dwg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]
